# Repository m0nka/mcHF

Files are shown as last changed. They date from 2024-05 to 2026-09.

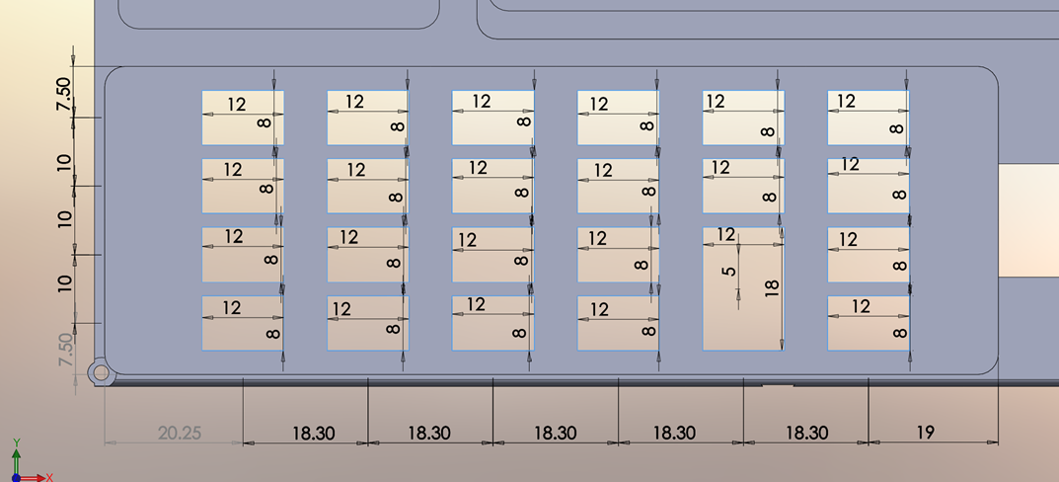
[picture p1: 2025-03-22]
mechanical/keypad/holder.png

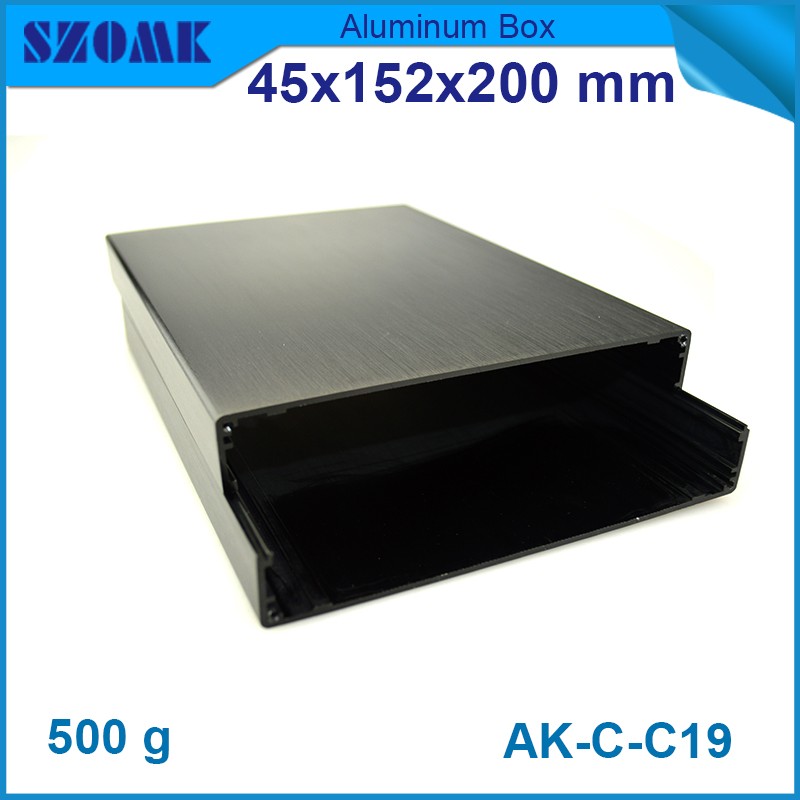
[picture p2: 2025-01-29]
mechanical/case/AK-C-C19/HTB1DIIQLXXXXXXDXXXXq6xXFXXXQ.jpg

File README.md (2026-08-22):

# mcHF — Open Source HF SDR Transceiver




The mcHF is a fully open source software defined radio transceiver for the HF amateur bands (3–30 MHz). Its goal is planet-wide, off-grid communication — ionosphere permitting — with no dependence on cellular or satellite infrastructure.

Both hardware and firmware build on the work of many radio amateurs. The design is modular, uses mostly off-the-shelf components that can be soldered by hand, and is straightforward to repair when something goes wrong. An amateur radio licence is required to transmit.

mcHF demonstration video (https://www.youtube.com/watch?v=7Q5eKNbZNY8)

## Features

- Transmit and receive on the 3–30 MHz amateur bands
- SSB, AM, FM and CW modes
- FT8 and WSPR digital mode decoding (in development)
- Real-time spectrum scope and waterfall
- Large 4.3" IPS LCD with capacitive touch
- 25 W output power
- Built-in 80 Wh lithium battery
- Dual USB-C ports for power, charging and PC connection
- Bluetooth stereo headphone support
- LoRa sub-GHz auxiliary radio

## Hardware

The radio is built around an STM32H747BIT6 dual-core MCU: the Cortex-M7 (480 MHz) runs the user interface and system control, while the Cortex-M4 handles the real-time DSP (demodulation, AGC, filtering, spectrum FFT).

### Altium PCB project files

| Status  | Version | Location |
|---|---|---|
| Latest  | 0.9 rev B  | [pcb/v9](./pcb/v9) |
| Develop | 0.8.5 | [pcb/v8/mchf](./pcb/v8/mchf) |
| Legacy  | 0.6.3 | [pcb/__legacy/v6](./pcb/__legacy/v6) |

### PCB gerbers

| Revision | Version | Location |
|---|---|---|
| rev 8 | 0.8.5 | [testing/gerbers/0_8_5](./testing/gerbers/0_8_5) |
| rev 7 | 0.7.0 | [pcb/__legacy/bin/v7](./pcb/__legacy/bin/v7) |
| rev 6 | 0.6.3 | [pcb/__legacy/bin/v6](./pcb/__legacy/bin/v6) |

## Repository layout

| Directory | Contents |
|---|---|
| [firmware](./firmware) | All firmware projects (see below) |
| [pcb](./pcb) | Altium PCB projects and gerbers |
| [mechanical](./mechanical) | Enclosure and mechanical design files |
| [testing](./testing) | Test data and manufacturing files |

## Building the firmware

The firmware is developed with [STM32CubeIDE](https://www.st.com/en/development-tools/stm32cubeide.html) (Eclipse CDT managed build — no separate Makefiles).

Clone with submodules (the ST HAL and the FT8 library are pulled in as git submodules):

```
git clone --recurse-submodules https://github.com/m0nka/mcHF.git
```

There are three independent firmware projects, each opened separately in STM32CubeIDE:

| Project | Core | Location |
|---|---|---|
| Application processor (UI, control) | CM7 | [firmware/app_proc/proj](./firmware/app_proc/proj) |
| Baseband DSP | CM4 | [firmware/baseband](./firmware/baseband) |
| Bootloader | CM7 | [firmware/bootloader](./firmware/bootloader) |

Open the project's `.project` file in STM32CubeIDE and use *Build → Build Project*. The application processor build produces `firmware/app_proc/proj/Release/mchf_app_proc.bin`, which can be flashed over SWD with `program_radio.bat` (requires STM32CubeProgrammer).

## Previous hardware generations

Older mcHF hardware versions are supported by the community-maintained UHSDR firmware:

- Firmware repository: [df8oe/UHSDR](https://github.com/df8oe/UHSDR)
- Project crash course and documentation: [UHSDR wiki](https://github.com/df8oe/UHSDR/wiki)

## Community and contributing

Questions, build reports and development discussion are welcome in the [mcHF discussion group](https://groups.io/g/mcHF/).

Feel free to build one yourself and contribute — bug reports, fixes and improvements to hardware, firmware or documentation are all appreciated.

## License

mcHF is licensed under the [GNU General Public License v3.0](LICENSE).

Copyright © 2013–2026 Krassi Atanassov, M0NKA

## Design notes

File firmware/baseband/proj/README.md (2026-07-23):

Introduction 

This directory contains the STM32CubeIDE project (mchf_baseband) for the CM4 baseband core,
based on the UHSDR firmware (sources in firmware/baseband)

Import into STM32CubeIDE

- In the File menu, select 'Open Projects from File System...'
- Select root directory: "firmware\baseband\proj", 'Detect and configure project natures' selected
- Click Finish

Note: SystemWorks no longer supported!

Troubleshooting

- Fix for functions with wrong inline definition - use optimization (O1 at least), more info:
	https://stackoverflow.com/questions/41218006/gcc-fails-to-inline-functions-without-o2

For any problems compiling under windows please open an issue report on the project GitHub page.

Thank you!

Krassi Atanassov, M0NKA

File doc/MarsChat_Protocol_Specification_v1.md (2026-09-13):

# MarsChat — On-Air Protocol Specification

**Version:** 1.0  
**Date:** 30 August 2026  
**Author:** Krassi Atanassov, M0NKA  
**Platform:** mcHF QRP Transceiver v9  
**Licence:** GPLv3  
**Repository:** https://github.com/m0nka/mcHF

---

## 1. Purpose and Regulatory Notice

MarsChat is a very-slow-baud, text-only digital communication mode for HF
amateur radio, designed for extreme weak-signal messaging over ionospheric
paths. It trades throughput for reach: a single text character takes
approximately 24 seconds of on-air time, but the link closes at signal-to-noise
ratios of **−28 dB or better** in a 2500 Hz reference bandwidth — well below
the noise floor, where voice and conventional digital modes cannot operate.

This document is published in compliance with amateur radio practice that
requires open documentation of new on-air modes, enabling any station to decode
MarsChat transmissions. **No encryption is used in amateur (ham) mode.** The
on-air modulation is standard WSPR; only the interpretation of the 50
information bits differs.

The name "MarsChat" refers to the multi-minute message turnaround inherent to
the mode, reminiscent of Earth–Mars radio dialogue latency. It is not affiliated
with any space agency or Mars mission.

---

## 2. Overview

MarsChat reuses the **WSPR (Weak Signal Propagation Reporter)** physical layer
without modification. The 4-FSK modulation, convolutional FEC, interleaving,
synchronisation vector and timing are identical to WSPR type-1. Only the meaning
of the **50 information bits** carried within the WSPR frame changes.

This design choice means:
- Any existing WSPR decoder can demodulate MarsChat signals at the RF level.
- The same convolutional code and Fano sequential decoder recovers the 50 raw
  bits from noise.
- MarsChat then applies its own frame interpretation (described in §4–§8) to
  those 50 bits.

**Throughput:** 5 characters per 120-second slot, or approximately 0.42 bits
per second. A whole canned phrase can be transmitted in a single slot via the
phrase lookup table (§7.2).

---

## 3. Physical Layer (WSPR, Unchanged)

All PHY parameters are standard WSPR type-1 as defined by Joe Taylor, K1JT.

| Parameter | Value |
|---|---|
| Modulation | 4-FSK, continuous phase |
| Number of symbols | 162 |
| Symbol rate | 12000 / 8192 ≈ 1.46484375 baud |
| Tone spacing | 375 / 256 ≈ 1.46484375 Hz |
| Occupied bandwidth | ≈ 6 Hz |
| Transmission duration | 162 × 8192 / 12000 ≈ 110.6 seconds |
| Slot period | 120 seconds, aligned to even UTC minutes |
| TX start | Slot boundary + 1.0 second |
| Audio centre frequency | Dial frequency + 1500 Hz (USB) |
| FEC | K = 32, rate = 1/2, non-recursive convolutional code |
| Sequential decoder | Fano algorithm |
| Interleaving | Bit-reversal permutation over 256 indices |
| Sync vector | Standard WSPR 162-bit pseudo-random sequence |
| Information payload | **50 bits** |

### 3.1 Encoding Chain (Transmit)

```
50 information bits
  → append 31 zero tail bits (flush the K = 32 shift register) = 81 bits
  → K = 32, r = 1/2 convolutional encode = 162 coded bits
      polynomials: G1 = 0xF2D05351, G2 = 0xE4613C47
      convention:  MSB-first feed, coded bit = even parity of (state AND poly)
  → bit-reversal interleave over 256 indices (skip indices ≥ 162)
  → channel symbol[k] = sync_vector[k] + 2 × coded_bit[k]
  → 162 four-level symbols (values 0, 1, 2, 3)
  → 4-FSK audio: tone[k] = 1500 + (symbol[k] − 1.5) × 1.46484375 Hz
```

### 3.2 Decoding Chain (Receive)

Standard WSPR decoding: FFT search → candidate detection → fine sync →
demodulation → de-interleave → Fano sequential decode → 50 raw bits + SNR,
time offset (dt), frequency, and drift metadata per decode.

### 3.3 Dial Frequencies (Ham Mode)

MarsChat transmissions in ham mode use the standard WSPR dial frequencies (USB
carrier):

| Band | Dial Frequency (Hz) |
|---|---|
| 160 m | 1,836,600 |
| 80 m | 3,568,600 |
| 60 m | 5,287,200 |
| 40 m | 7,038,600 |
| 30 m | 10,138,700 |
| 20 m | 14,095,600 |
| 17 m | 18,104,600 |
| 15 m | 21,094,600 |
| 12 m | 24,924,600 |
| 10 m | 28,124,600 |

The 4-FSK tones are centred at dial + 1500 Hz within the 200 Hz WSPR sub-band.

---

## 4. Frame Format (50 Bits)

The 50 information bits are packed MSB-first into 7 bytes (the low 6 bits of
byte 6 are unused). Bit numbering: `b0` is the MSB of byte 0.

```
 b0    b1..b2   b3..b5   b6..b8   b9..b11   b12..b41      b42..b49
┌────┬────────┬────────┬────────┬─────────┬─────────────┬──────────┐
│ MC │ FTYPE  │  SEQ   │  ACK   │  FLAGS  │  PAYLOAD    │  CRC-8   │
│ =1 │ 2 bits │ 3 bits │ 3 bits │ 3 bits  │  30 bits    │  8 bits  │
└────┴────────┴────────┴────────┴─────────┴─────────────┴──────────┘

Total: 1 + 2 + 3 + 3 + 3 + 30 + 8 = 50 bits
```

### 4.1 Field Definitions

| Field | Width | Description |
|---|---|---|
| `MC` | 1 bit | MarsChat marker. Always **1**. Used for frame discrimination (§5). |
| `FTYPE` | 2 bits | Frame type: 0 = BEACON, 1 = DATA, 2 = ACK, 3 = CTRL |
| `SEQ` | 3 bits | Frame sequence number, modulo 8 |
| `ACK` | 3 bits | Sequence number of the last correctly received peer frame. 0 if not applicable |
| `FLAGS` | 3 bits | Bit field: bit 0 = `OTP` (encrypted, non-amateur only), bit 1 = `MF` (more fragments follow), bit 2 = `CYR` (Cyrillic rendering hint) |
| `PAYLOAD` | 30 bits | 5 × 6-bit character codes (§7), or type-specific content (§6) |
| `CRC` | 8 bits | CRC-8 integrity check over b0..b41 (§4.2) |

### 4.2 Bit Packing (Byte Layout)

The bit-to-byte mapping, as implemented:

```
byte 0:  b0=MC(1)  b1-b2=FTYPE  b3-b5=SEQ  b6-b7=ACK[2:1]
byte 1:  b8=ACK[0]  b9=OTP  b10=MF  b11=CYR  b12-b15=PAYLOAD_CODE0[5:2]
byte 2:  b16-b17=PAYLOAD_CODE0[1:0]  b18-b23=PAYLOAD_CODE1[5:0]
byte 3:  b24-b29=PAYLOAD_CODE2[5:0]  b30-b31=PAYLOAD_CODE3[5:4]
byte 4:  b32-b35=PAYLOAD_CODE3[3:0]  b36-b37=PAYLOAD_CODE4[5:4]  (note: only top 2 bits)
         (correction: b32-b35=CODE3[3:0]  b36-b39=CODE4[5:2])
byte 5:  b40-b41=PAYLOAD_CODE4[1:0]  b42-b47=CRC[7:2]
byte 6:  b48-b49=CRC[1:0]  b50-b55=unused(0)
```

Precise implementation (C, canonical reference):

```c
// Pack
bits50[0] = 0x80
          | ((ftype & 0x03) << 5)
          | ((seq   & 0x07) << 2)
          | ((ack   & 0x07) >> 1);

bits50[1] = ((ack   & 0x01) << 7)
          | ((flags & 0x01) ? 0x40 : 0)   // OTP
          | ((flags & 0x02) ? 0x20 : 0)   // MF
          | ((flags & 0x04) ? 0x10 : 0)   // CYR
          | ((codes[0] & 0x3F) >> 2);

bits50[2] = ((codes[0] & 0x03) << 6) | (codes[1] & 0x3F);
bits50[3] = ((codes[2] & 0x3F) << 2) | ((codes[3] & 0x3F) >> 4);
bits50[4] = ((codes[3] & 0x0F) << 4) | ((codes[4] & 0x3F) >> 2);
bits50[5] = ((codes[4] & 0x03) << 6);

// CRC-8 over b0..b41 (bytes 0..5, with byte 5 low 6 bits masked to 0)
crc = crc8_autosar(bits50[0..4], bits50[5] & 0xC0);

bits50[5] |= (crc >> 2);
bits50[6]  = (crc & 0x03) << 6;
```

---

## 5. Frame Discrimination (MarsChat vs WSPR)

A receiver that supports both WSPR and MarsChat classifies each raw 50-bit
decode as follows:

1. If bit `b0` (MSB of byte 0) is **1** AND the MarsChat CRC-8 (§4.3)
   verifies → interpret as a **MarsChat** frame.
2. Otherwise → attempt standard WSPR type-1 unpack (callsign + grid + power).

**False classification probability** of a genuine WSPR spot as MarsChat: the
WSPR type-1 callsign encoding uses the MSB for the first character of the
padded callsign. Approximately half of valid WSPR messages will have `b0 = 1`,
but the CRC-8 must also pass (probability ≈ 1/256), giving an overall false
positive rate of approximately **2⁻⁹ ≈ 0.2%**. This is acceptable at typical
WSPR decode rates.

A MarsChat frame is never a valid WSPR type-1 message by construction
(probabilistically — the callsign decode would be nonsensical).

---

## 6. CRC-8

**Algorithm:** CRC-8/AUTOSAR

| Parameter | Value |
|---|---|
| Polynomial | 0x2F (x⁸ + x⁵ + x³ + x² + x + 1) |
| Initial value | 0xFF |
| Final XOR | 0xFF |
| Input reflection | No |
| Output reflection | No |

**Scope:** The CRC is computed over bits `b0` through `b41` of the frame
(the MC marker, FTYPE, SEQ, ACK, FLAGS and PAYLOAD fields). The input is
packed MSB-first into 6 bytes; the last byte contains `b40` and `b41` in
its two MSBs with the low 6 bits forced to zero.

**Verification:** A receiver computes the CRC over the same 6-byte span and
compares it against the received CRC in bits `b42..b49`. Mismatch means the
frame is not a valid MarsChat frame and should be tested as WSPR type-1.

**Reference implementation** (C):

```c
uint8_t mc_crc8(const uint8_t *data, int len)
{
    uint8_t crc = 0xFF;
    int     i, b;

    for (i = 0; i < len; i++)
    {
        crc ^= data[i];

        for (b = 0; b < 8; b++)
        {
            if (crc & 0x80)
                crc = (uint8_t)((crc << 1) ^ 0x2F);
            else
                crc = (uint8_t)(crc << 1);
        }
    }

    return crc ^ 0xFF;
}
```

**Test vectors:**

| Input (hex) | CRC-8 |
|---|---|
| `00` | 0x12 |
| `FF` | 0xC2 |
| `00 00 00 00 00 00` (6 bytes) | (implementation-defined, verify against reference) |

---

## 7. Character Set and Phrase Lookup Table

### 7.1 Six-Bit Character Set (Latin Page)

All text is case-insensitive (uppercase only), consistent with CW and digital
mode convention. Each character is encoded as a 6-bit value (0–63). Five
characters fit in the 30-bit payload field.

| Code | Character | Code | Character | Code | Character | Code | Character |
|---|---|---|---|---|---|---|---|
| 0 | END (pad) | 16 | P | 32 | 5 | 48 | ' (apostrophe) |
| 1 | A | 17 | Q | 33 | 6 | 49 | ( |
| 2 | B | 18 | R | 34 | 7 | 50 | ) |
| 3 | C | 19 | S | 35 | 8 | 51 | " (double quote) |
| 4 | D | 20 | T | 36 | 9 | 52 | # |
| 5 | E | 21 | U | 37 | SPACE | 53 | $ |
| 6 | F | 22 | V | 38 | . (period) | 54 | % |
| 7 | G | 23 | W | 39 | , (comma) | 55 | & |
| 8 | H | 24 | X | 40 | ? | 56 | * |
| 9 | I | 25 | Y | 41 | ! | 57 | ; |
| 10 | J | 26 | Z | 42 | / | 58 | < |
| 11 | K | 27 | 0 | 43 | - (hyphen) | 59 | > |
| 12 | L | 28 | 1 | 44 | + | 60 | (reserved) |
| 13 | M | 29 | 2 | 45 | = | 61 | SHIFT (reserved) |
| 14 | N | 30 | 3 | 46 | @ | 62 | ESC |
| 15 | O | 31 | 4 | 47 | : (colon) | 63 | (reserved) |

**Special codes:**

- **Code 0 (END):** Terminates text early within a fragment. Remaining
  positions are padding (filled with 0) and are excluded from display.
- **Code 62 (ESC):** The next 6-bit code is a phrase lookup table index (§7.2).
- **Code 63:** Reserved for future protocol version escape. If code 63 appears
  as the **first** payload code in a cleartext frame, v1 receivers must discard
  the frame.
- **Code 61 (SHIFT):** Reserved for future mixed-script support.

### 7.2 Phrase Lookup Table (ESC Expansion)

Code 62 (`ESC`) followed by a phrase index (0–15) expands to a complete phrase,
allowing an entire sentence to be sent in a single 120-second slot. This table
is versioned with this protocol specification — both stations must run the same
version (no on-air LUT negotiation in v1).

| Index | Expansion | Index | Expansion |
|---|---|---|---|
| 0 | HEY | 8 | YES |
| 1 | HOW COPY? | 9 | NO |
| 2 | GOING OFF AIR | 10 | STANDBY |
| 3 | SIGNAL WEAK | 11 | MOVING FREQ |
| 4 | SIGNAL STRONG | 12 | SEND AGAIN |
| 5 | ALL OK | 13 | INTERFERENCE HERE |
| 6 | NEED HELP | 14 | BACK IN 1 HOUR |
| 7 | LOCATION UNCHANGED | 15 | BACK TOMORROW SAME TIME |

Indices 16–63 are reserved; receivers must ignore unknown indices.

**Example:** The payload codes `[62, 2, 0, 0, 0]` decode as "GOING OFF AIR"
(ESC + index 2, followed by END padding).

**Effective throughput:** Plain text delivers 5 characters per 2-minute slot.
With phrase LUT, a whole sentence fits in one slot.

### 7.3 Cyrillic Rendering Page (FLAGS.CYR)

When `FLAGS` bit 2 (`CYR`) is set to 1, the **same on-air codes** are displayed
using Cyrillic glyphs instead of Latin. This is a pure rendering hint — the
encoding, CRC, LUT mechanics and everything else are identical. The mapping
follows the traditional **Bulgarian Phonetic keyboard layout:**

| Code | Latin | Cyrillic | Code | Latin | Cyrillic | Code | Latin | Cyrillic |
|---|---|---|---|---|---|---|---|---|
| 1 | A | А | 10 | J | Й | 19 | S | С |
| 2 | B | Б | 11 | K | К | 20 | T | Т |
| 3 | C | Ц | 12 | L | Л | 21 | U | У |
| 4 | D | Д | 13 | M | М | 22 | V | Ж |
| 5 | E | Е | 14 | N | Н | 23 | W | В |
| 6 | F | Ф | 15 | O | О | 24 | X | Ь |
| 7 | G | Г | 16 | P | П | 25 | Y | Ъ |
| 8 | H | Х | 17 | Q | Я | 26 | Z | З |
| 9 | I | И | 18 | R | Р | | | |

Four additional Bulgarian letters overlay punctuation codes when `CYR = 1`:

| Code | Latin Page | Cyrillic Page |
|---|---|---|
| 52 | # | Ч |
| 53 | $ | Ш |
| 54 | % | Щ |
| 55 | & | Ю |

This covers the full 30-letter Bulgarian alphabet. Digits, space and all other
punctuation codes are unchanged on both pages.

`CYR` is per-frame: every fragment of a multi-frame message carries its own
rendering hint, so a lost fragment cannot flip the rendering of later ones.

---

## 8. Frame Types and Payload Semantics

### 8.1 BEACON (FTYPE = 0)

One-way text transmission, no session or ARQ. Used for beacons and initial
testing.

- `SEQ` increments per transmitted frame (modulo 8).
- `ACK` = 0 (not applicable).
- `PAYLOAD` = 5 six-bit character codes (§7.1).
- Multi-frame text uses `FLAGS.MF = 1` and `SEQ` ordering. The receiver
  concatenates fragments until a frame with `MF = 0` arrives.
- Lost fragments are rendered as placeholder gaps (no retry mechanism).

### 8.2 DATA (FTYPE = 1)

Text with ARQ (Automatic Repeat reQuest) semantics (§9).

- Same text payload as BEACON.
- `ACK` carries the `SEQ` of the last correctly received peer frame,
  acknowledging it.
- Un-acknowledged frames are retried in the sender's next slot (§9).

### 8.3 ACK (FTYPE = 2)

Keep-alive frame when no text is pending. Maintains the link and reports
receive-side signal quality:

```
PAYLOAD (30 bits):
  [ snr + 32  : 6 bits ]   SNR in dB, clamped to −32..+31
  [ |dt| × 4  : 6 bits ]   time offset magnitude in seconds × 4, clamped 0..15.75
  [ drift + 32 : 6 bits ]  frequency drift in Hz × 10, clamped
  [ reserved   : 12 bits ]  set to 0
```

This gives each station propagation feedback for manual (or future scripted)
band and power decisions.

### 8.4 CTRL (FTYPE = 3)

Control frames for protocol signalling:

```
PAYLOAD (30 bits):
  [ opcode : 6 bits ]
  [ arg    : 24 bits ]
```

| Opcode | Name | Argument |
|---|---|---|
| 0 | PING | Echo token (24 bits) |
| 1 | TIME_SYNC | Sender's slot index, low 24 bits |
| 2 | OTP_SYNC | OTP counter, low 24 bits (non-amateur mode only) |
| 3 | SCRIPT_NEXT | Reserved for frequency hopping scripts |
| 4–63 | (reserved) | Receivers must ignore unknown opcodes |

---

## 9. ARQ Protocol (Stop-and-Wait)

The ARQ protocol applies to DATA, ACK and CTRL frame types. BEACON frames are
fire-and-forget.

### 9.1 Slot Ownership

Stations alternate 120-second slots. The **slot index** is defined as:

```
slot_index = floor(UTC_minutes / 2)
```

The station initiating the chat ("caller") owns **even** slot indices; the peer
owns **odd** slot indices. A station transmits only in its own slots and listens
only in the peer's slots. An hour contains 30 slots (even count), so the
alternation runs unbroken across hour boundaries.

### 9.2 Stop-and-Wait Operation

- Each side has **at most one un-acknowledged frame** in flight at a time.
- A frame is retried in the sender's next own slot (same SEQ, identical
  on-air bits) until an `ACK` field acknowledging that SEQ is received.
- **Retry limit:** 5 transmissions. After 5 unacknowledged attempts, the frame
  is dropped and the application is notified.
- **Sequence space:** Modulo 8 with a window of 1. SEQ also orders fragments
  for multi-frame message reassembly.

### 9.3 Idle Behaviour

When a station in an active session has nothing to send, it transmits ACK
frames (FTYPE = 2) in its own slots as keep-alives with link quality reports.

### 9.4 Session Loss

The session is considered lost after **5 consecutive empty peer slots** (no
decoded frame from the peer in 5 listening opportunities ≈ 20 minutes of
silence).

### 9.5 Timing

| Event | Timing |
|---|---|
| Best case, single 5-char message | 4 minutes (TX slot + peer ACK slot) |
| Multi-fragment sentence with a retry | 10–20 minutes |
| Maximum silence before session loss | ≈ 20 minutes (5 × 4-minute cycles) |

---

## 10. Time Synchronisation

Frames must start at even-minute boundaries + 1.0 second, within approximately
±2 seconds (the decoder's time-offset search window).

### 10.1 Preferred Synchronisation Methods (in order)

1. **GPS time fix:** Power the GPS receiver at session start, take an NMEA time
   fix, set the slot epoch, and power the GPS down to save battery. Cold-fix
   time is acceptable given the 2-minute slot cadence.

2. **TCXO free-run:** Between GPS fixes, slot phase is maintained by a timer
   derived from the 25 MHz TCXO domain. At ±2.5 ppm the ±2 s window holds
   for approximately 9 days; at ±25 ppm, for approximately 22 hours.

3. **On-air lock (no GPS):** The un-synced station receives continuously. Each
   decoded frame yields a time offset `dt`. The station steps its slot clock by
   `−dt` and confirms slot-index parity with a `CTRL TIME_SYNC` exchange.
   Subsequent decodes continuously re-trim the phase — at 2-minute intervals,
   even 25 ppm mutual drift moves `dt` by only ≈ 6 ms per slot.

### 10.2 Frequency Accuracy

The TCXO also determines dial frequency accuracy. At 14 MHz, ±25 ppm is
±350 Hz — outside the decoder's ±110 Hz search window. Mitigations:

1. One-time calibration against a known WSPR station (free frequency reference
   on air) or a GPS-disciplined counter.
2. For first contact between uncalibrated radios, widen the RX search window
   and apply the measured offset as a correction factor.

---

## 11. Station Identification (Ham Mode)

Because the MarsChat payload is not standard WSPR, transmissions must carry
station identification to remain identifiable and legal on amateur bands.

**CW ID:** After the 162-symbol 4-FSK transmission ends at approximately
111.6 seconds into the 120-second slot, the station's callsign is keyed in
Morse code (CW) at ≥ 20 WPM in the remaining ≈ 8-second gap. The CW is sent
at the same dial frequency and at no higher power than the data transmission.

- A 6-character callsign at 25 WPM takes approximately 5 seconds.
- **If no callsign is configured, ham-mode TX is refused** — the radio will not
  key without a valid callsign.

### 11.1 CW Timing

Standard International Morse timing:

| Element | Duration |
|---|---|
| Dot | 1 unit |
| Dash | 3 units |
| Inter-element gap | 1 unit |
| Inter-character gap | 3 units |
| 1 unit at 25 WPM | 1.2 / 25 = 48 ms |

The CW tone is keyed at the same audio frequency as the data tones (≈ 1500 Hz)
with 5 ms raised-cosine envelope edges to minimise key clicks.

---

## 12. Protocol Versioning

Protocol version 1 is defined by the `MC` marker bit being 1. Future versions
use an in-band escape: if character code 63 appears as the **first** payload
code in a cleartext frame, the frame uses a future extended format. Version 1
receivers **must discard** such frames.

---

## 13. Decoding a MarsChat Frame — Step by Step

This section provides a complete procedure for decoding a MarsChat transmission,
suitable for independent implementation.

### Step 1: Receive and Demodulate

Tune to a WSPR dial frequency (§3.3), mode USB. Run a standard WSPR decoder on
the audio to recover the 50 raw information bits (packed as 7 bytes, MSB-first).
Any WSPR decoder that exposes the raw 50-bit payload before type-1 callsign
interpretation is suitable.

### Step 2: Frame Discrimination

1. Check bit `b0` (MSB of byte 0). If `b0 = 0`, this is not a MarsChat frame —
   pass it to the WSPR type-1 unpacker.
2. Compute CRC-8/AUTOSAR (§6) over bits `b0..b41` (bytes 0–5, with byte 5 low
   6 bits masked to 0).
3. Extract the received CRC from bits `b42..b49`:
   `crc_rx = ((byte5 & 0x3F) << 2) | ((byte6 >> 6) & 0x03)`
4. If `crc_rx ≠ crc_computed`, this is not a valid MarsChat frame — try WSPR.

### Step 3: Unpack Fields

Extract the frame fields from the 7-byte array using the bit layout in §4.2.

### Step 4: Decode Text

For BEACON and DATA frames (FTYPE 0 or 1):
1. Interpret the 5 six-bit codes from the PAYLOAD field using the character
   table in §7.1.
2. If `FLAGS.CYR = 1`, use the Cyrillic rendering table in §7.3 instead.
3. If a code is 62 (ESC), the next code is a phrase LUT index — expand it using
   the table in §7.2.
4. If a code is 0 (END), stop — remaining codes are padding.
5. If `FLAGS.MF = 1`, this is one fragment of a longer message — concatenate
   with subsequent frames (ordered by SEQ) until a frame with `MF = 0` arrives.

For ACK frames (FTYPE 2), decode the signal report from the PAYLOAD (§8.3).
For CTRL frames (FTYPE 3), decode the opcode and argument (§8.4).

---

## 14. Encoding a MarsChat Frame — Step by Step

### Step 1: Prepare the Frame

1. Set `MC = 1`.
2. Set `FTYPE` (0–3) for the intended frame type.
3. Set `SEQ` to the current frame sequence number (mod 8).
4. Set `ACK` to the last received peer sequence number (0 if none).
5. Set `FLAGS` as appropriate (`MF` for multi-fragment, `CYR` for Cyrillic).
6. Encode up to 5 text characters into 6-bit codes using §7.1.

### Step 2: Pack and CRC

Pack the fields into 7 bytes per the layout in §4.2. Compute CRC-8 over
bytes 0–5 (with byte 5 low 6 bits masked), and write the CRC into bits
`b42..b49`.

### Step 3: Channel Encode and Transmit

Pass the 7-byte packed frame to the WSPR encoding chain (§3.1) to produce 162
four-level symbols. Transmit as 4-FSK starting at even-minute + 1.0 second.

### Step 4: CW ID (Ham Mode)

After the 162-symbol stream ends (≈ 111.6 s), key the station callsign in CW
at ≥ 20 WPM (§11).

---

## 15. Reference Test Vector

**Input:** The text "HELLO" as a BEACON frame (FTYPE = 0, SEQ = 0, ACK = 0,
FLAGS = 0).

Character encoding:
```
H = 8, E = 5, L = 12, L = 12, O = 15
```

Packed 50-bit frame (7 bytes, hex):
```
MC=1, FTYPE=00, SEQ=000, ACK=000, FLAGS=000
PAYLOAD codes: [8, 5, 12, 12, 15]
CRC-8 computed over b0..b41

Byte-by-byte construction:
  byte 0: 1_00_000_00 = 0x80
  byte 1: 0_0_0_0_0010 = 0x02  (ack[0]=0, OTP=0, MF=0, CYR=0, code0[5:2]=0010)
  byte 2: 00_000101 = 0x05     (code0[1:0]=00, code1=000101)
  byte 3: 001100_00 = 0x30     (code2=001100, code3[5:4]=00)
  byte 4: 1100_0011 = 0xC3     (code3[3:0]=1100, code4[5:2]=0011)
  byte 5: 11_xxxxxx = 0xC0 | crc_high  (code4[1:0]=11, then CRC bits)
  byte 6: xx_000000 = crc_low << 6

Pre-CRC bytes: 80 02 05 30 C3 C0
CRC-8/AUTOSAR of [80 02 05 30 C3 C0] = (compute to verify)
```

Implementers should compute the CRC-8 of the byte sequence `[0x80, 0x02, 0x05,
0x30, 0xC3, 0xC0]` using the algorithm in §6 and verify it matches the bits
placed in `b42..b49` of the complete frame. This serves as the primary
interoperability test: if your encoder produces the same 7 bytes for "HELLO"
as the reference, and your decoder recovers "HELLO" from them, the
implementation is correct.

---

## 16. Glossary

| Term | Definition |
|---|---|
| ARQ | Automatic Repeat reQuest — error correction by retransmission |
| CW | Continuous Wave — Morse code |
| dt | Time offset of a decoded frame relative to the expected slot start |
| Fano | Sequential decoding algorithm used by WSPR |
| FEC | Forward Error Correction |
| FSK | Frequency Shift Keying |
| LUT | Lookup Table |
| MF | More Fragments (flag indicating a multi-frame message continues) |
| OTP | One-Time Pad (non-amateur mode only) |
| PHY | Physical layer |
| SEQ | Sequence number |
| Slot | One 120-second transmission/reception period |
| SNR | Signal-to-Noise Ratio |
| TCXO | Temperature-Compensated Crystal Oscillator |
| USB | Upper Side Band |
| WSPR | Weak Signal Propagation Reporter |

---

## 17. References

1. K1JT, J. Taylor, "The WSPR Protocol," 2008.
   https://www.physics.princeton.edu/pulsar/k1jt/wspr.html
2. K9AN, S. Franke, "wsprd — WSPR decoder," part of WSJT-X.
   https://sourceforge.net/projects/wsjt/
3. mcHF SDR Transceiver project.
   https://github.com/m0nka/mcHF
4. CRC-8/AUTOSAR specification.
   Polynomial 0x2F, per AUTOSAR E2E Profile 2.

---

*This document is published under the GNU General Public License v3.0 to
satisfy the amateur radio community requirement that new digital modes be
openly documented. Anyone may implement a MarsChat encoder or decoder using this
specification.*

*Document revision history:*

| Version | Date | Changes |
|---|---|---|
| 1.0 | 2026-08-30 | Initial public release |

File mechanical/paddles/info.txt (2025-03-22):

Notes: As we don't have solidworks files for both files from the original author, we kinda
reuse them as it is, and made the right panel enclosure accomodate the existing design.

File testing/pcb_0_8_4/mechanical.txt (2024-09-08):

- fan cap to have redirect holes to cool batteries during charge( < 10% of flow)

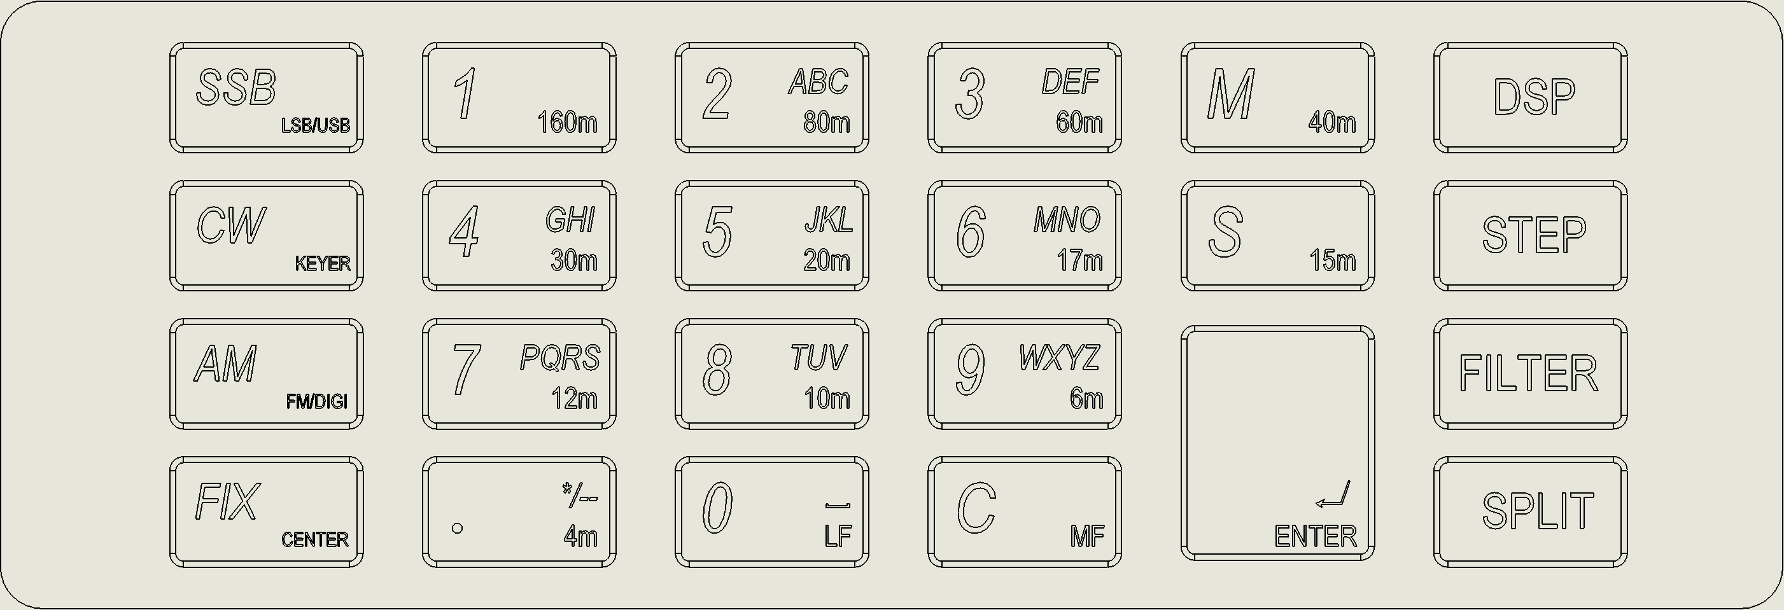
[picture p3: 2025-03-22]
mechanical/keypad/img/keypad.png

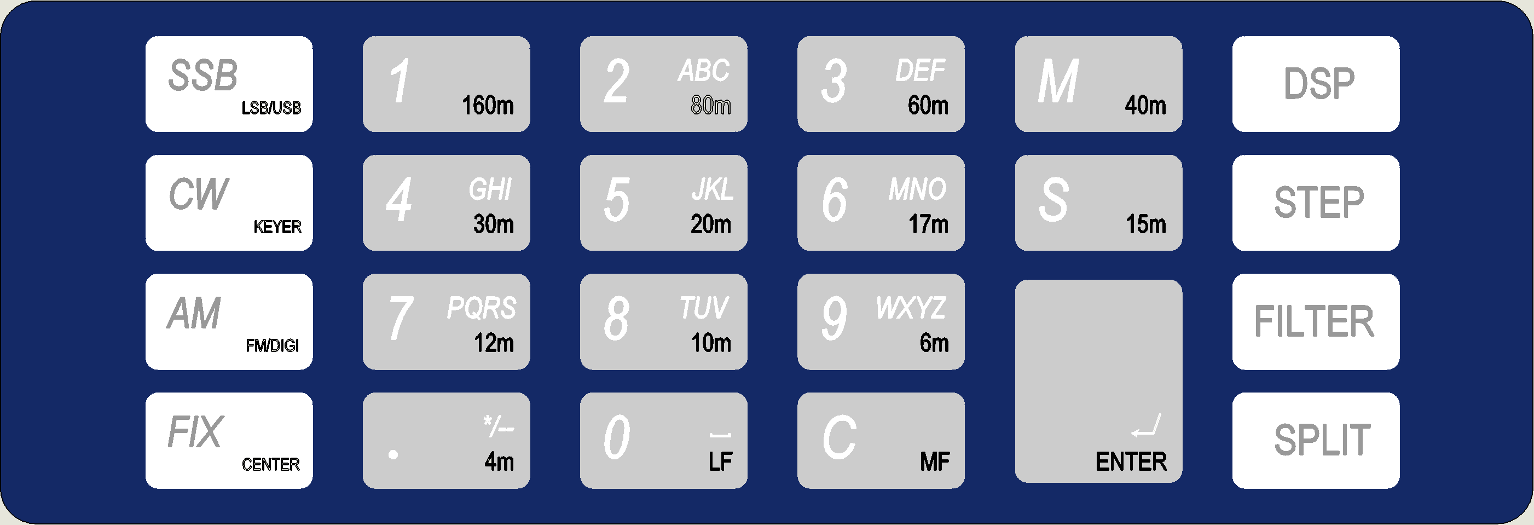
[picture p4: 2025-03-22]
mechanical/keypad/img/keypad_coloured.png

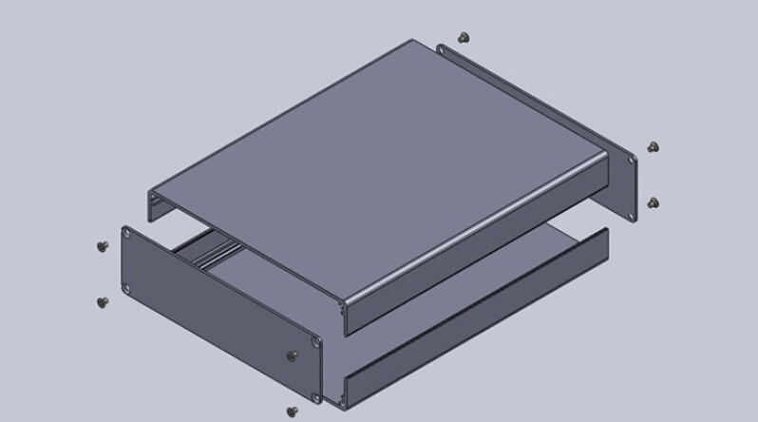
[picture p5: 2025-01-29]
mechanical/case/AK-C-C19/HTB1XbpVLFXXXXXKXVXXq6xXFXXXg.jpg

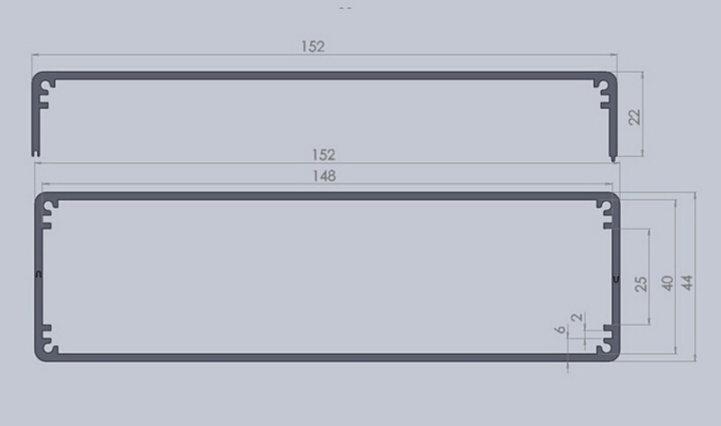
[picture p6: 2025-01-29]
mechanical/case/AK-C-C19/HTB1jtJVLFXXXXXpXVXXq6xXFXXXK.jpg

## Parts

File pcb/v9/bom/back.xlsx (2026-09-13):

Comment | Quantity | Designator | Footprint | Notes | Voltage | Order | Description
LiOn 5S 21700 | 1 | BH1 | BATT_HOLDER_5S |  |  |  | LiOn 21700 5S Holder
100nF | 46 | C1, C2, C3, C4, C5, C6, C9, C10, C11, C12, C13, C42, C54, C55, C56, C61, C64, C66, C70, C71, C72, C76, C77, C81, C82, C86, C87, C88, C89, C92, C93, C94, C95, C96, C97, C98, C99, C101, C102, C104, C105, C106, C108, C109, C110, C111 | 0805 |  | 100V, [NoParam] | [NoValue], FN 185-6408, FN 252-2090 | Capacitor
100pF | 2 | C7, C8 | 0805 |  | 100V |  | Capacitor
22uF | 10 | C19, C73, C75, C78, C80, C83, C85, C100, C103, C107 | 1206_Elec_Cap |  | 25V, 16V |  | Electrolitic capacitor
10uF | 4 | C20, C21, C40, C112 | 0805 |  | 100V, [NoParam] |  | Capacitor
T521D336M035ATE065 | 3 | C22, C23, C36 | 0805 |  |  |  | CAP, CERM, 0.01 uF, 25 V, +/- 10%, X7R, 0603
Capacitor | 13 | C24, C26, C30, C31, C34, C35, C37, C38, C43, C44, C45, C46, C47 | 0805 |  |  |  | CAP, CERM, 1000 pF, 25 V, +/- 5%, X7R, 0402, CAP, CERM, 0.047 uF, 25 V, +/- 10%, X7R, 0603, CAP, CERM, 100 pF, 50 V, +/- 5%, C0G/NP0, 0603, CAP, CERM, 1 uF, 25 V, +/- 10%, X7R, 0603, CAP, CERM, 150 pF, 50 V, +/- 5%, C0G/NP0, 0603, CAP, CERM, 10 uF, 25 V, +/- 20%, X5R, 0603, CAP, CERM, 2.2 uF, 35 V, +/- 10%, X5R, 0603, CAP, CERM, 680 pF, 50 V, +/- 5%, C0G/NP0, 0402, CAP, CERM, 15 pF, 50 V, +/- 5%, C0G/NP0, 0402
885012005062 | 1 | C25 | 0805 |  |  |  | CAP, CERM, 150 pF, 50 V,+/- 5%, C0G/NP0, 0402
33nF | 2 | C27, C28 | 0805 |  | 100V |  | Capacitor
C1608X5R1H474K080AB | 1 | C29 | 0805 |  |  |  | CAP, CERM, 0.47 uF, 50 V, +/- 10%, X5R, 0603
33pF | 1 | C32 | 0805 |  | 100V |  | Capacitor
885012205029 | 1 | C33 | 0805 |  |  |  | CAP, CERM, 4700 pF, 16 V,+/- 10%, X7R, 0402
Capacitor | 2 | C39, C41 | 1206_Elec_Cap |  |  |  | CAP, TA, 33 uF, 35 V, +/- 20%, 0.065 ohm, SMD
1nF | 6 | C50, C51, C57, C58, C62, C63 | 0805 |  |  | FN 185-6408, [NoValue] | Capacitor
220uF | 2 | C52, C53 | CAP_ALUM_Pro | [NoParam], Aluminium capacitor |  | FN 225-4321, [NoValue] | Electrolitic capacitor
100nF | 1 | C59 | 0805-Pro |  |  | FN 174-0673 | Capacitor
2.2uF | 4 | C60, C65, C90, C91 | 0805 |  |  |  | 0603 X5R 1礔, Capacitor
SS24 | 1 | D1 | DO214 |  |  |  | DIODE, SCHOTTKY, 1A, 60V, SOD-123F
PMEG6010CEH | 5 | D2, D3, D4, D7, D8 | SOD87 |  |  | DK 1N5711W-FDITR-ND, [NoValue] | RF DIODE SCHOTTKY 70V, SOD-123F, DIODE, SCHOTTKY, 1A, 60V, SOD-123F
1N5711W-7-F | 2 | D5, D6 | SOD87 |  |  | DK 1N5711W-FDITR-ND | RF DIODE SCHOTTKY 70V, SOD-123F
16/30HB | 2 | DS1, DS2 | SIP2 |  |  | FN 113-9250 | NEON LAMP, WIRE ENDED, T2
Frequency | 1 | E1 | Encoder |  |  |  | ALPS Rotary Encoder, ALPS-EC12E2420404
Multi/Vol | 1 | E2 | Encoder |  |  |  | ALPS Rotary Encoder, ALPS-EC12E2420404
MC12CT | 2 | F1, F2 | 1206 |  |  |  | Fuse
RD16HHF1x2 | 1 | HS1 | TO-220_5_DUAL_HS |  |  | EB 121171160336 | RF MOSFET x2 heatsink
1337140 | 2 | J1, J3 | 1373866 |  |  |  | SMD male connector, nominal current: 2.2 A, Test voltage: 840 VAC, number of positions: 20, pitch: 1.27 mm, color: black, contact surface: Gold, type of contact: Male connector, mounting: SMD soldering
ACC | 1 | J2 | MX-387GL_new1 | post assembly |  |  | Jack Socket,Thru-Hole
ANT2 | 1 | J4 | CON-SMA-RA |  |  | FN 171-2350 | RF COAXIAL, BNC, JACK
1373826 | 2 | J5, J6 | 1373826 |  |  |  | SMD male connector, nominal current: 2.2 A, Test voltage: 840 VAC, number of positions: 6, pitch: 1.27 mm, color: black, contact surface: Gold, type of contact: Male connector, mounting: SMD soldering
ANT1 | 1 | J7 | CON-SMA-RA |  |  | FN 171-2350 | RF COAXIAL, BNC, JACK
TX | 1 | J8 | ufl
219320-0001 | 1 | J9 | MOLX_USB |  |  |  | Universal Serial Bus (USB) Shielded I/O Receptacle, Type C, Vertical, Surface Mount, Height 8.8mm, 16 Circuits, Gold (Au) Flash Plating
BMQADY1010404R7MA1 | 1 | L1 | CD75 |  |  |  | 4700nH Shielded Molded Inductor Nonstandard
4.7uH | 6 | L2, L3, L4, RFC2, RFC3, RFC4 | CD75 | Power inductor |  |  | POWER INDUCTOR, 47UH, 1210
0 | 10 | M25, M26, M27, M28, M29, M30, M31, M32, R37, R64 | 0805 |  |  |  | Resistor
10K | 6 | NTC1, R43, R53, R57, R61, R87 | 0805 |  |  | [NoValue], FN 146-9929 | Resistor
Fan | 1 | P1 | MHDR1X2_m |  |  |  | Header, 2-Pin
GPS | 1 | P2 | HDR1X6 |  |  |  | Header, 6-Pin
Header 8H | 1 | P3 | HDR1X8H |  |  |  | Header, 8-Pin, Right Angle
CSD17577Q3A | 6 | Q1, Q2, Q3, Q4, Q5, Q6 | DNH0008A |  |  |  | MOSFET, N-CH, 30 V, 19 A, DNH0008A (VSONP-8)
Transistors P-Mosfet BSC084P03NS3 | 1 | Q7 | PowerFlat 5x6mm |  |  |  | Mosfet P-Channel 30 V 78.6A (Tc) 2.5W (Ta), 69W (Tc) Surface Mount PG-TDSON-8-5
IRLML6244TRPBF | 3 | Q8, Q9, Q10 | SOT-23-Pro |  |  |  | N-Channel MOSFET
100 | 23 | R1, R2, R3, R4, R5, R6, R8, R9, R11, R14, R15, R16, R28, R29, R44, R45, R46, R77, R78, R88, R89, R92, R93 | 0805 | [NoParam], Tolerance better than 1% |  |  | Resistor
0.001 | 1 | R7 | 2512 | Tolerance better than 1% |  | 652-CR2512AF/1R00ELF | Resistor
4.7k | 6 | R10, R12, R42, R48, R63, R65 | 0805 |  |  | [NoValue], FN 146-9929 | Resistor
1k | 9 | R13, R38, R74, R75, R76, R79, R83, R85, R91 | 0805 | [NoParam], Tolerance better than 1% |  |  | Resistor
0.005 | 2 | R20, R30 | 2512 | Tolerance better than 1% |  | 652-CR2512AF/1R00ELF | Resistor
4.7 | 5 | R21, R22, R23, R80, R81 | 0805 |  |  |  | Resistor
10 | 3 | R24, R31, R32 | 0805 |  |  |  | Resistor
383k | 1 | R25 | 0805 |  |  |  | Resistor
220k | 1 | R26 | 0805 |  |  |  | Resistor
40.2k | 1 | R27 | 0805 |  |  |  | Resistor
15k | 2 | R33, R86 | 0805 |  |  |  | Resistor
30.1k | 1 | R34 | 0805 |  |  |  | Resistor
191k | 1 | R35 | 0805 |  |  |  | Resistor
100k | 2 | R36, R50 | 0805 | [NoParam], Tolerance better than 1% |  |  | Resistor
2.2/1206 | 2 | R40, R41 | 1206 |  |  | FN 207-8984 | Resistor
1.5k | 1 | R47 | 0805 |  |  |  | Resistor
560k | 1 | R49 | 0805 | Tolerance better than 1% |  |  | Resistor
30 | 3 | R51, R55, R59 | 0805 |  |  |  | Resistor
56k | 1 | R52 | 0805 |  |  | 71-CRCW08053K30FKEAC | Resistor
2.2k | 6 | R54, R62, R72, R73, R82, R84 | 0805 |  |  |  | Resistor
91k | 1 | R56 | 0805 |  |  | 71-CRCW08053K30FKEAC | Resistor
5.1k | 1 | R58 | 0805 |  |  |  | Resistor
33k | 1 | R60 | 0805 |  |  | 71-CRCW08053K30FKEAC | Resistor
47 | 2 | R70, R71 | 0805 |  |  |  | Resistor
120k | 1 | R90 | 0805 | Tolerance better than 1% |  |  | Resistor
47uH | 1 | RFC1 | BIG_IND | Power inductor |  |  | POWER INDUCTOR, 47UH, 1210
47uH | 4 | RFC5, RFC6, RFC8, RFC9 | 0805 |  |  |  | INDUCTOR, SIGNAL LINE, 47UH, 1005, INDUCTOR, SIGNAL LINE, 4.7UH, 1005
BN43-2402 2T choke | 1 | RFC7 | F_Bead | post assembly |  |  | BN43-2402 1t choke
FAN(manual/auto) | 1 | SW1 | SW3 |  |  | FN 118-1070 | Three pole switch
FT50-43 10:1 ratio | 2 | T1, T2 | SWR_TR _new | post assembly |  |  | SWR Bridge transformer
CX2074NL | 2 | T3, T4 | SOP5_NEW1 |  |  |  | Transformer 4:1
BQ40Z80RSMR | 1 | U1 | QFN40P400X400X100-33N-D |  |  |  | Hardware
BQ25731RSN | 1 | U2 | RSN0032B-MFG |  |  |  | No Description
74HCT02 | 1 | U3 | SO-14 |  |  |  | Quad 2-input NOR gate
24LC1025 | 1 | U4 | SO-8-Pro |  |  | FN 133-1323 | 1K I2C Eeprom
AP22811A | 2 | U5, U7 | SOT25-5 |  |  | FN 274-8550 | High-side switch
LTV-816S | 1 | U6 | SMDIP-4_new1 | v 0.6 RF board opto can do, but more expensive |  | FN 168-3292 | OPTOCOUPLER, SMDIP-4, TR O/P
PE22(900M22S) | 1 | U8 | PE22(900M22S) |  |  |  | Lora Module
TPS56339DDCR | 3 | U9, U10, U11 | SOT25-6 | Originally from Thomas, if not Ali |  | Hotmcu.com | dc/dc
OPA2674 | 1 | U12 | SO-14-PRO |  |  |  | Dual Wideband, High Output Current Operational Amplifier with Current Limit
LM2931CDG | 2 | U13, U14 | SO-8-PRO |  |  |  | 100 mA, Adjustable Output, LDO Voltage Regulator with 60 V Load Dump Protection
CH224A | 1 | U15 | ch224k |  |  | DK 336-2518-ND | USB-PD trigger chip

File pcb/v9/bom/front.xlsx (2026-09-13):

Comment | Quantity | Designator | Footprint | Notes | Voltage | Order | Description
10uF | 7 | C1, C42, C47, C55, CC14E, CC17E, CC18E | 1206_Elec_Cap | [NoParam], Tantalum capacitor |  | FN 233-3009, FN 145-7414, [NoParam] | Electrolitic capacitor, [NoValue]
1uF | 12 | C2, C3, C4, C5, C6, C7, C8, C9, C10, C11, C44, CP44E | 1206_Elec_Cap | Tantalum capacitor, [NoParam] | [NoParam], 50V | FN 145-7406 | Electrolitic capacitor
2.2uF | 15 | C12, C13, C18, C18a, C21y, C27, C27a, C43, CC15, CC16, CP89, CP119E, CP140, CP152, CP199 | 0805 | [NoParam], Ceramic Capacitor, low ESR |  | [NoParam], FN 252-2090, FN 175-9477 | Capacitor, 0603 X5R 1礔, Ceramic Capacitor
100nF | 58 | C14, C15, C15a, C21, C22, C23, C24, C25, C26, C26a, C28, C41, C45, C46, C51, C54, C56, C61, CC5, CC14, CC17, CC18, CC19, CC20, CC30, CC36, CC46, CP7, CP17, CP29, CP44, CP49, CP56, CP74, CP80, CP100, CP108, CP114, CP117, CP119, CP133, CP155, CP161, CP179, CP187, CP208, CR1, CR3, CR9, CR15, CR29, CR35, CR41, CR43, CR49, CR55, CR75, CR81 | 0805 |  |  | FN 252-2090, FN 174-0673, FN 282-1264, [NoParam] | Capacitor
1nF | 28 | C14a, C14b, C14c, C14d, C14g, C14h, C14j, C14k, C14l, C14m, CC7, CC8, CC9, CC10, CC11, CC12, CC21, CC22, CC23, CC24, CC26, CC26a, CC27, CC27a, CC28, CC29, CC33, CC34 | 0805 |  |  | FN 185-6408, [NoValue], [NoParam] | Capacitor
220uF | 4 | C16, C17, C21a, C21b | CAP_ALUM_Pro | Aluminium capacitor, [NoParam] |  | [NoValue], FN 225-4321 | Electrolitic capacitor
100uF | 2 | C19, C20 | CAP_ALUM_Pro | Aluminium capacitor, [NoParam] |  | FN 225-4321 | Electrolitic capacitor
1.5pF | 2 | C32, C33 | 0805 |  |  | FN 756-8401 | Capacitor
18pF | 3 | C48, C49, C50 | 0805 | COG/NPO | 100V |  | Capacitor
47uF | 3 | CC19E, CC20E, CC25 | 1206_Elec_Cap | Tantalum Capacitor, [NoParam] |  |  | Electrolitic capacitor
4.7V | 3 | D1, D2, D3 | 0805P |  |  |  | Zener Diode
BAV99 | 2 | D4, D5 | SOT-23 |  |  | FN 162-1837 | Small Signal Diode, Dual Series
PMEG6010CEH | 3 | D9, D10, D11 | SOD87 |  |  | [NoValue], FN 151-0694 | DIODE, SCHOTTKY, 1A, 60V, SOD-123F
1374029 | 2 | J1UI, J3UI | 1373866 |  |  |  | SMD male connector, nominal current: 2.2 A, Test voltage: 840 VAC, number of positions: 20, pitch: 1.27 mm, color: black, contact surface: Gold, type of contact: Male connector, mounting: SMD soldering
1373866 | 1 | J2UI | YuanQi4mm |  |  |  | SMD male connector, nominal current: 2.2 A, Test voltage: 840 VAC, number of positions: 20, pitch: 1.27 mm, color: black, contact surface: Gold, type of contact: Male connector, mounting: SMD soldering
219320-0001 | 1 | J4 | usbc_24p |  |  |  | Universal Serial Bus (USB) Shielded I/O Receptacle, Type C, Vertical, Surface Mount, Height 8.8mm, 16 Circuits, Gold (Au) Flash Plating
USB_OUT | 1 | J5 | USB_OUT_A |  |  |  | USB Host Connector
PJS008-2003 | 1 | J6 | PJS008-2003-1 |  |  | PJS008-2003-1 | Memory Card Connectors MicroSD Card Conn Revrs Mnt Push-Push
LCD-20pin FPC | 1 | J7 | MOLX-52746-2071 | FPC Board Connector, 0.5 mm, 20 Contacts, Receptacle, Top contacts position! |  | FN 3215802 | LCD-20pin FPC, Top contacts position
FH19C-6S-05SH | 1 | J8 | MOLX-501461-0891 | FPC Board Connector, 0.5 mm, 8 Contacts, Receptacle,Top contact position |  | FN 2614916 | 8 pin FPC, Top contacts position
Mic | 1 | J10 | MX-387GL_new1 |  |  | FN 126-7376 | Jack Socket,Thru-Hole
Phones | 1 | J11 | KLBR4 |  |  | FN 121-7016 | Jack Socket 4 pin
Line Out | 1 | J13 | MX-387GL_new1 |  |  | FN 126-7376 | Jack Socket,Thru-Hole
Line In | 1 | J14 | MX-387GL_new1 |  |  | FN 126-7376 | Jack Socket,Thru-Hole
Paddles | 1 | J15 | MX-387GL_new1 | post assembly |  |  | Jack Socket,Thru-Hole
0 | 9 | M0, M1, M53, M55, M56, M57, M58, R3, R4 | 0805 |  |  | FN 933-3681, [NoValue] | Resistor
Speaker | 1 | P0 | MHDR1X2_m |  |  |  | Header, 2-Pin
IRLML6244TRPBF | 2 | Q1, Q1a | SOT-23 |  |  | FN 186-4517 | N-Channel MOSFET
1k | 9 | R1, R2, R7, R17, R18, R20, R21, R30, R30a | 0805 |  |  | FN 933-2421, FN 146-9899 | Resistor
4.7K | 11 | R1a, R1b, R21a, R21b, R43, R44, R47, R48, R49, R53, R54 | 0805 |  |  | FN 200-8383 | Resistor
47K | 6 | R7a, R24, R25, R26, R28, R29 | 0805 |  |  | FN 146-9929, FN 146-9857 | Resistor
100 | 9 | R7b, R7f, R7g, R31, R42, R50, R51, R52, R59 | 0805 |  |  | FN 933-2375, [NoValue], FN 157-6459 | Resistor
22K | 6 | R8, R8a, R11, R12, R13, R14 | 0805 |  |  | FN 188-7289 | Resistor
100k | 2 | R9, R10 | 0805 |  |  | FN 157-6459 | Resistor
2.2/1206 | 4 | R15, R16, R19a, R19b | 1206 |  |  | FN 207-8984 | Resistor
330 | 1 | R19 | 0805 |  |  | FN 146-9899 | Resistor
5.1k | 2 | R22, R23 | 0805 |  |  | FN 146-9857 | Resistor
2.2k | 2 | R23a, R45 | 0805 |  |  | FN 146-9857, FN 188-7289 | Resistor
10k | 4 | R27, R32, R33, R34 | 0805 |  |  | FN 146-9857 | Resistor
10 | 1 | R46 | 1206 | What is the biggest power rating to fit into 1206 ? |  | FN 207-3875 | Resistor
47uH | 4 | RFC1, RFC2, RFC3, RFC7 | 0805 |  |  | FN 166-9895, [NoParam] | Inductor
22uH | 2 | RFC5, RFC6 | 0805 | Don't we already have selection for 0.8.0(bigger than 0805) ?, [NoParam] |  |  | Power Inductor
Power | 1 | S1 | BUTTON_SMD2 |  |  |  | Push Button
DSP | 1 | S2 | BUTTON_SMD2 |  |  |  | Push Button
Mode | 1 | S3 | BUTTON_SMD2 |  |  |  | Push Button
Band- | 1 | S4 | BUTTON_SMD2 |  |  |  | Push Button
Band+ | 1 | S5 | BUTTON_SMD2 |  |  |  | Push Button
F1 | 1 | S6 | BUTTON_SMD2 |  |  |  | Push Button
F2 | 1 | S7 | BUTTON_SMD2 |  |  |  | Push Button
F3 | 1 | S8 | BUTTON_SMD2 |  |  |  | Push Button
F4 | 1 | S9 | BUTTON_SMD2 |  |  |  | Push Button
F5 | 1 | S10 | BUTTON_SMD2 |  |  |  | Push Button
CS4245 | 1 | U1 | QUAD48 |  |  |  | Audio CODEC
LM4853MM | 1 | U2 | SLAB-MSOP-10_N | 300mW 1ch Mono, 2ch Stereo Audio Amp |  |  | Mono 1.5 W / Stereo 300mW Power Amplifier
KCX_BT | 1 | U3 | KCX_BT |  |  |  | KCX_BT_EMITTER V 1.7
AP22811A | 2 | U3a, U4 | SOT25-5 |  |  | FN 274-8550 | High-side switch
STM32H747BIT6 | 1 | U5 | LQFP208-28x28x1.4 |  |  | FN 248-4976 | STM32H747BIT6 LQFP208
RT9293B | 1 | U7 | SOT25-6 | Originally from Thomas, if not Ali |  | Hotmcu.com | Charge Pump
IS42S32160F-6TL | 1 | U8 | MICT-TG-86_N |  |  |  | 128Mb PC133 SDR SDRAM, 4Mb x 32, 6ns, 3.3V, 0 to 70 degC, 86-Pin TSOP
Si5351A-A-GT | 1 | U11 | SLAB-MSOP-10_N | Farnell had it cheap (like 80 pence) |  |  | I2C-Programmable Any-Frequency CMOS Clock Generator + VCXO, 2.5 / 3.3 V, 0.008 to 160 MHz Output, -40 to 85 degC, 10-pin SOP
74AC74DR | 1 | U12 | SO-14 | Can use PO74G74A, but remove M52, install M53 |  | FN 985-3502 | Low Voltage Dual D-Type Positive Edge-Triggered Flip-Flop with 5V Tolerant Inputs
FOX924B-25.000 | 1 | U13 | 2SMX-3SMXB |  |  | FN 206-3959 | TCXO
ABS25-32.768KHZ-6-1-T | 1 | Y1 | DSO-N4 |  |  | FN 283-2029 | 32kHz Crystal

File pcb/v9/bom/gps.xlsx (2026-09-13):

Comment | Quantity | Designator | Footprint | Notes | Voltage | Order | Description
100nF | 1 | C34 | 0805 |  |  | FN 252-2090 | Capacitor
10uF | 1 | C35 | 1206_Elec_Cap |  | 25V |  | Electrolitic capacitor
GPS | 1 | P1 | HDR1X6 |  |  |  | Header, 6-Pin
100 | 3 | R34, R35, R36 | 0805 |  |  |  | Resistor
0 | 1 | R37 | 0805 |  |  |  | Resistor
TU10-F | 1 | U1 | TU10-F |  |  |  | GNSS Module

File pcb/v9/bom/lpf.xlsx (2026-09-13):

Comment | Quantity | Designator | Footprint | Notes | Voltage | Order | Description
100nF | 8 | C43, C44, C45, C46, C47, C132, C133, C136 | 0805 |  | [NoParam], 100V |  | Capacitor
47pF | 1 | C48 | 0805 | COG/NPO | 100V |  | Capacitor
18pF | 1 | C49 | 0805 | COG/NPO | 100V |  | Capacitor
100pF | 5 | C50, C52, C53, C54, C59 | 0805 | COG/NPO | 100V |  | Capacitor
10pF | 1 | C51 | 0805 | COG/NPO | 100V |  | Capacitor
2pF | 1 | C55 | 0805 | COG/NPO | 100V |  | Capacitor
180pF | 3 | C56, C60, C64 | 0805 | COG/NPO | 100V |  | Capacitor
390pF | 3 | C57, C58, C74 | 0805 | COG/NPO | 100V |  | Capacitor
270pF | 2 | C61, C65 | 0805 | COG/NPO | 100V |  | Capacitor
680pF | 2 | C62, C63 | 0805 | COG/NPO | 100V |  | Capacitor
470pF | 2 | C66, C70 | 0805 | COG/NPO | 100V |  | Capacitor
1.2nF | 2 | C67, C68 | 0805 | COG/NPO | 100V |  | Capacitor
220pF | 1 | C69 | 0805 | COG/NPO | 100V |  | Capacitor
820pF | 2 | C71, C75 | 0805 | COG/NPO | 100V |  | Capacitor
2.2nF | 2 | C72, C73 | 0805 | COG/NPO | 100V |  | Capacitor
PMEG6010CEH | 1 | D9 | SOD87 |  |  |  | DIODE, SCHOTTKY, 1A, 60V, SOD-123F
TX | 1 | J1 | ufl
1373826 | 2 | J9, J10 | 1373826 |  |  |  | SMD male connector, nominal current: 2.2 A, Test voltage: 840 VAC, number of positions: 6, pitch: 1.27 mm, color: black, contact surface: Gold, type of contact: Male connector, mounting: SMD soldering
G6KU-2FY 3DC | 4 | K1, K2, K3, K4 | Omron_2FY-Pro |  |  | FN 118-1070 | Single-winding Latching Relay
G6K-2FY 3DC | 1 | K5 | Omron_2FY | cheaper version from Ali |  |  | Single-winding Latching Relay
T37-2 | 15 | L13, L14, L15, L16, L17, L18, L19, L20, L21, L22, L23, L24, L25, L26, L27 | LPF_IND_V | post assembly |  |  | T37-2 handwound inductor
0 | 8 | M10, M11, M12, M13, M14, M15, M16, M17 | 0805 |  |  |  | Resistor
Header 2 | 1 | P5 | HDR1X2 |  |  |  | Header, 2-Pin
IRLML6244TRPBF | 1 | Q8 | SOT-23-Pro |  |  |  | N-Channel MOSFET
27 | 8 | R21, R22, R23, R24, R25, R26, R27, R28 | 1206 |  |  |  | Resistor
4.7k | 1 | R85 | 0805 |  |  |  | Resistor
SN74LS145D | 1 | U5 | SO-16 |  |  |  | BCD DECODER/DRIVER

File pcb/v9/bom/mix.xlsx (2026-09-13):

Description | Designator | Footprint | LibRef | Quantity
Capacitor | C0, C0a, C1, C2, C3, C4, C5, C6, C19, C20, C21, C22, C23, C24, C25, C26, C27, C28, C30a, C31, C32, C33, C34, C35, C40, C41, C43, C62, C63, C65, C66, C68, C69, C70, C71, C73, C80, C82, C84, C85 | 0805 | CAP | 40
Capacitor | C7, C15 | 0805 | CAP | 2
Capacitor | C8, C16 | 0805 | CAP | 2
Capacitor | C9, C12, C17 | 0805 | CAP | 3
Capacitor | C10, C13, C18 | 0805 | CAP | 3
Capacitor | C11 | 0805 | CAP | 1
Capacitor | C14 | 0805 | CAP | 1
Electrolitic capacitor | C30, C42, C54, C55, C56, C57, C67, C72 | 1206_Elec_Cap | CAP-POL | 8
Capacitor | C36, C37, C58, C59, C60, C61 | CAP_B | CAP | 6
Capacitor | C38, C39 | 0805 | CAP | 2
Capacitor | C50, C51, C52, C53, C81, C83 | 0805 | CAP | 6
0603 X5R 1礔 | C64 | 0805 | CAP SMD 0603 X5R 1礔 25V 10% | 1
 | J1 | ufl | UFL | 1
 | J2 | ufl | UFL | 1
SMD male connector, nominal current: 2.2 A, Test voltage: 840 VAC, number of positions: 20, pitch: 1.27 mm, color: black, contact surface: Gold, type of contact: Male connector, mounting: SMD soldering | J2MIX | YuanQi4mm | YQ_20p | 1
INDUCTOR SMD | L1, L6, L9 | 0805 | BPF_IND | 3
INDUCTOR SMD | L2, L7, L10 | 0805 | BPF_IND | 3
INDUCTOR SMD | L3, L11 | 0805 | BPF_IND | 2
INDUCTOR SMD | L4, L12 | 0805 | BPF_IND | 2
INDUCTOR SMD | L5 | 0805 | BPF_IND | 1
INDUCTOR SMD | L8 | 0805 | BPF_IND | 1
Resistor | M1, M2, M3, M4, M5, M6, M7, M8, M10, M11, M20, M21 | 0805 | RES | 12
TRANSISTOR, RF, NPN, 12V, 0.035MA,SOT-23 | Q1 | SOT-23 | BFR93A | 1
Resistor | R1, R2, R11, R12 | 0805 | RES | 4
Resistor | R3, R4, R5, R6, R7, R8, R9, R10, R21 | 0805 | RES | 9
Resistor | R20, R25, R26, R27, R28, R30, R31, R33, R34, R60, R61, R62 | 0805 | RES | 12
Resistor | R22 | 0805 | RES | 1
Resistor | R23, R24 | 0805 | RES | 2
Resistor | R29, R32, R56, R57 | 0805 | RES | 4
Resistor | R35, R36 | 0805 | RES | 2
Resistor | R40, R41, R42, R43, R44, R45, R46, R47, R63, R64, R65, R66, R67, R68, R69 | 0805 | RES | 15
Resistor | R48, R49, R50, R51, R52, R53 | 0805 | RES | 6
Resistor | R58 | 1206 | RES | 1
INDUCTOR, SIGNAL LINE, 4.7UH, 1005 | RFC1, RFC2, RFC3, RFC4 | 0805 | TDK-NLV25T | 4
Wideband RF Transformer 1:4 | T1, T2 | SOP5_NEW1 | CX2074NL | 2
Quad 2-input NOR gate | U0 | SO-14 | 74HCT02 | 1
Dual 4:1 Demux/Analog Switch | U1, U2 | SO-16 | SN74CBT3253C | 2
Dual 4:1 Demux/Analog Switch | U3, U6 | SO-16-Pro | SN74CBT3253C | 2
High Speed, Single Supply OpAmp | U4 | SO-8 | OPA2350UA | 1
Low Power, Rail-To-Rail OpAmp | U5 | SO-14-Pro | TLV2464CD | 1
High-side switch | U7 | SOT25-5 | AP22811 | 1
MMIC AMPLIFIER | U8 | SOT89L_new | HMS482ST89E | 1
4Ghz Attenuator | U9 | QFN20_4X4 | PE4312 | 1

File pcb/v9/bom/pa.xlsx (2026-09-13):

Comment | Quantity | Designator | Footprint | Notes | Voltage | Order | Description
100nF | 4 | C97, C98, C105, C106 | 0805 |  | 100V |  | Capacitor
10nF | 2 | C99, C100 | 0805 |  | 100V |  | Capacitor
560pF | 2 | C101, C103 | 0805 |  | 100V |  | Capacitor
330pF | 1 | C102 | 0805 |  | 100V |  | Capacitor
10uF | 1 | C104 | 1206_Elec_Cap |  | 25V |  | Electrolitic capacitor
22uF | 1 | C107 | 1206_Elec_Cap |  | 25V |  | Electrolitic capacitor
Header 8H | 1 | P99 | HDR1X8Hpa |  |  |  | Header, 8-Pin, Right Angle
Header 2 | 1 | P100 | HDR1X2 |  |  |  | Header, 2-Pin
RD16HHF1 | 2 | Q4, Q5 | TO-220RF_v9 |  |  | EB 121171160336 | Silicon RF Power MOS FET
220 | 2 | R50, R51 | 0805 |  |  |  | Resistor
750 | 2 | R52, R53 | 0805 |  |  |  | Resistor
10 | 1 | R54 | 0805 |  |  |  | Resistor
BN43-2402 2T choke | 1 | RFC5 | F_Bead | post assembly |  |  | BN43-2402 1t choke
1:3 BN-43-3312 | 1 | T3 | PA_OUT_TRM | post assembly |  |  | 1:3 BN-43-3312 transformer

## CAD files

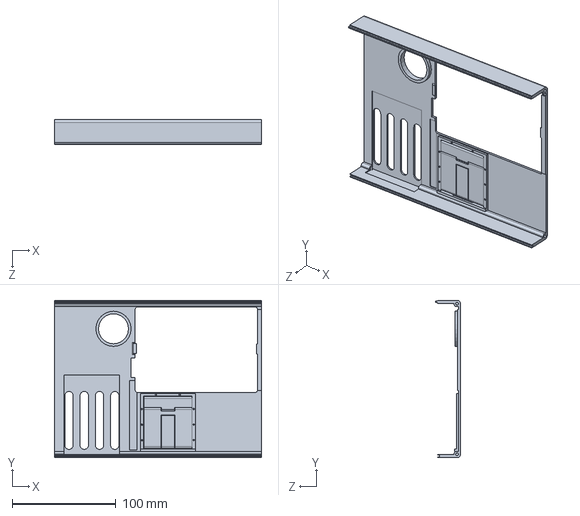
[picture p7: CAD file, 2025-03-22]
mechanical/back/back.SLDPRT
200.0 x 152.0 x 24.0 mm

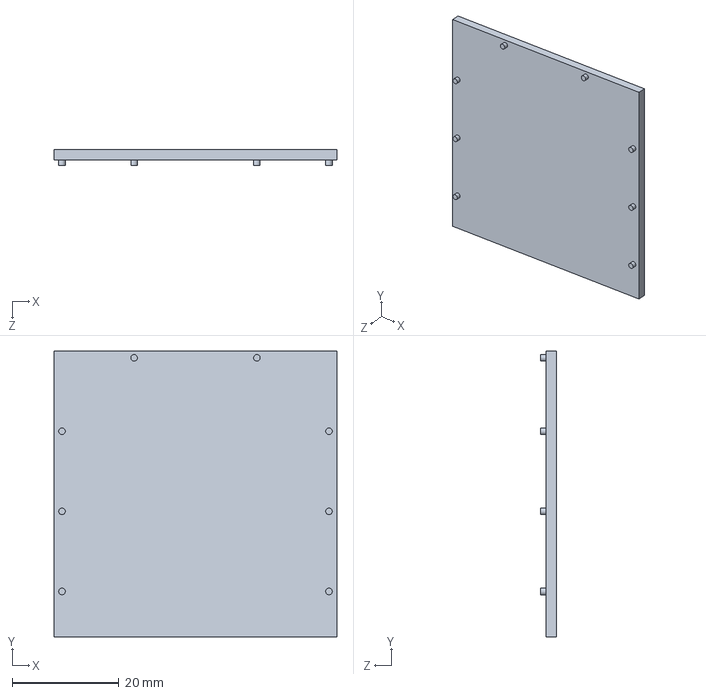
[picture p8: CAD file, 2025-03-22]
mechanical/back/closer/closer.SLDPRT
53.0 x 53.5 x 3.00 mm

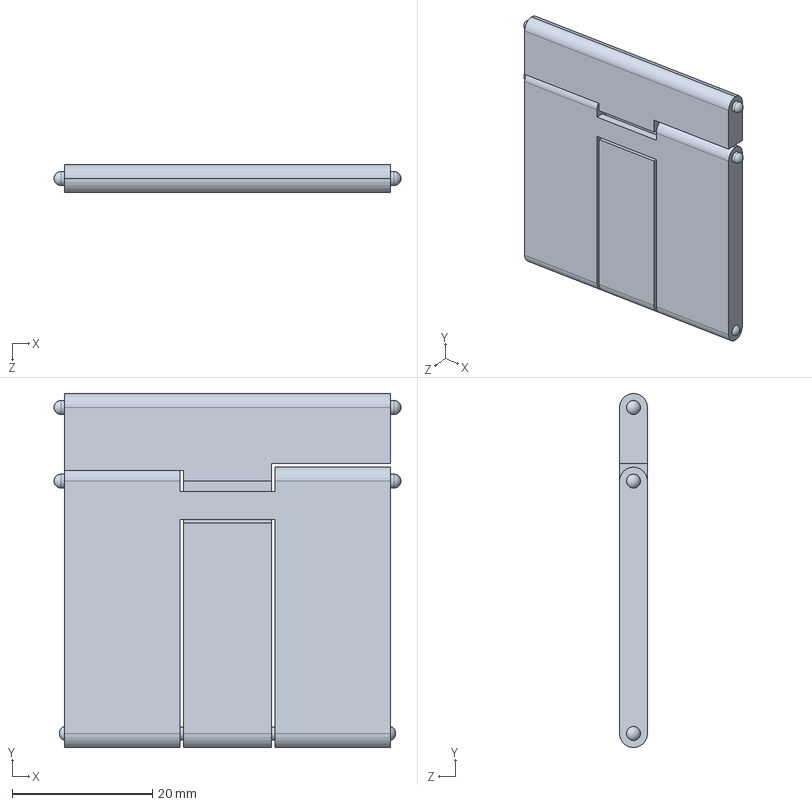
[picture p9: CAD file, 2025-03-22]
mechanical/back/stand/stand.SLDPRT
49.5 x 50.5 x 4.00 mm

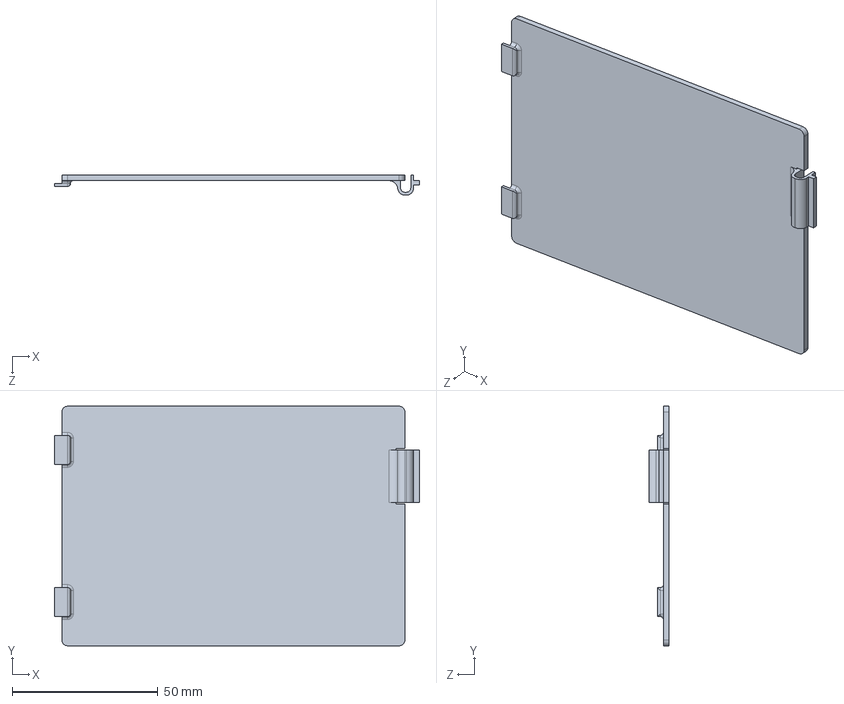
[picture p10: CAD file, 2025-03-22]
mechanical/batt_lid/lid.SLDPRT
125.2 x 82.2 x 7.00 mm

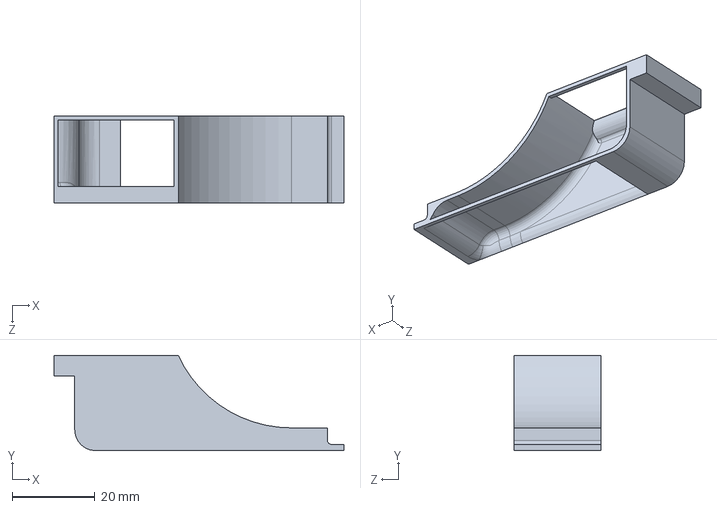
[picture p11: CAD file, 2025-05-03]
mechanical/fan_duct/duct.SLDPRT
70.0 x 23.0 x 21.0 mm

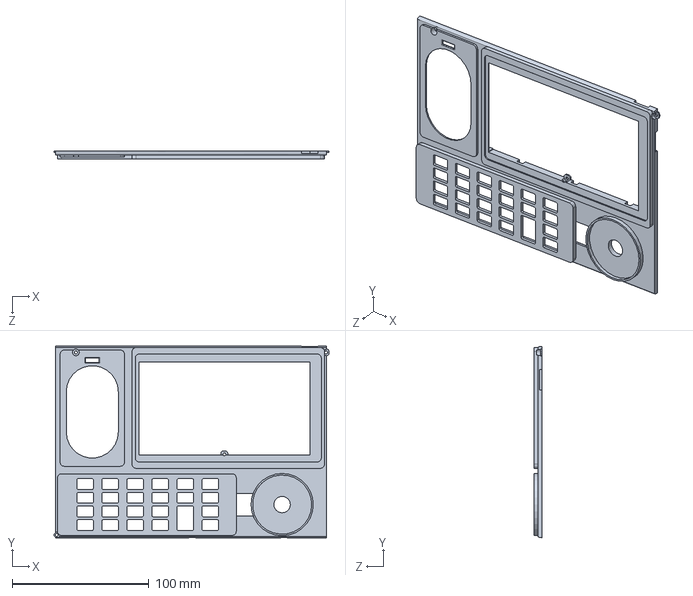
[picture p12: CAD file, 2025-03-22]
mechanical/front/front_panel_0.8.SLDPRT
201.0 x 140.0 x 6.00 mm

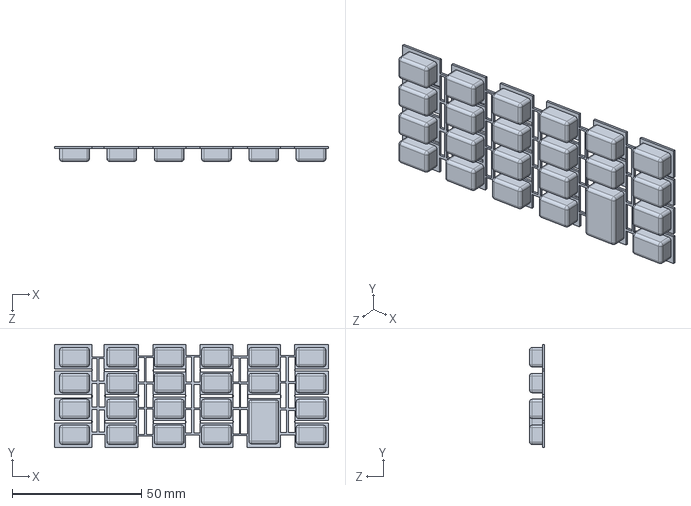
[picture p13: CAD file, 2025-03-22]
mechanical/keypad/keypad_label.SLDPRT
106.0 x 40.0 x 5.75 mm

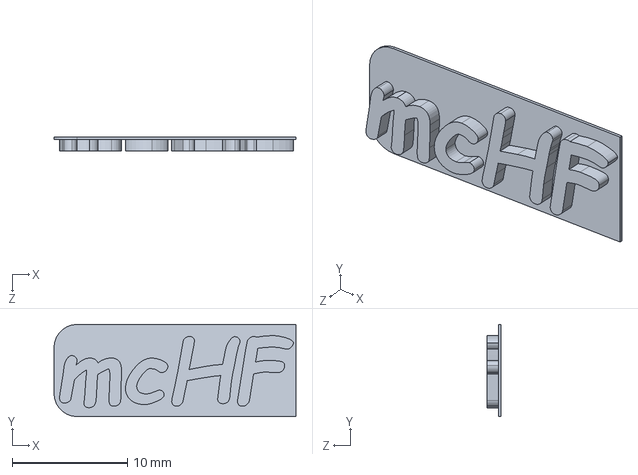
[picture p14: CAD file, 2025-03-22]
mechanical/logo/logo.SLDPRT
21.0 x 8.00 x 1.20 mm

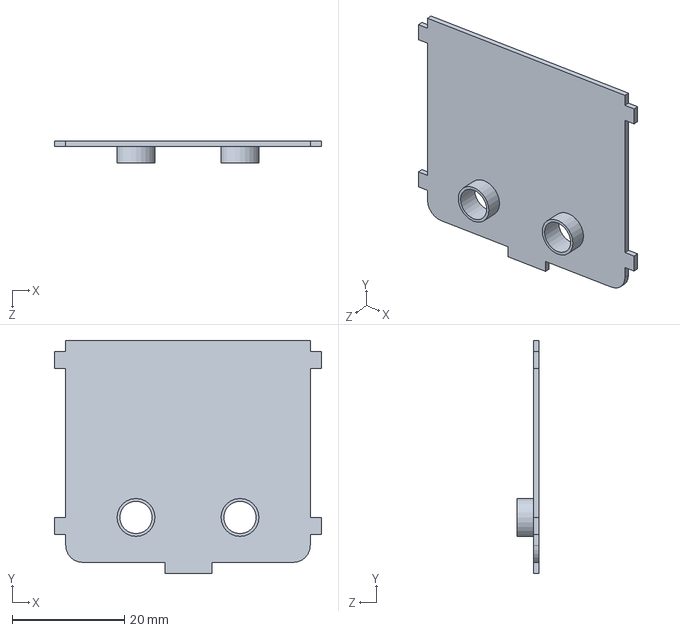
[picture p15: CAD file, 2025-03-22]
mechanical/paddles/cap/cap.SLDPRT
47.5 x 41.5 x 4.00 mm

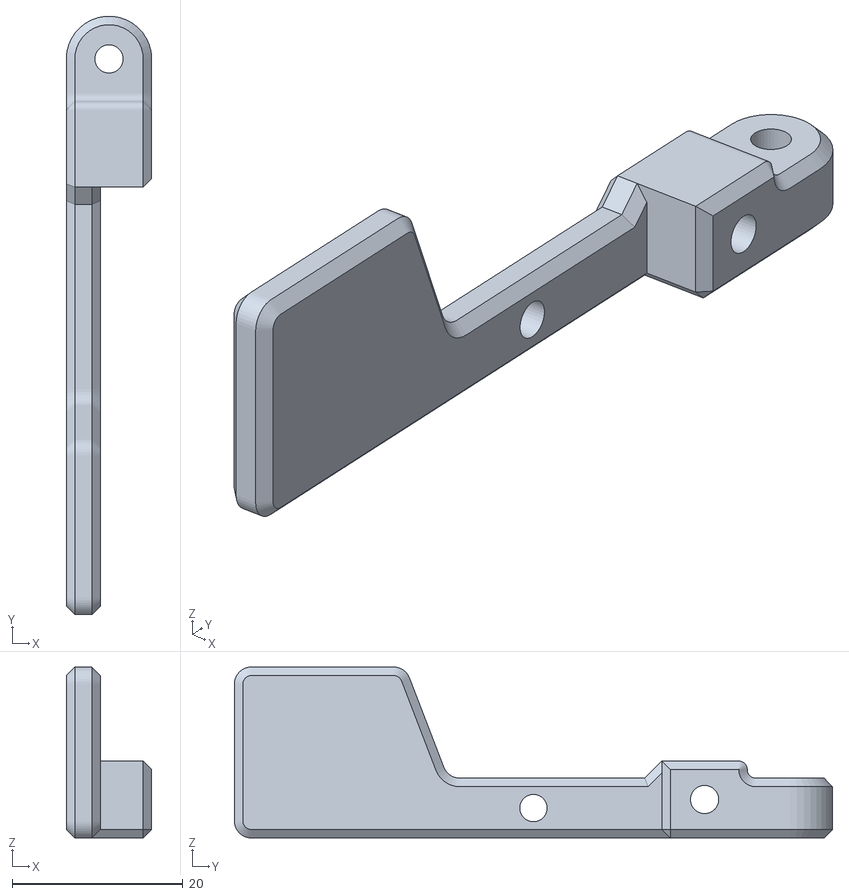
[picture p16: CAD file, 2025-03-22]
mechanical/paddles/right-lever_nospacer.stl
10.0 x 70.0 x 20.0

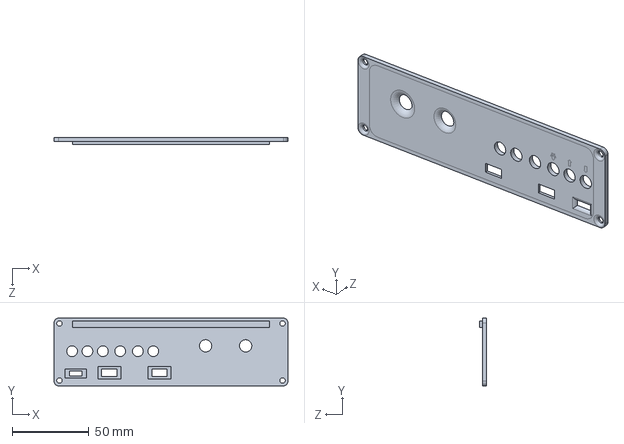
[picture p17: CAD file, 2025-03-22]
mechanical/panels/side_left.SLDPRT
152.0 x 44.0 x 4.50 mm

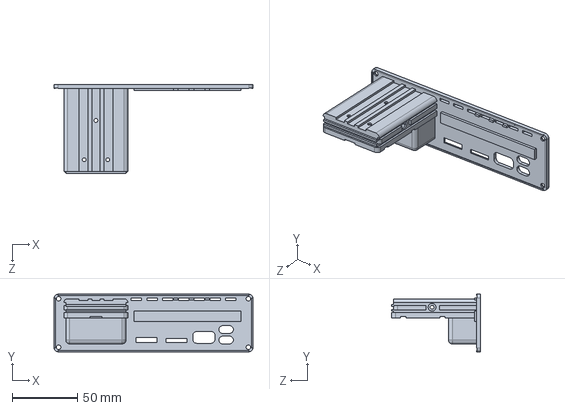
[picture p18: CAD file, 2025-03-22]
mechanical/panels/side_right.SLDPRT
152.0 x 44.0 x 68.0 mm

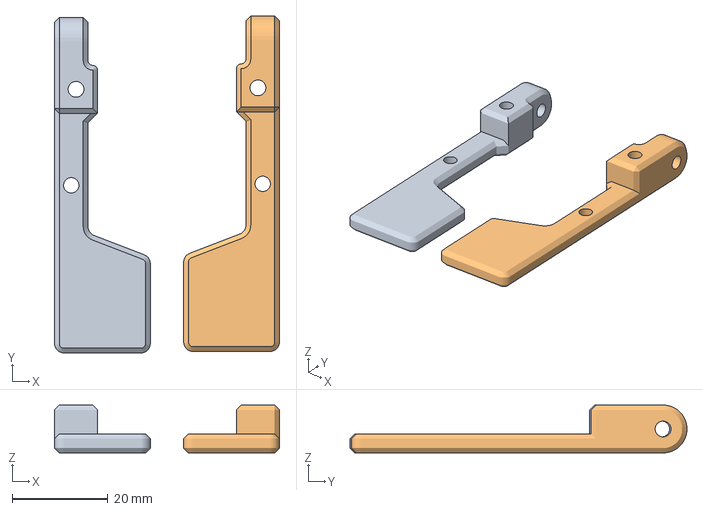
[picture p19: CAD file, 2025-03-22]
mechanical/paddles/both_paddles.3mf
46.9 x 70.3 x 10.0 mm
left-lever_nospacer.stl
right-lever_nospacer.stl

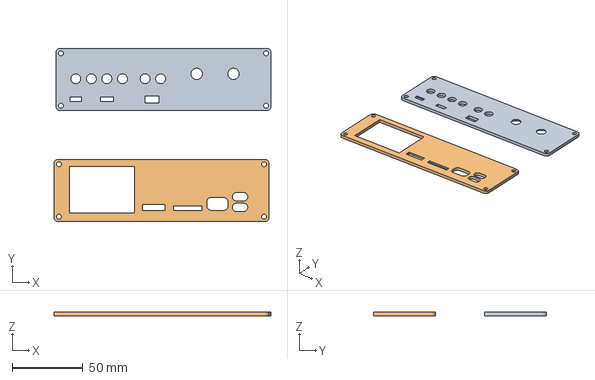
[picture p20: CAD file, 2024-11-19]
mechanical/panels/both.3mf
153.4 x 122.4 x 2.50 mm
side_left.STL
side_right.STL

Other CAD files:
mechanical/paddles/left-lever_nospacer.stl
mechanical/back/back.3mf
mechanical/back/back.STL
mechanical/back/closer/closer.3mf
mechanical/back/closer/closer.STL
mechanical/back/stand/stand.3mf
mechanical/back/stand/stand.STL
mechanical/batt_lid/lid.3mf
mechanical/batt_lid/lid.STL
mechanical/fan_duct/duct.3mf
mechanical/fan_duct/duct.STL
mechanical/front/front_panel_0.8.3mf
mechanical/front/front_panel_0.8.STL
mechanical/keypad/keypad_label.3mf
mechanical/keypad/keypad_label.STL
mechanical/paddles/cap/cap.3mf
mechanical/paddles/cap/cap.STL
mechanical/panels/side_left.3mf
mechanical/panels/side_left.STL
mechanical/panels/side_right.3mf
mechanical/panels/side_right.STL

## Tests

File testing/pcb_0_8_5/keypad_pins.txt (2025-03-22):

X1 - pd3
X2 - pd7
X3 - pg12, M28
X4 - pg13, M29
X5 - pb5
X6 - pi8

Y1 - pd6, M12
Y2 - pg9, M33
Y3 - pg14
Y4 - pi11
-------------------------
swap M12/M29 (Y1 and X4)
swap M33/M28 (Y2 and X3)
so can dedicate EXTI15_10_IRQHandler for
the keyboard driver

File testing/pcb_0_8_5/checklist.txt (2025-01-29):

Electrical and firmware:

 - RF 5V, ok
 - RF 8V, ok
 - RF 21V, ok
 - RF all 21, 8 and 5V rails ok
 - RF USB PD, ok
 
 - UI 3V, ok
 - UI power on from dial, ok
 - UI power hold via programmer, ok
 - UI programming interface, ok
 - UI bootloader GPIO changes, ok
 - UI radio firmware GPIO changes, ok
 - UI dsp firmware GPIO changes, ok
 - UI SD Card interface, ok
 - UI TCXO, not tested
 - UI 5V, not tested
 - UI VREF chip, not tested
 - UI touch interface, FAILED

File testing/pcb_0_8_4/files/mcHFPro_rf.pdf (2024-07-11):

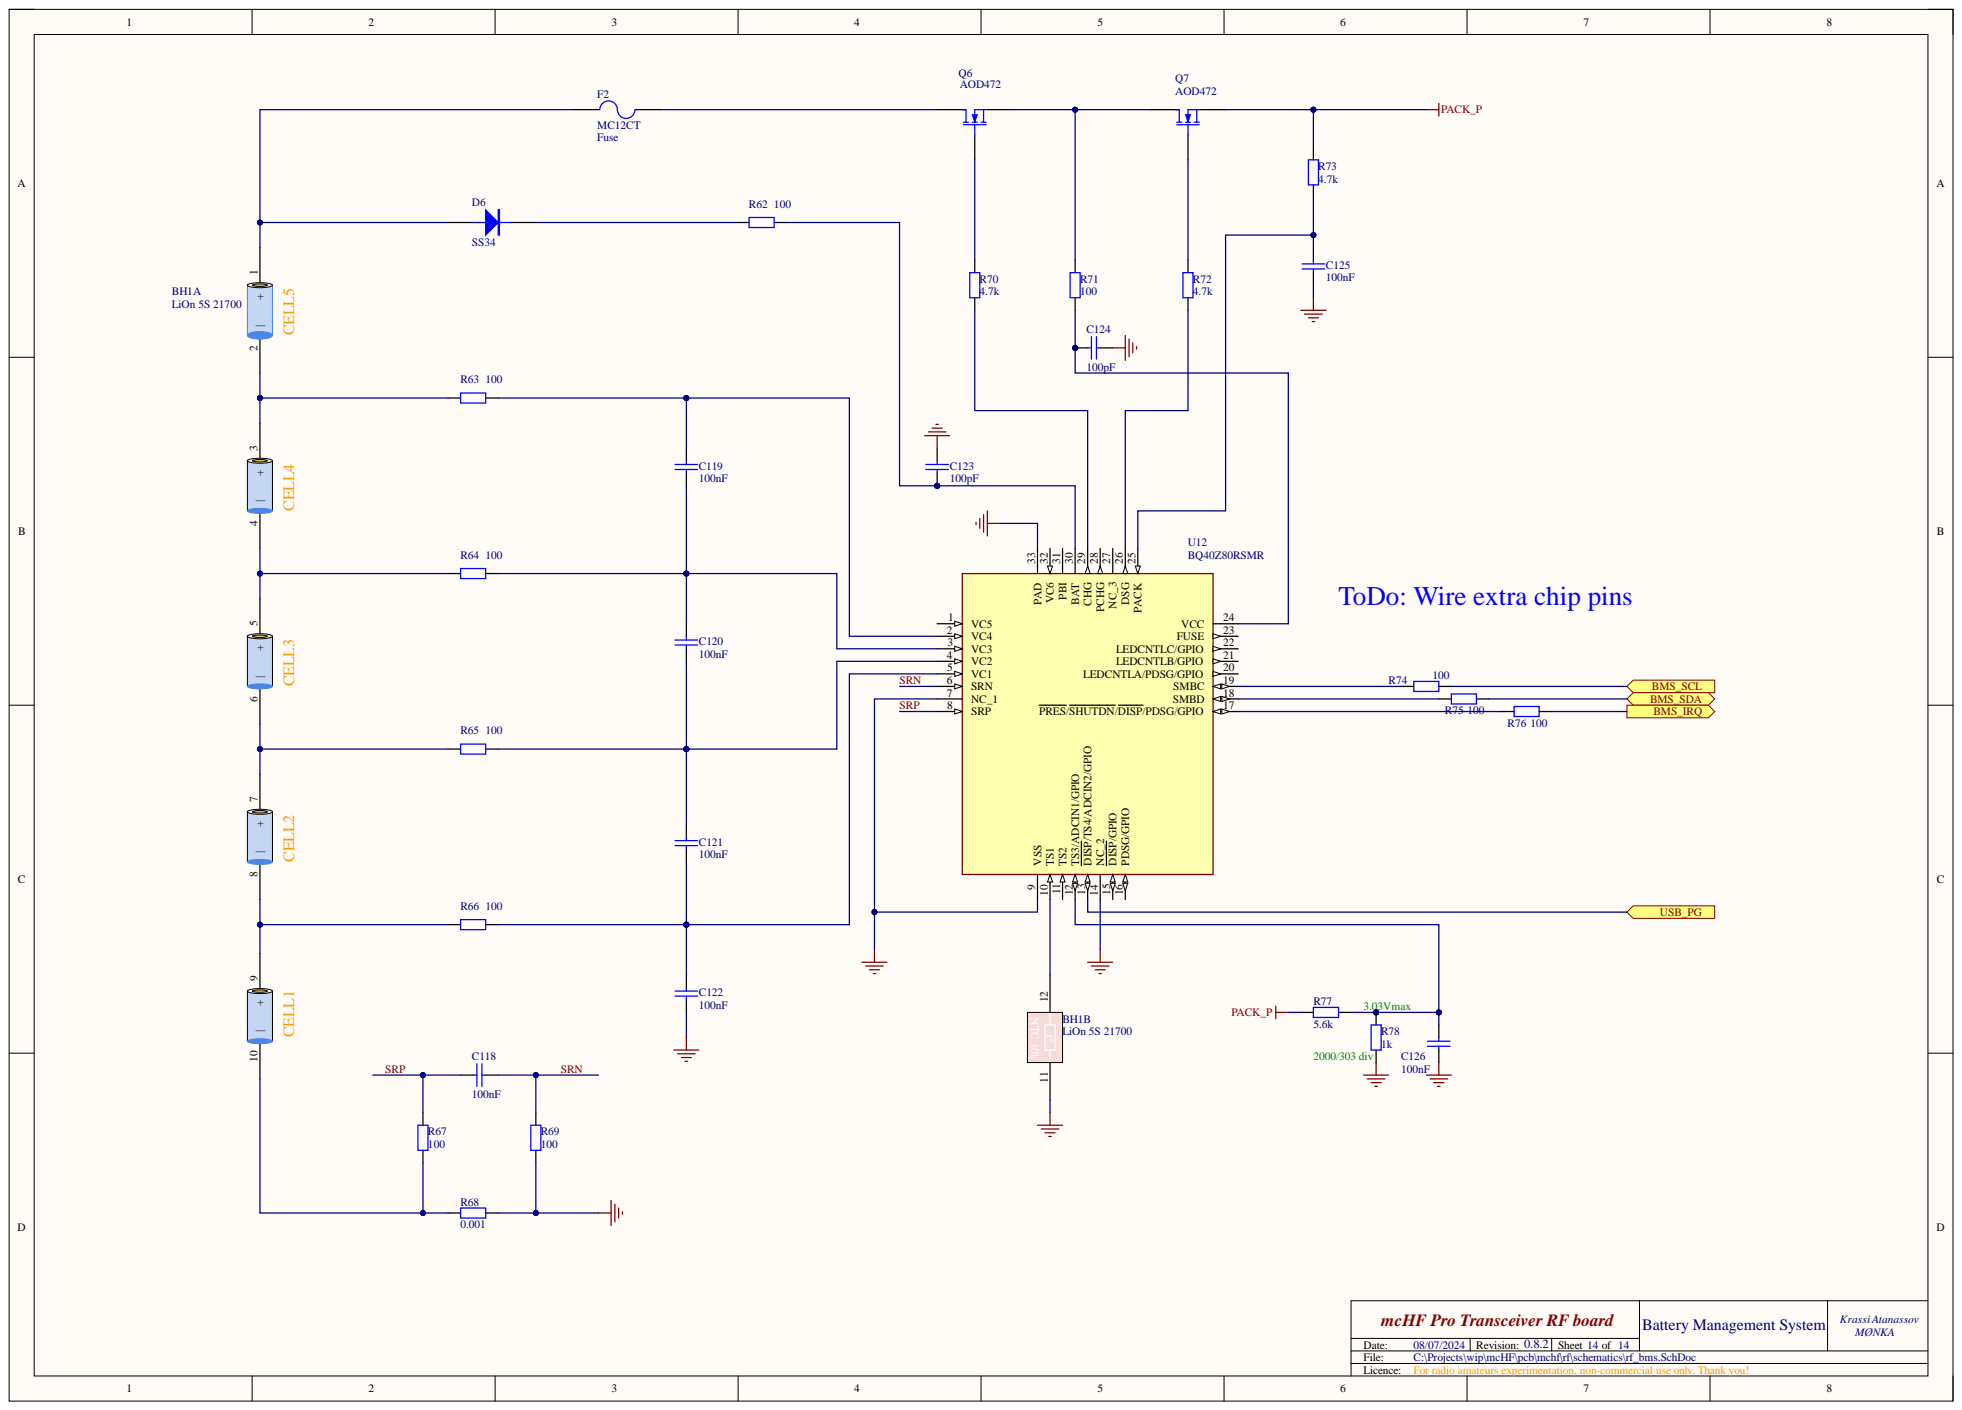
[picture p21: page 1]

Wire extra chip pins

HF\pcb\mchf\rf\s
xperimentation, non-c

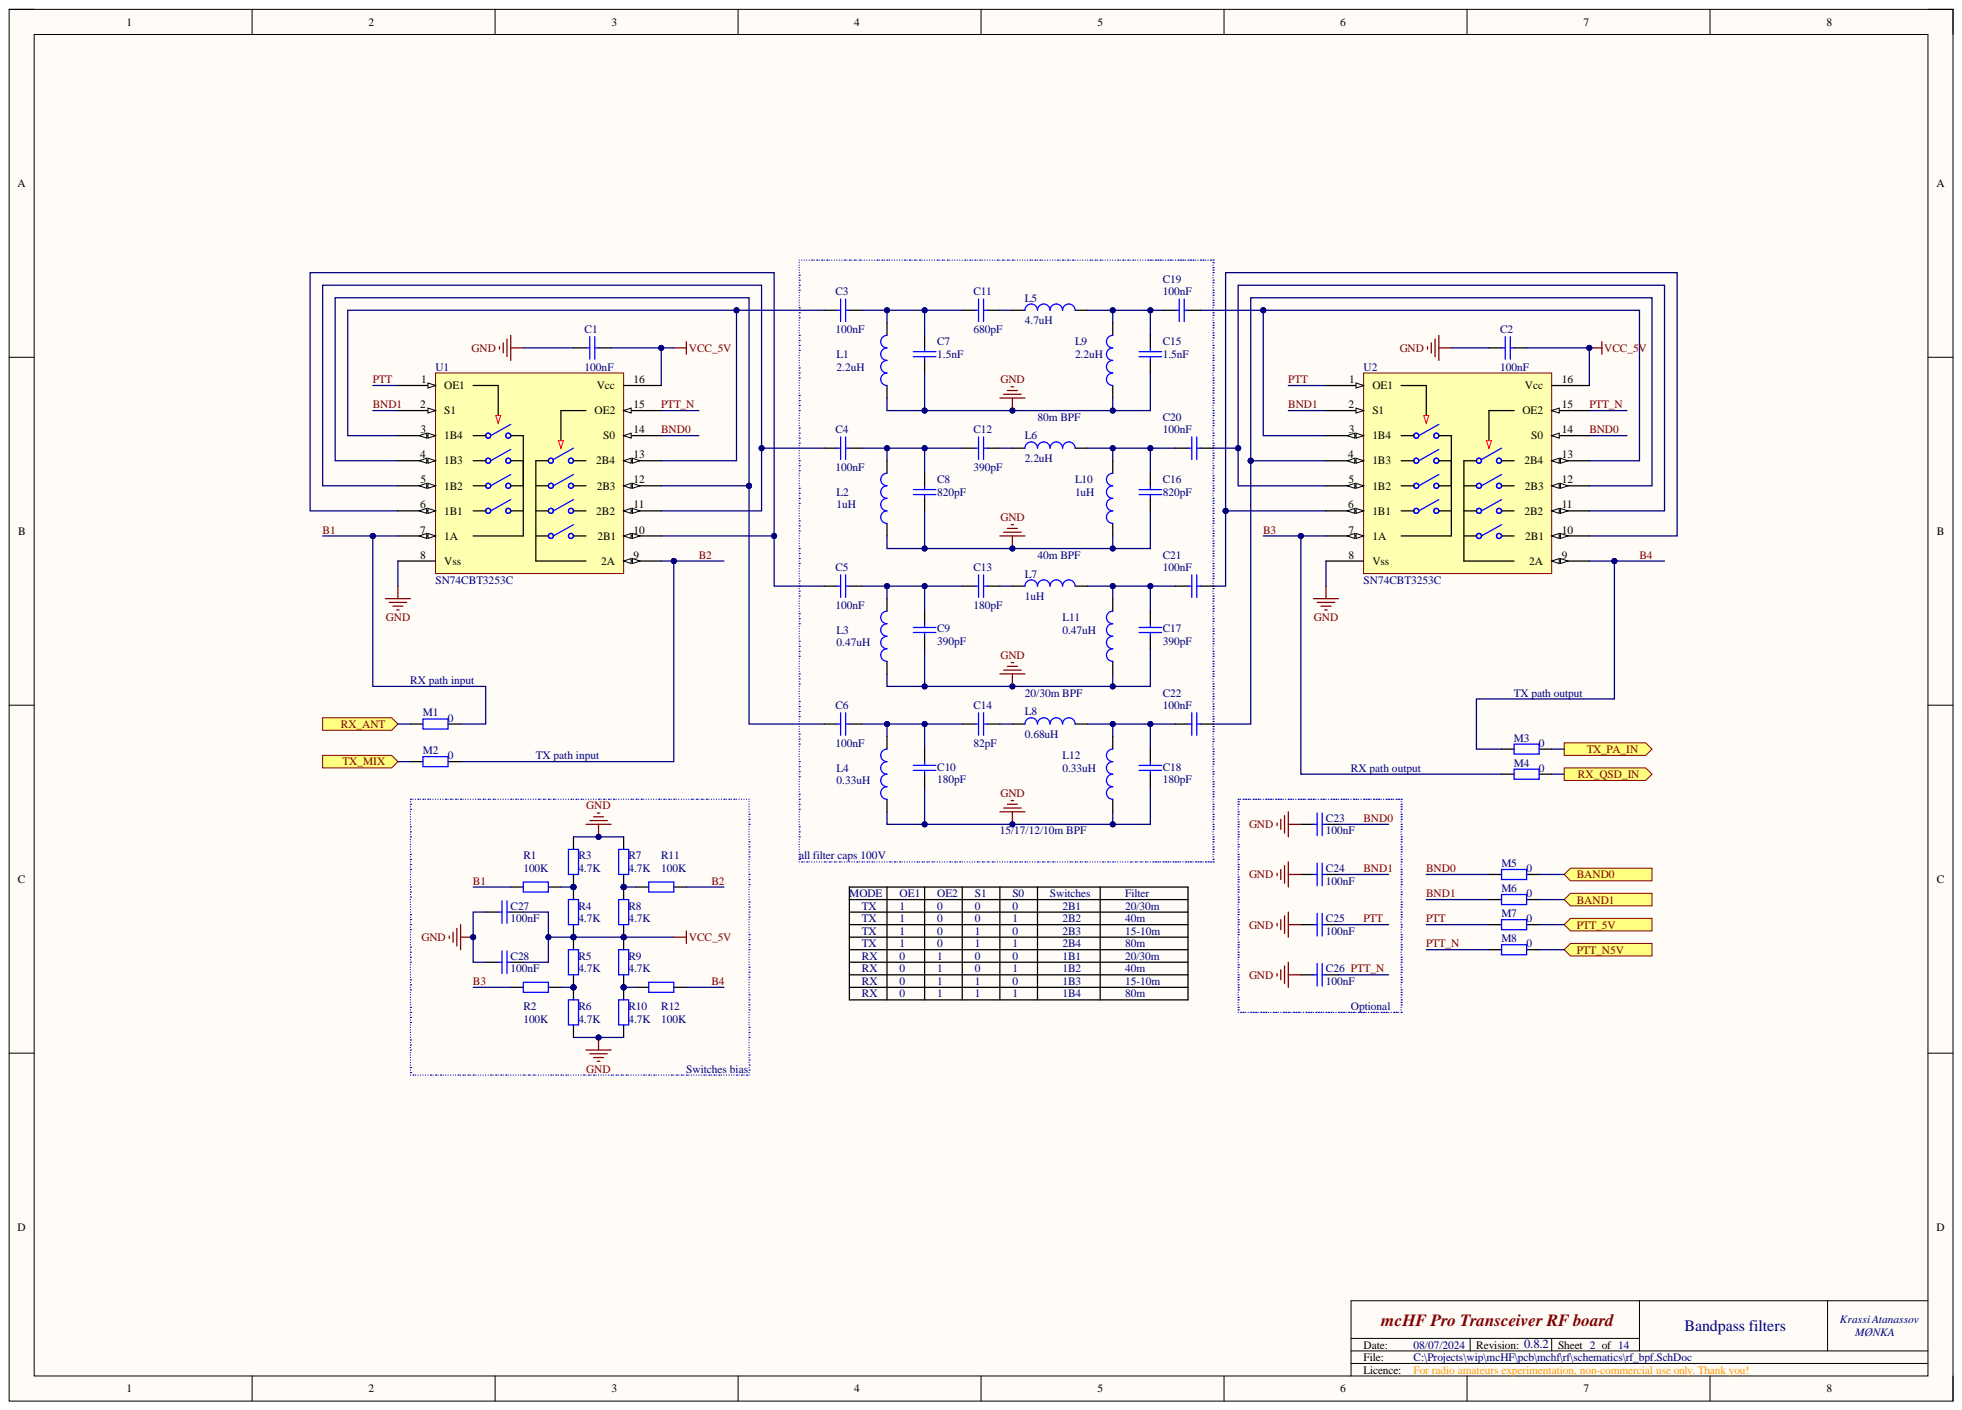
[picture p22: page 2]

MOD E | OE 1 | OE 2 | | | Switche s | Filte r

0 | 1 | 1 | 2B 4 | 80m
1 | | | 1B 1 | 20/30 m

R X | | | 0011 | 0101 | 1B 2 | 40m
R X | | 111 | | | 1B 3 | 15-10m

HF\pcb\mchf\rf\s
xperimentation, non-c

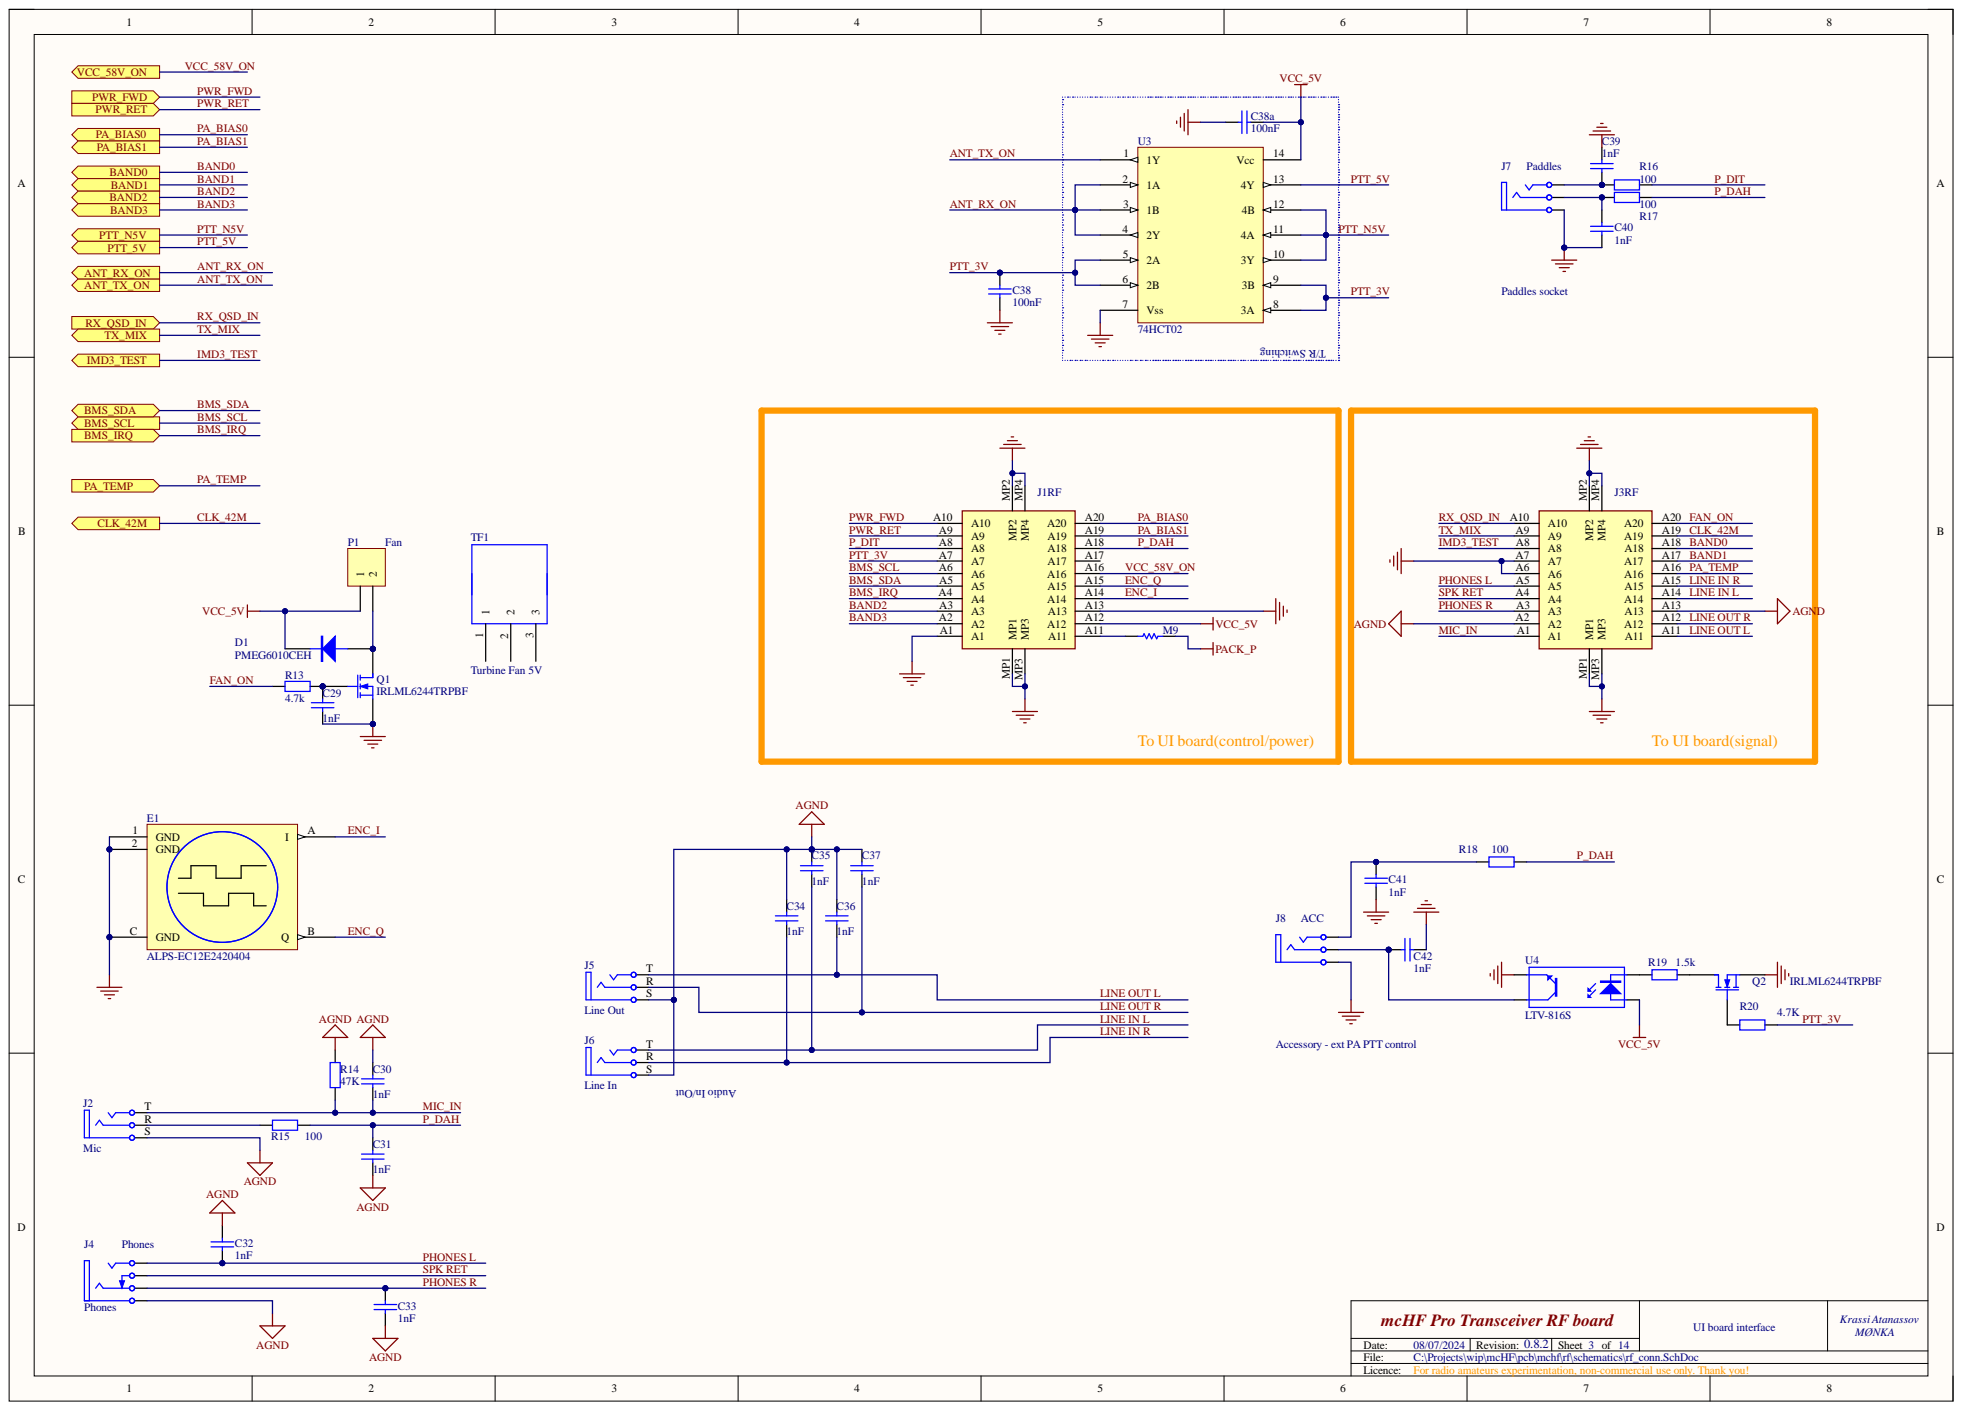
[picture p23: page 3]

LINE OUT L LINE OUT R

To UI board(control/power)

To UI board(si

LINE IN L
LINE IN R

HF\pcb\mchf\rf\s
xperimentation, non-c

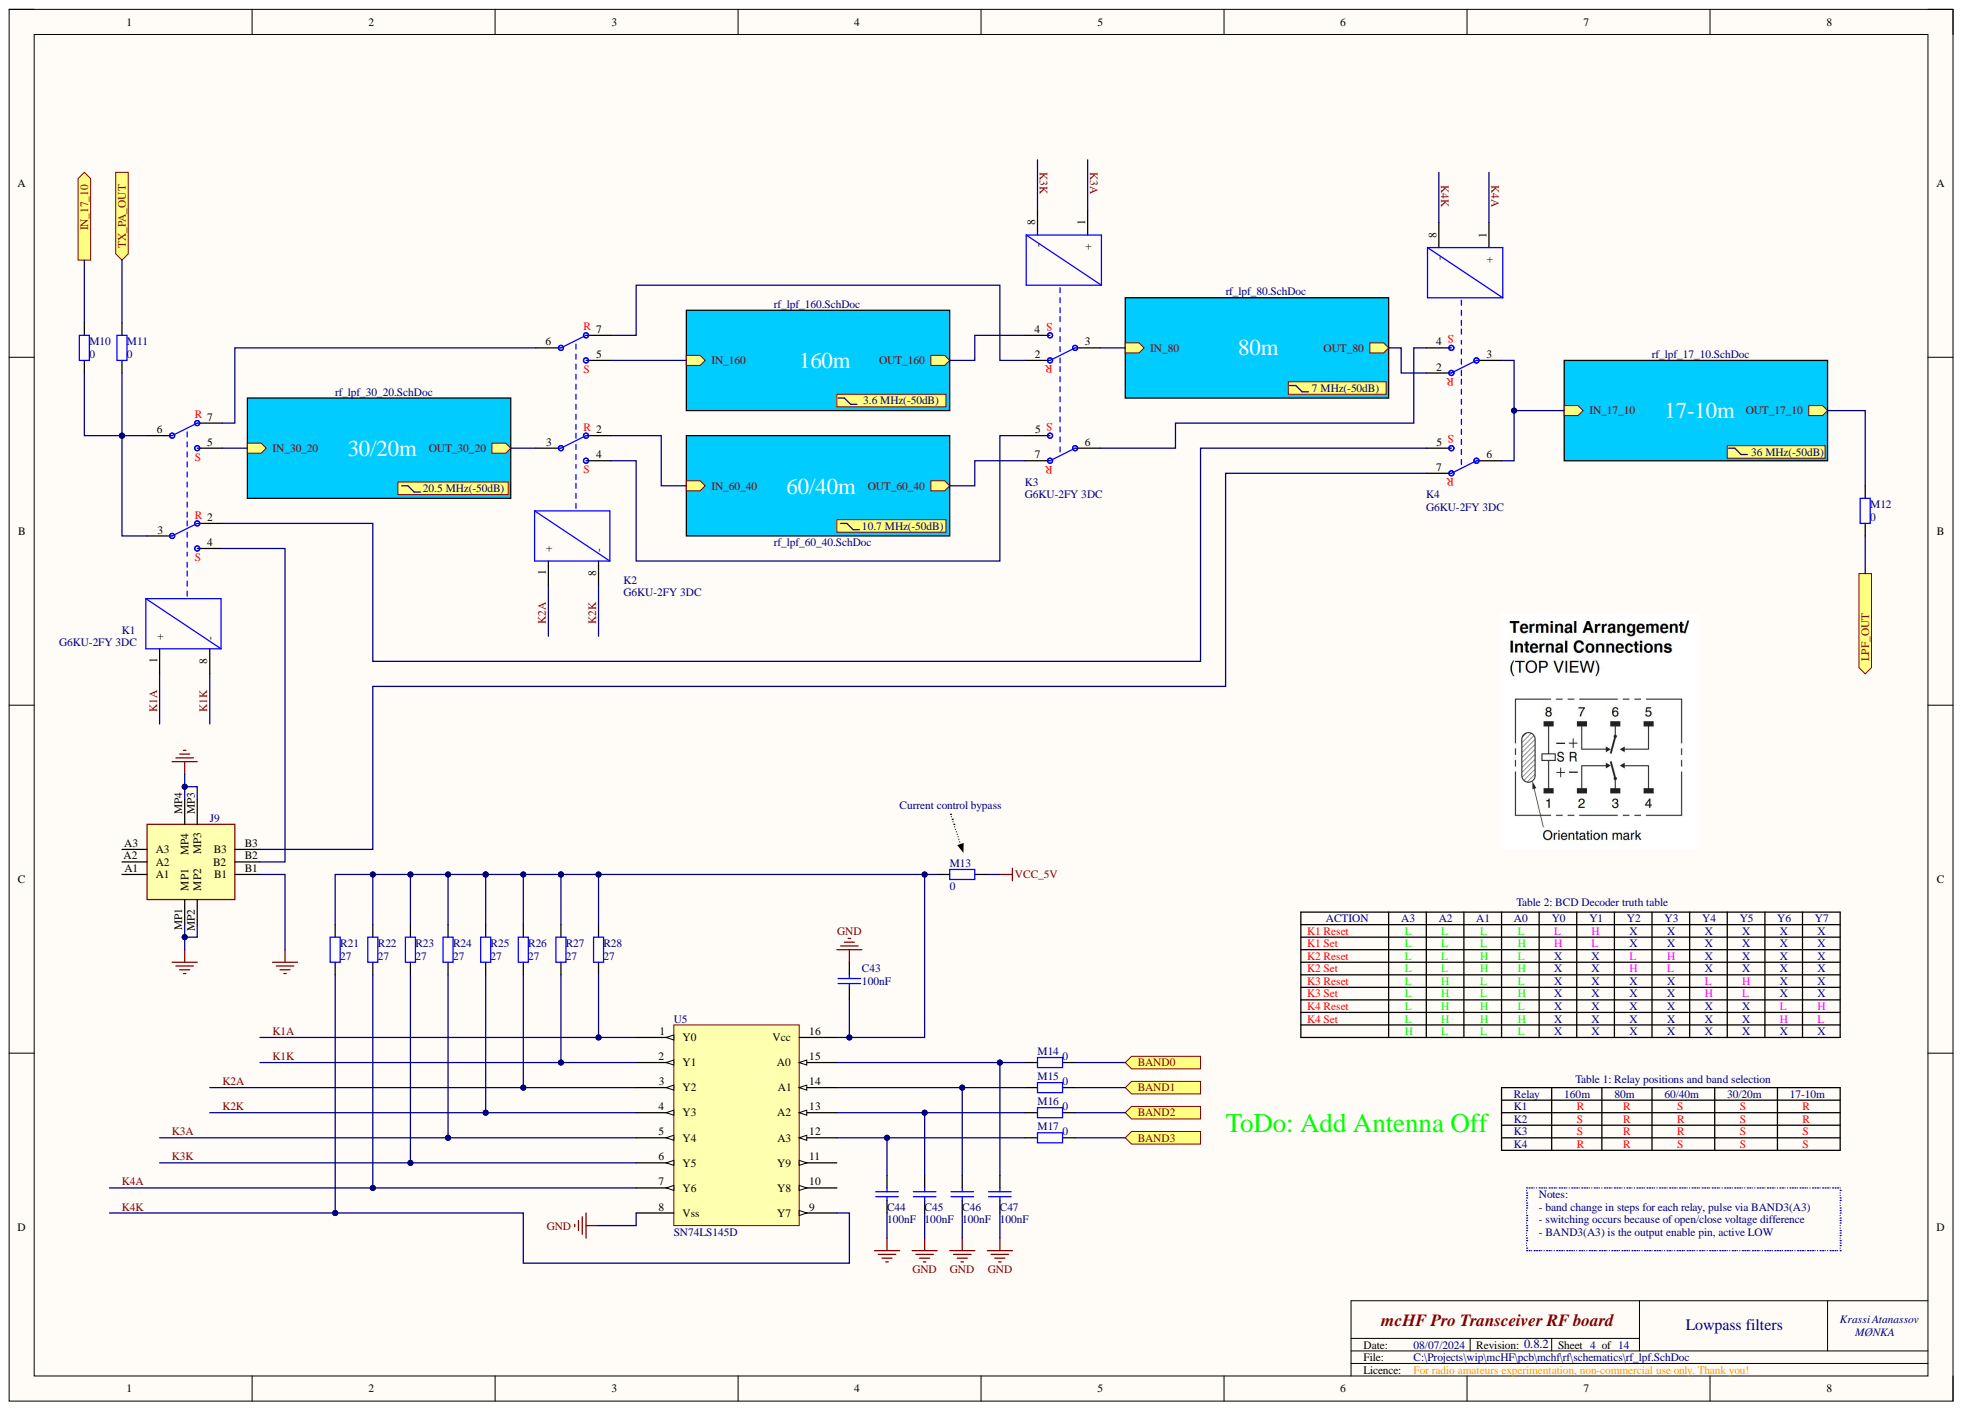
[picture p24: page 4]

Table 2: BCD Decoder truth table

ACTION | A3 | A2 | A1 | A0 | Y0 | Y1 | Y2 | Y3 | Y4 | Y5 | Y6 | Y7
K1 Reset | L | L | L | L | L | H | X | X | X | X | X | X
K1 Set | L | L | L | H | H | L | X | X | X | X | X | X
K2 Reset | L | L | H | L | X | X | L | H | X | X | X | X
K2 Set | L | L | H | H | X | X | H | L | X | X | X | X
K3 Reset | L | H | L | L | X | X | X | X | L | H | X | X
K3 Set | L | H | L | H | X | X | X | X | H | L | X | X
K4 Reset | L | H | H | L | X | X | X | X | X | X | L | H
K4 Set | L | H | H | H | X | X | X | X | X | X | H | L

GND

Table 1: Relay positions and band selection

ToDo: Add Antenna Off

Notes:
- band change in steps for each relay, pulse via BAND3(A3)
- switching occurs because of open/close voltage difference
- BAND3(A3) is the output enable pin, active LOW

mcHF Pro Transceiver RF board

Date:
File:
Licence: For radio amateurs experimentation, non-commercial use only. Thank you!

C:\Projects\wip\mcHF\pcb\mchf\rf\schematics\rf_lpf.SchDoc

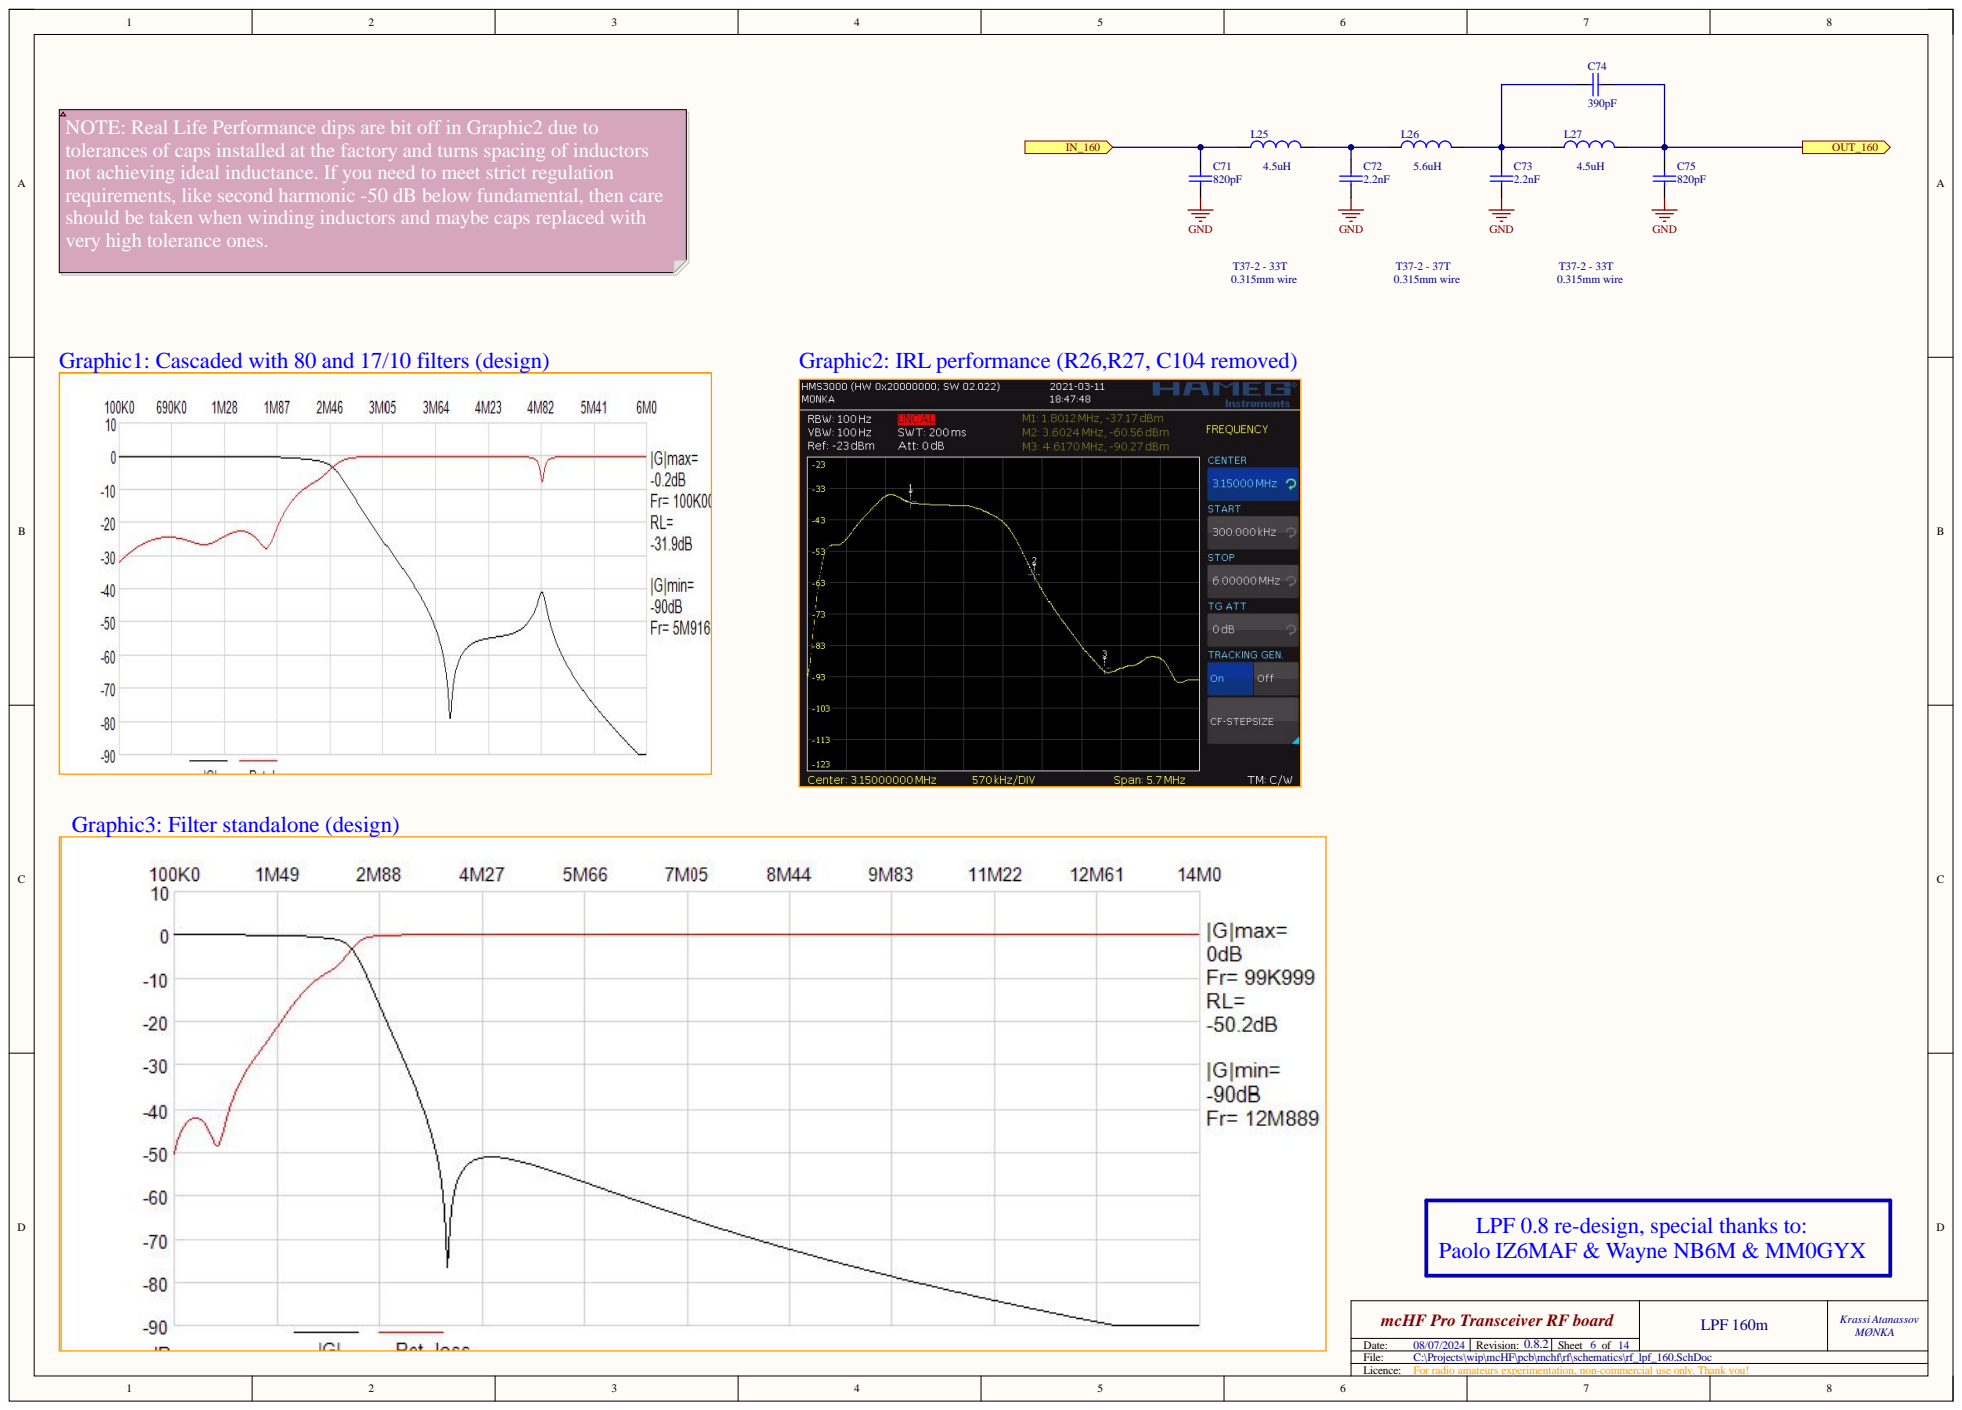
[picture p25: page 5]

NOTE: Real Life Performance dips are bit off in Graphic2 due to
tolerances of caps installed at the factory and turns spacing of inductors
not achieving ideal inductance. If you need to meet strict regulation
requirements, like second harmonic -50 dB below fundamental, then care
should be taken when winding inductors and maybe caps replaced with
very high tolerance ones.

Graphic1: Cascaded with 80 and 17/10 filters (design)

LPF 0.8 re-design, special thanks to:
Paolo IZ6MAF & Wayne NB6M & MM0GYX

C:\Projects\wip\mcHF\pcb\mchf\rf\schematics\rf_lpf_160.SchDoc

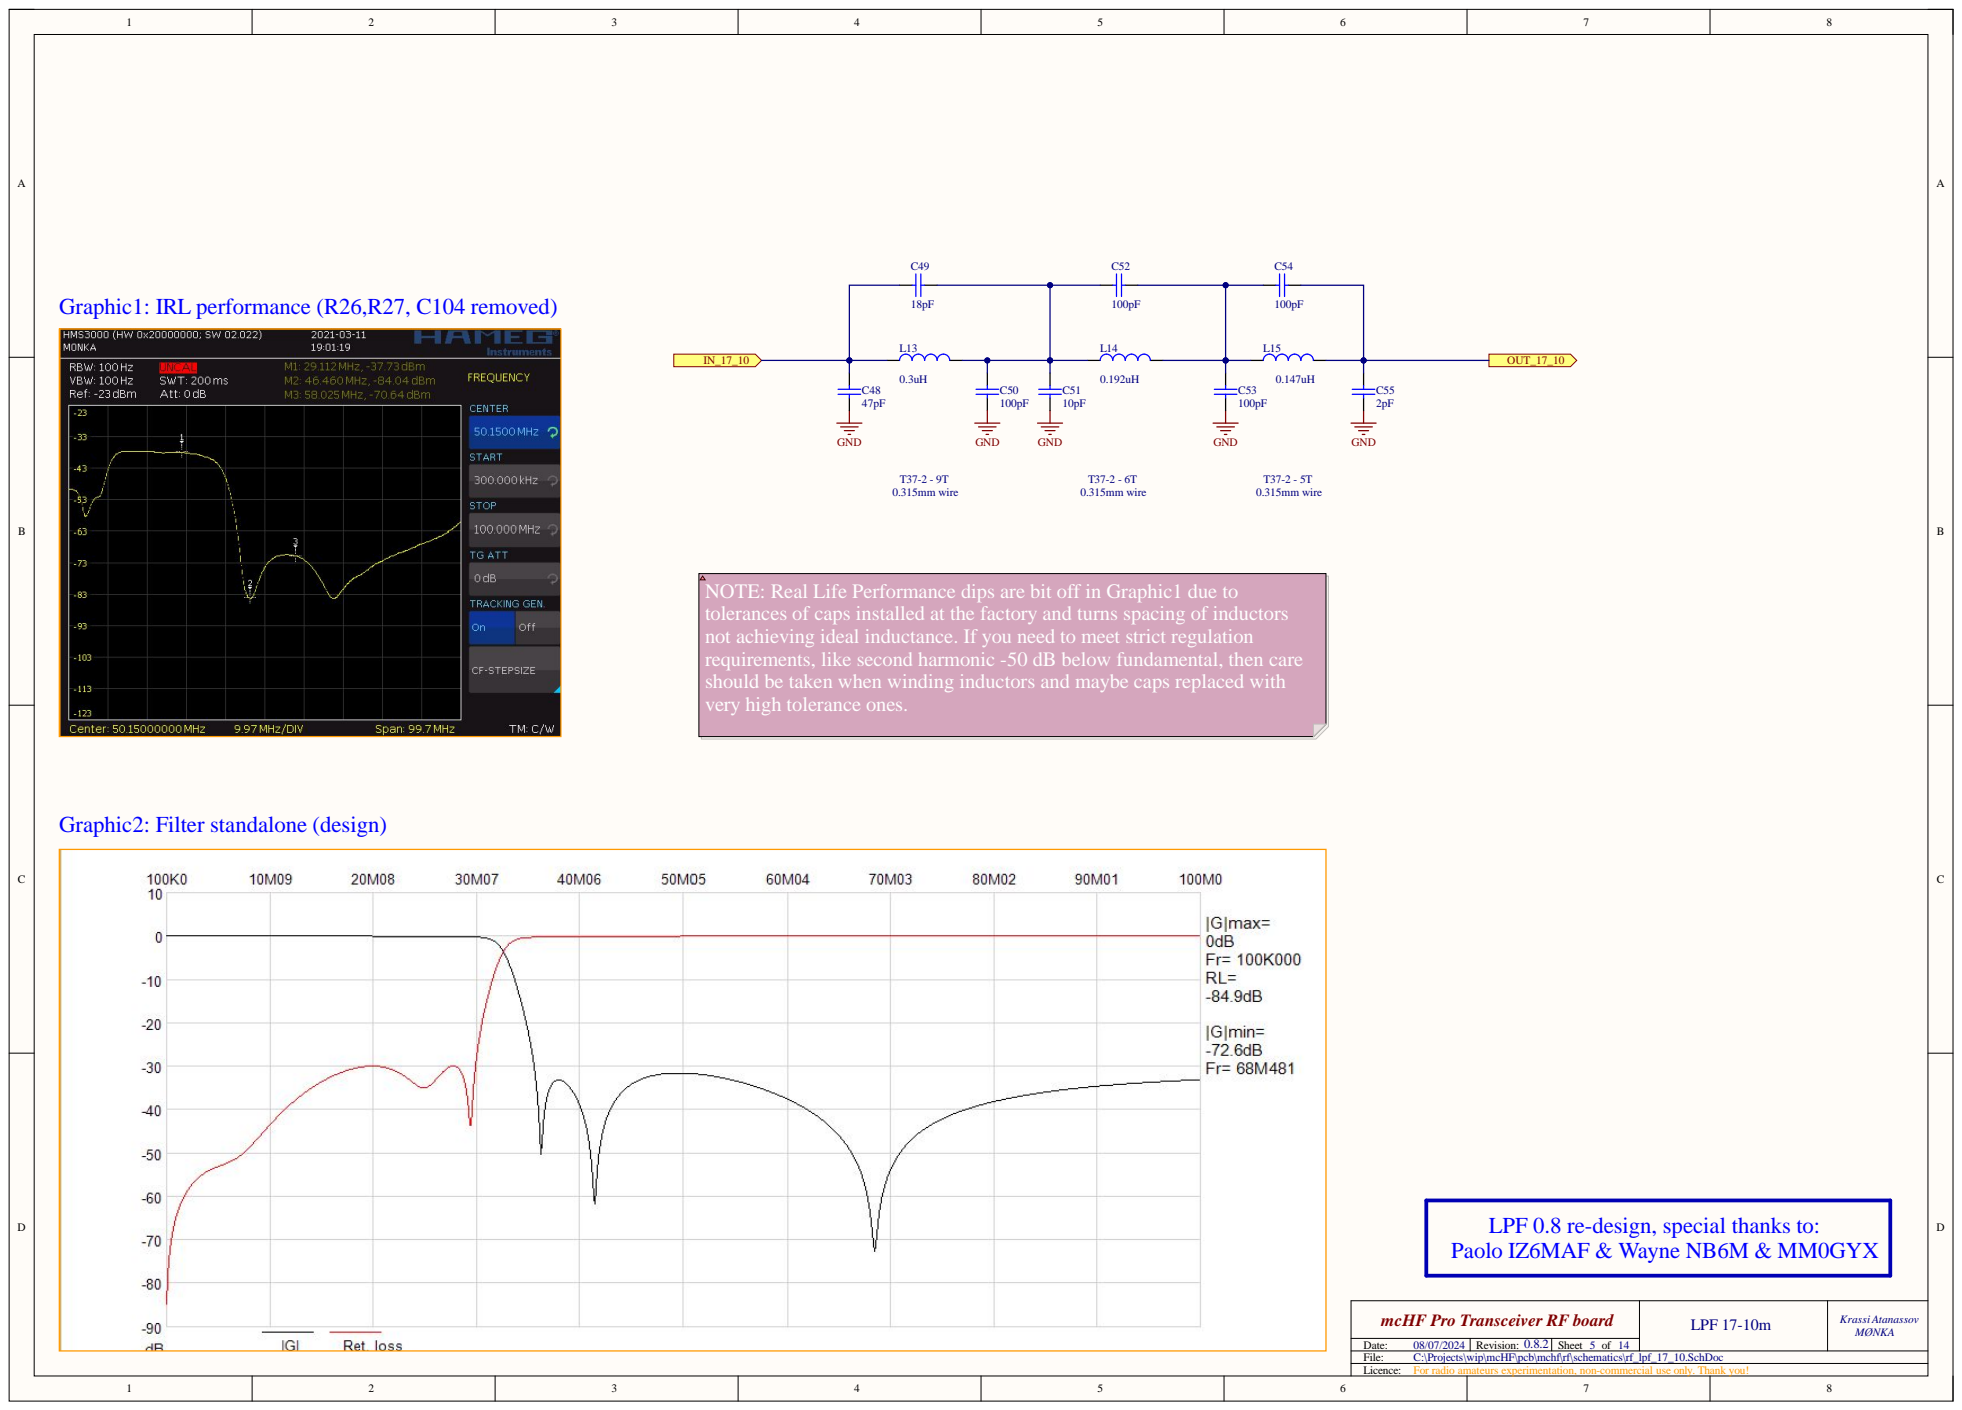
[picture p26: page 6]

NOTE: Real Life Performance dips are bit off in Graphic1 due to
tolerances of caps installed at the factory and turns spacing of inductors
not achieving ideal inductance. If you need to meet strict regulation
requirements, like second harmonic -50 dB below fundamental, then care
should be taken when winding inductors and maybe caps replaced with
very high tolerance ones.

LPF 0.8 re-design, special thanks to:
Paolo IZ6MAF & Wayne NB6M & MM0GYX

C:\Projects\wip\mcHF\pcb\mchf\rf\schematics\rf_lpf_17_10.SchDoc

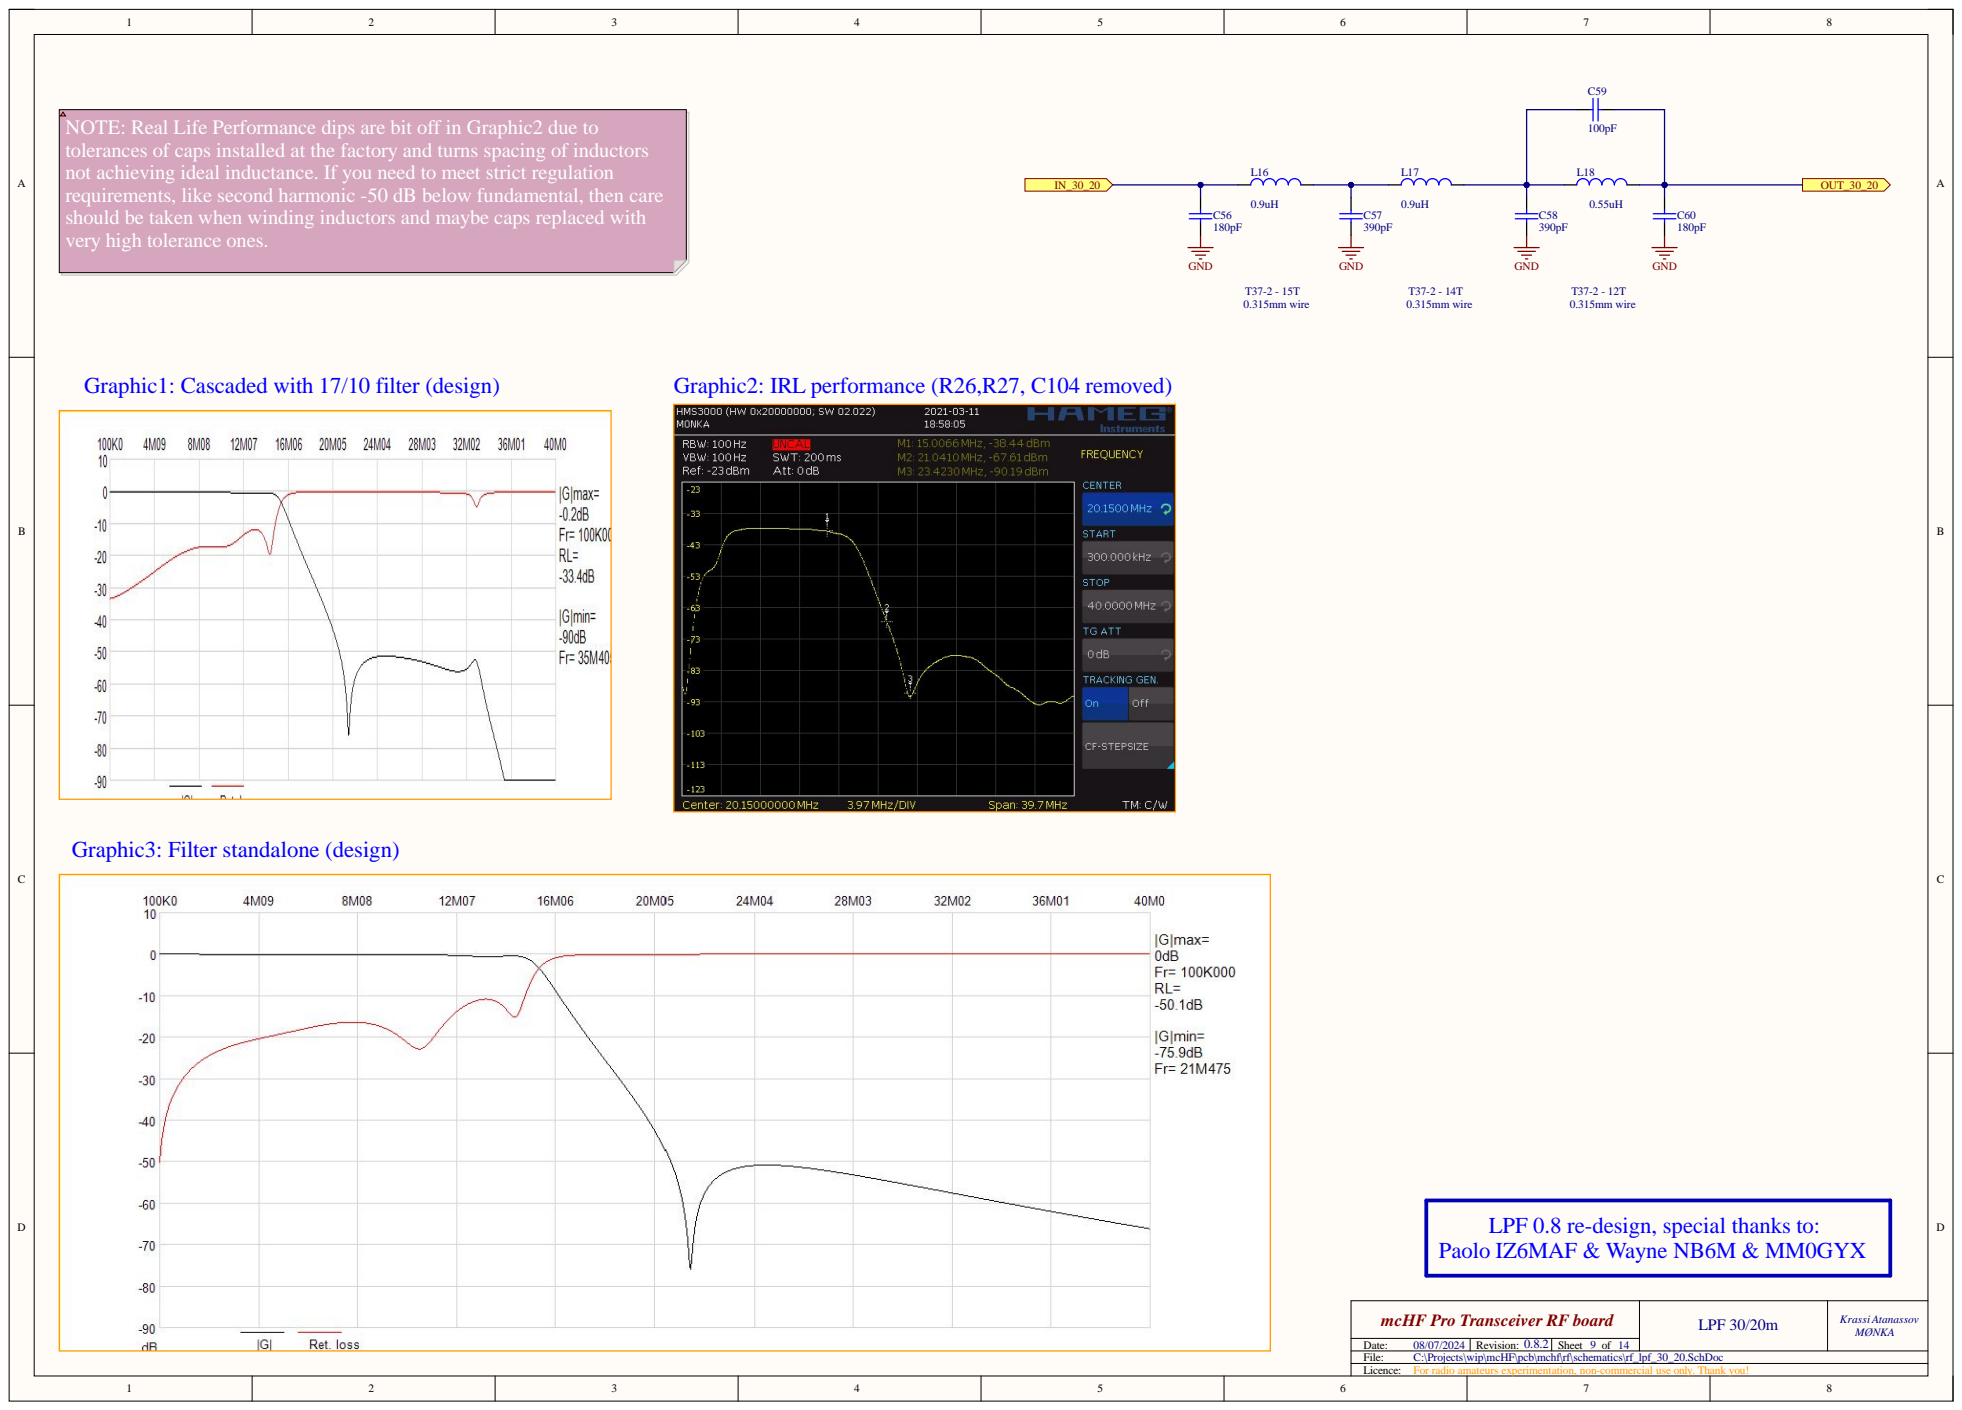
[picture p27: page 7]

NOTE: Real Life Performance dips are bit off in Graphic2 due to
tolerances of caps installed at the factory and turns spacing of inductors
not achieving ideal inductance. If you need to meet strict regulation
requirements, like second harmonic -50 dB below fundamental, then care
should be taken when winding inductors and maybe caps replaced with
very high tolerance ones.

Graphic1: Cascaded with 17/10 filter (design)

LPF 0.8 re-design, special thanks to:
Paolo IZ6MAF & Wayne NB6M & MM0GYX

C:\Projects\wip\mcHF\pcb\mchf\rf\schematics\rf_lpf_30_20.SchDoc

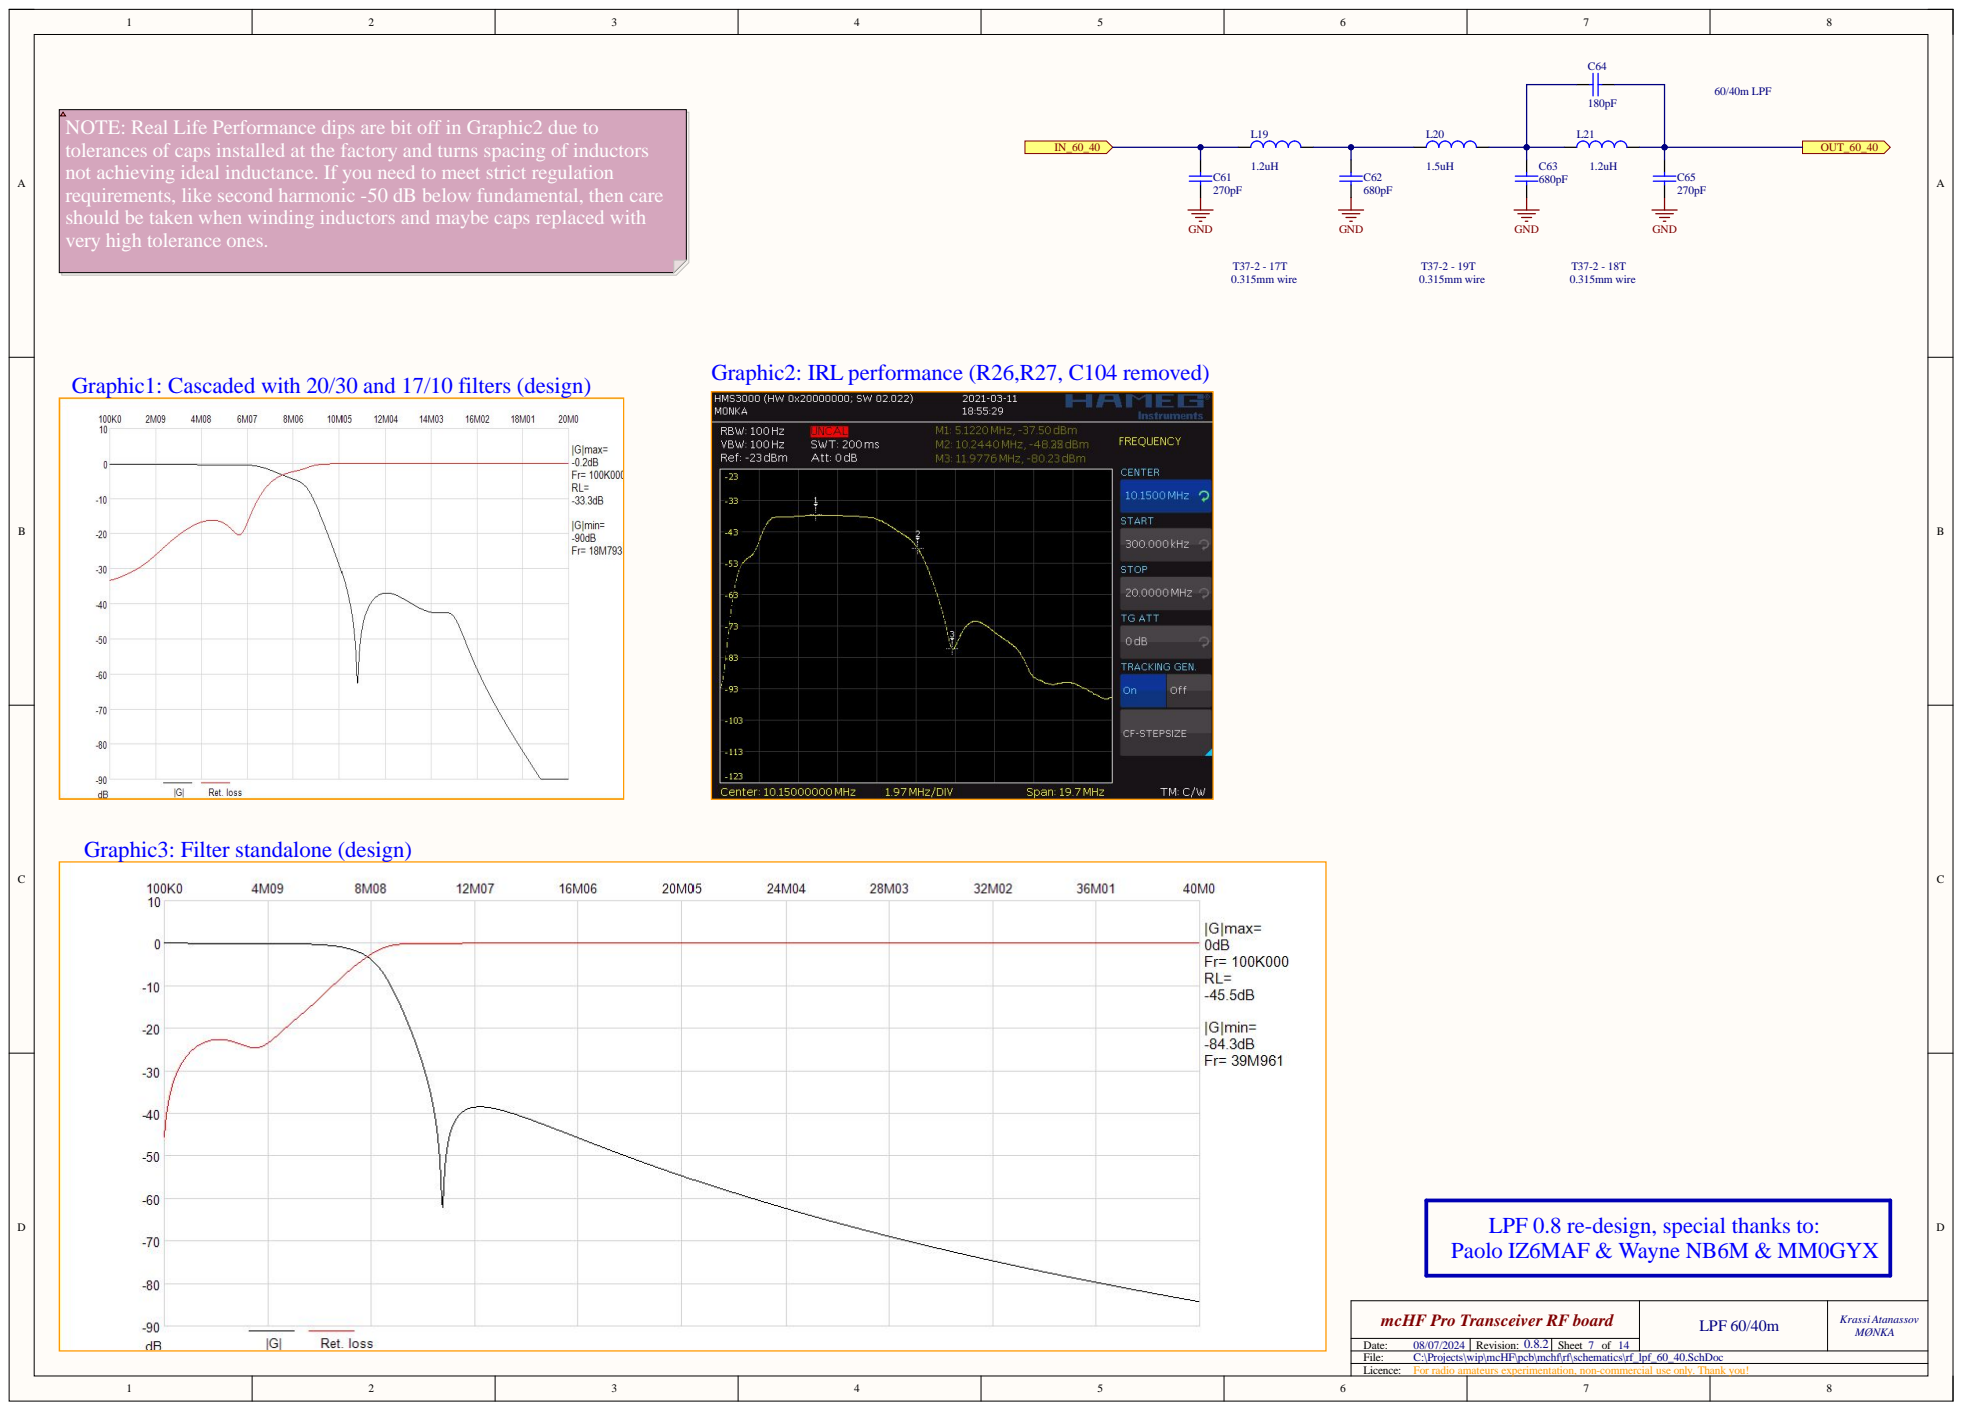
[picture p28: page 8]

NOTE: Real Life Performance dips are bit off in Graphic2 due to
tolerances of caps installed at the factory and turns spacing of inductors
not achieving ideal inductance. If you need to meet strict regulation
requirements, like second harmonic -50 dB below fundamental, then care
should be taken when winding inductors and maybe caps replaced with
very high tolerance ones.

Graphic1: Cascaded with 20/30 and 17/10 filters (design)

LPF 0.8 re-design, special thanks to:
Paolo IZ6MAF & Wayne NB6M & MM0GYX

C:\Projects\wip\mcHF\pcb\mchf\rf\schematics\rf_lpf_60_40.SchDoc

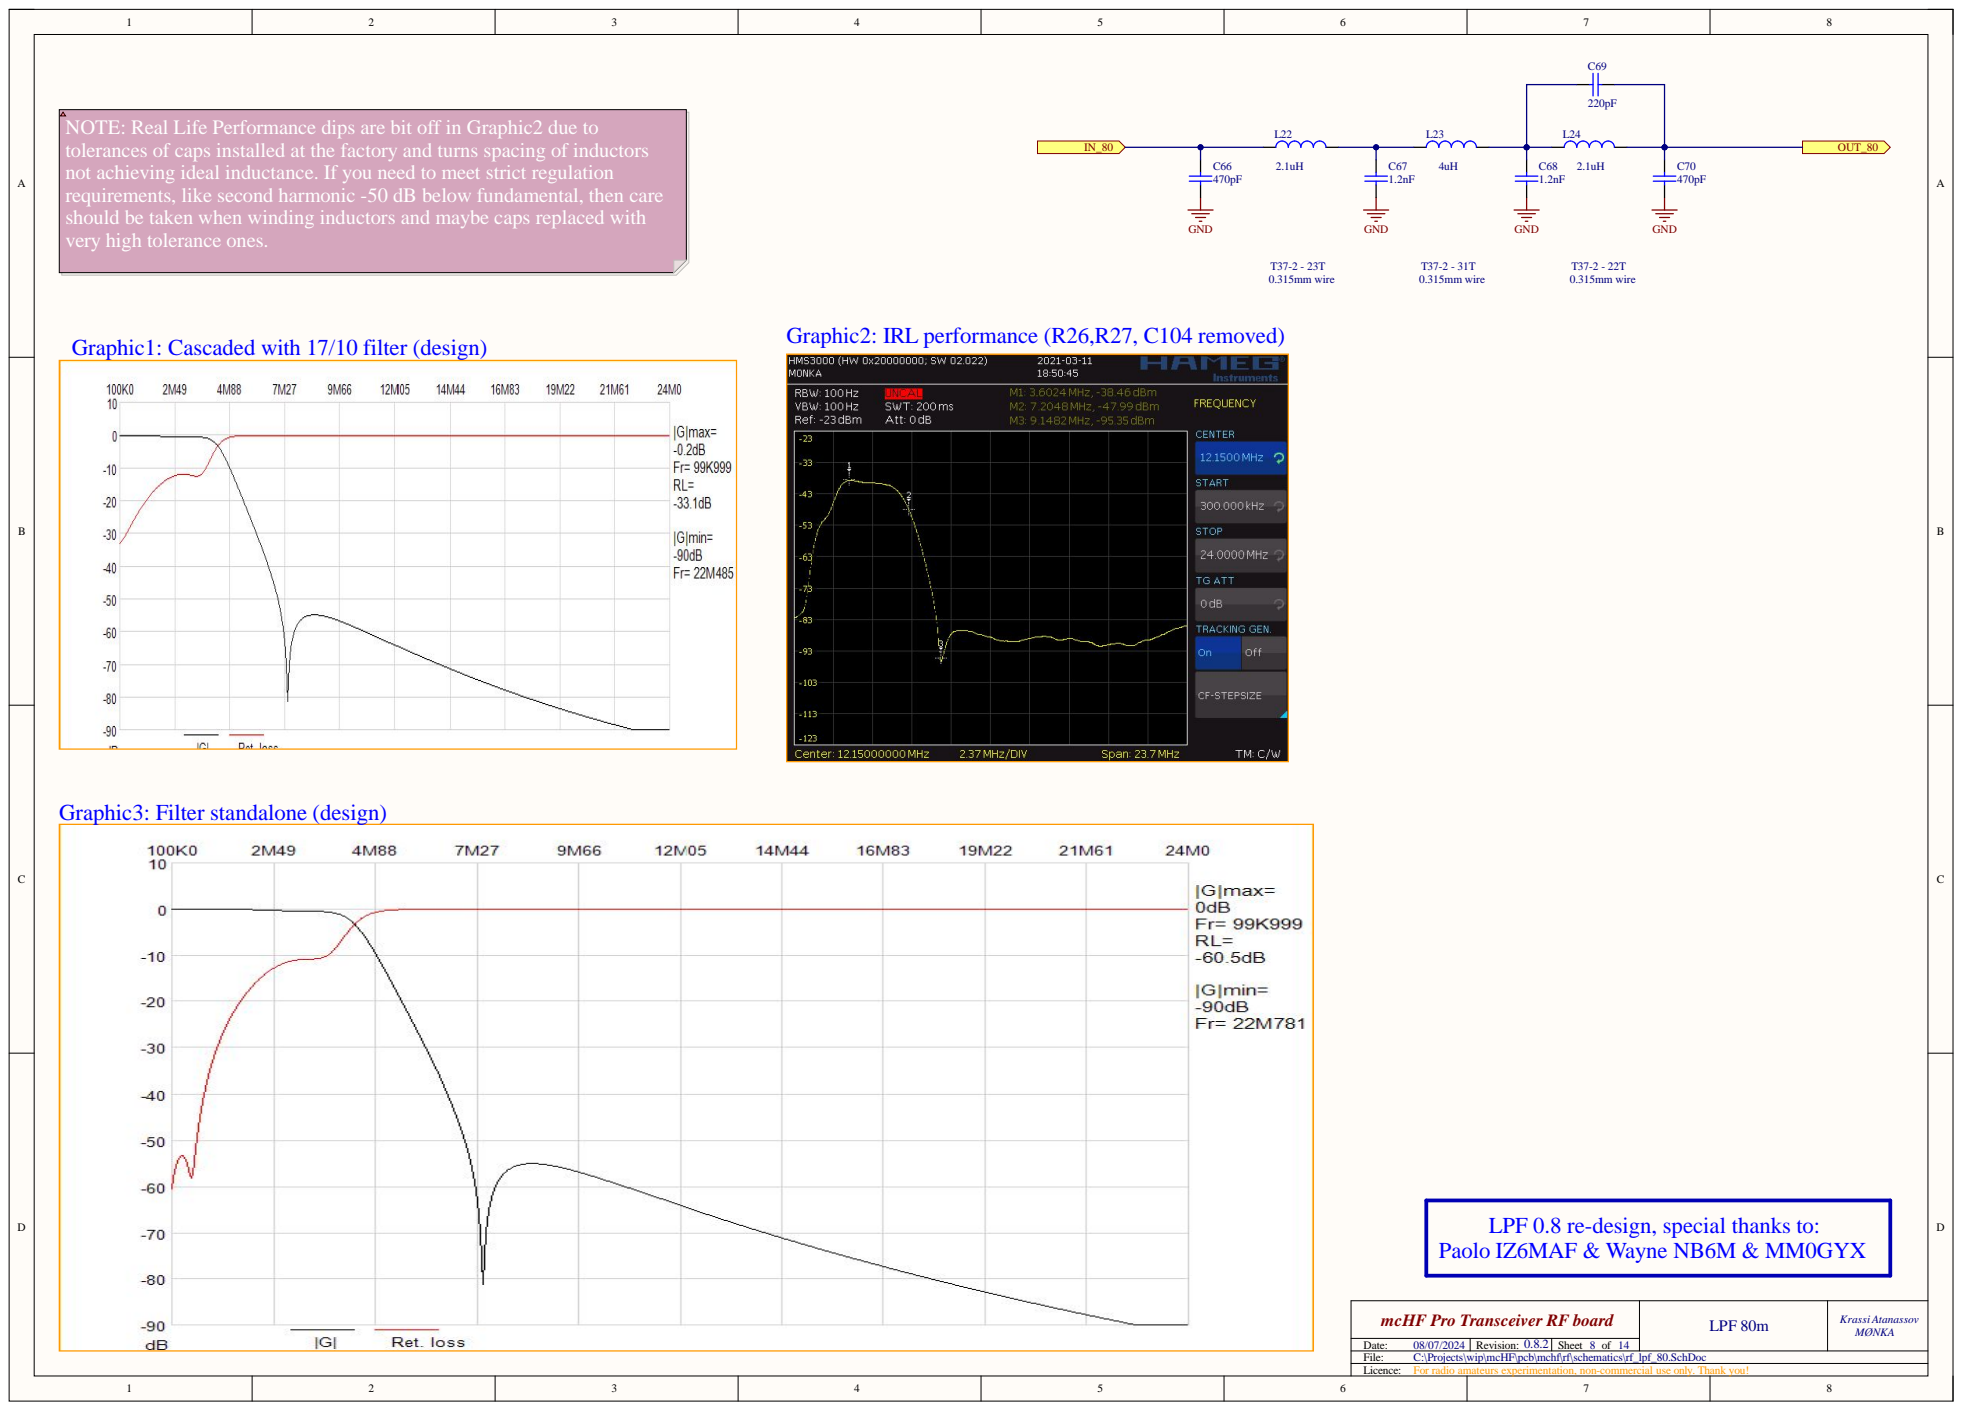
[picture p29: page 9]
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

Graphic1: Cascaded with 17/10 filter (design)

LPF 0.8 re-design, special thanks to:
Paolo IZ6MAF & Wayne NB6M & MM0GYX

C:\Projects\wip\mcHF\pcb\mchf\rf\schematics\rf_lpf_80.SchDoc

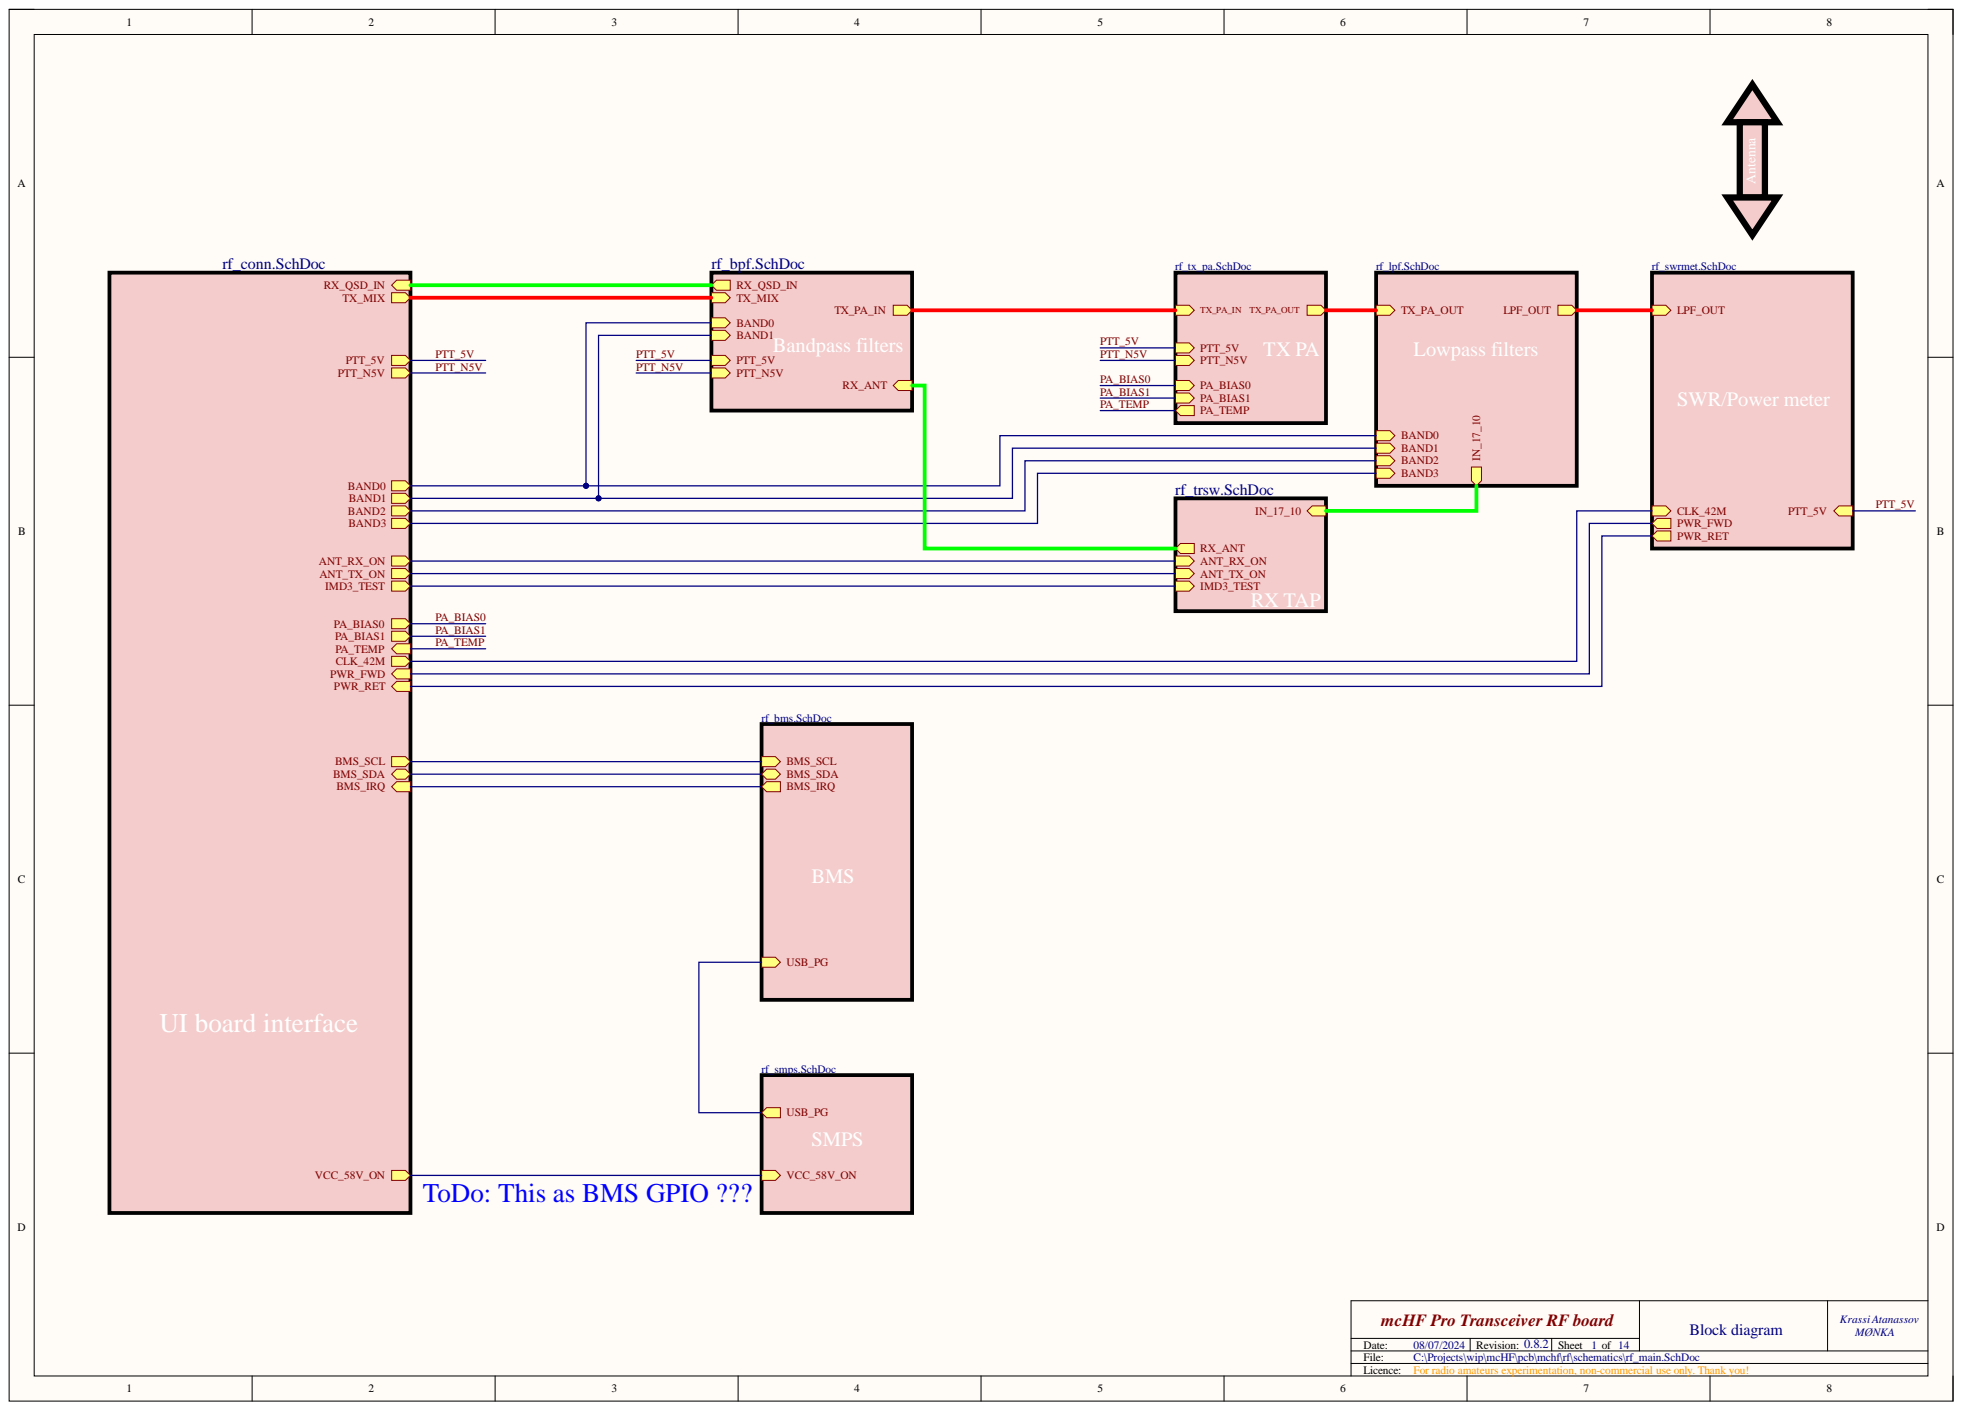
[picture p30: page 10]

ToDo: This as BMS GPIO ???

C:\Projects\wip\mcHF\pcb\mchf\rf\schematics\rf_main.SchDoc


VBUS_1 A4 | B 6 | DP | DP

VBUS_2 A9 GND_2 A12 GND_3 B1 | M H

HF\pcb\mchf\rf\s
xperimentation, non-c


FT50-43 10:1 ratio
0.45mm wire
1T with coax, check mod docs

C:\Projects\wip\mcHF\pcb\mchf\rf\schematics\rf_swrmet.SchDoc


in the ori
is to remove the DC connection between D3 cathode and D4 anode and

very clean results for both transm

instal the 100 nf cap(C79a).

ifies biasing each dev

Now we can set forward bias of D3 to 2 m
recei

ith a value of 2200 ohms .This puts D3 at less than 3 ohms resistance to our

At the same ti

me,now D4, the recei

ver shunt protection diode is total

D4 is now forward biased at over 3 m
ground,protecting the bandpass fi
being in its low state.

iamps and is shorting out any leaked transm
ver

its anode at dc

But at the cathode of D3,we now have 12 -14 volts of reverse bias from the 2n3904 DC sw
here

leakage current of the

in the order of

y conducting and noising up the rf si

Tests showed that anything over 7 volts was enough to keep D3 from occasional
power of 7

l into its RF OPEN condition in transm
loss of the recei

it,we were able to increase the value of C78 to 100nf ,which greatl

gnal at 7mhz and below

If continued operation at over 10

is being done...replacing D3 and D4

HF\pcb\mchf\rf\s
xperimentation, non-c


Approx amplification of this stage is 40 dB
(at 15V on LOAD_16V rail)

available only when powered on

C:\Projects\wip\mcHF\pcb\mchf\rf\schematics\rf_tx_pa.SchDoc

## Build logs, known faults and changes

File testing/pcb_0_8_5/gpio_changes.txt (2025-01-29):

NET					0.8.4		0.8.5
--------------------------------------
LCD_BL_CTRL			PB1			PA9
BST_EN				---			PB1
BMS_IRQ				PA9			---

CLK_42M				PA8			---
BMS_PWM				---			PA8

FREE3				PD12		---
FREE5				PD13		---
BMS_SCL				PB8			PD12
BMS_SDA				PB9			PD13

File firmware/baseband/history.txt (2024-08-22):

#########################################################################
#########################################################################
##                                                                     ##
##  This file contains very short release information, newest up!      ##
##                                                                     ##
##  KA7OEI, Clint                                                      ##
##  DF8OE, Andreas                                                     ##
##  DB4PLE, Danilo                                                     ##
##  DD4WH, Frank                                                       ##
##  and all other contributors                                         ##
##                                                                     ##
#########################################################################
#########################################################################

20170318 [DF8OE]
- switched bootloader and firmware to new STM libs based on HAL
- switched frequency calibration from Hz to ppm (which is frequency-independent)
- introduced RX IQ autocorrection (must be enabled in config menue)
- introduced twin-peaks autocorrection
- I2C-speed now is user-selectable to get max. speed out of your mcHF

20161231 [DF8OE]
- frequency translation +/- 12KHz uses now more efficient algorithm
- plopping / klicking sound at PTT is removed
- I2C Bus speed improved (storing time to serial EEPROM significantly
  shorter now)
- many minor bugfixes
- reduced time for RX <--> TX switching
- implementing a "menu manual" which is automatically created with every
  new build - can be found in support/ui/menu and is published in
  GitHub WIKI

20161115 [DF8OE]
- minor bugfixes
- implementation of touchscreen for 3.2" LCDs
- implementation of freeDV

20160912 [DF8OE]
- implemented keyer mode "ULTIMATIC"

20160820 [DF8OE]
- started working on FREEDV (feature is not enabled in daily snapshots yet)
- implemented using of big USB plug for USB-stick bootloader instead of small plug
- many minor bugfixes

20160819 [DF8OE]
- reworked DDS code for better quality
- reworked TX IIR filter for better uppression of spurious signals
- added new TX filters 'WIDE BASS' and 'WIDE TREBLE'
- added possibility of adjusting BASS and TREBLE in TX mode
- bugfix EEPROM detection 24LC1025
- added EEPROM 24LC256 to usable EEPROMs
- added 'DEBUG/EXPER. SETTINGS' to menu structure. For now only item is enabling
  audio out via USB during TX
- bugfix spectrum and spectrum light
- bugfix CW frequency offsets
- many code simplifications and minor bugfixes
- added MAC support for Makefile
- reworked TX audio filters for improving spurious suppression
- reworked TX software chain for better signal quality
- added "Zoom FFT / magnify" x2 x4 x8 x16 x32
- added touchscreen support for Zoom FFT / magnify"
- many minor bugfixes

20160713 [DF8OE]
- minor changes in LCD init for parallel use
- new ui for encoder boxes
- CW sidetone now available when TX is disabled
- smoother magnified spectrum display
- added dBm/Hz display for RX signals
- improved  Responsiveness  of the buttons and knobs under heavy load:
  For a long time the UI responsivness was harmed if certain CPU intensive
  filters were enabled. This is now gone.
- several issues with the spectrum display have been sorted out: It is now
  smoother and  also has the center line properly working
- the display code incorporates changes to support all known display and
  controller types: No "white screen" issues have been reported for quite a while.
- the CW sidetone is now audible even if TX is disabled: practice your CW skills
  with the mcHF without actually transmitting
- added some hardware detection code: The Hardware Info Menu now tells you how much Flash,
  RAM and which CPU type signature (413h -> STM32F405/07/15/17, or 419h ->STM32F42x/3x)
  your mcHF has.
- the TUNE mode is now able to generate a two tone signal to better calibrate your mcHF
  (PA Adjustment Menu).
- added support to fix the TwinPeaks without rebooting: If you get occasionally a mirrored
  signal in the mcHF which goes away after rebooting, you now can try to restart the I2S
  stream by tapping on the DSP box (if you have touch enabled) or by going into the Standard
  Menu and selecting "Restart I2S". No need to reboot.
- quite a number of bug fixes to improve stability and fix some more or less annoying issues.
- bugfix translation +6khz/+12khz not working

20160515 [DF8OE]
-released first stable following new versioning scheme

20160511 [DF8OE]
- bugfix: temperature C/F not stored
- bugfix: encoder2 state corrected when leaving menu
- disabled blue digits when tuning is faster than SI570 can follow

20160510 [DF8OE]
- bugfix: when in syncAM-mode now AM is reported instead of SSB
- minor and major bugfixes regarding CW TX
- swapped to actual CMSIS-Libs: improvements in many places to more acurate DSP functions
- improved accuracy of SNAP function
- added touchfunction: "reset of 100/10/1 Hz to ZERO": touching on "TUNE" box
- added new graphic "Spectrum light"
- improved accuracy of touchfunctions
- bugfix continuos temperature compensation of LO
- changed some colors for better readability
- added touchfunction for METER change: touching on meters
- added manual notch filter
- added peak filter
- added bass/treble adjustment
- again improvement of LCD SPI speed
- started LCD layout simplifications

20160413 [DF8OE]
- again bugfix "white screen issue" on some left LCDs
- bugfix loading defaults
- signal line in spectrum now always is in front of spectrum
- added poweroff and reboot to "defaults loading screens"
- expanding "button test function" to encoders
- DSP NR has joined stable usage again!
- added config "Cat In Sandbox" where CAT 'set'- commands do not affect actual band settings

20160405 [DF8OE]
- new FilterPath-structure replaces old filter selection method
- added SAM demodulation for weak AM signals
- bugfix TX path while in translated mode
- changed filter character at low frequencies in TX for male voices with high lower frequencies
- improved TX IQ balance and phase adjustment SSB/CW
- bugfix "white screen issue" on some LCDs
- bugfix TX filter ON/OFF was swapped
- started snap function for SAM (experimantal)

20160317 [DF8OE]
- added dynamically tuning, activated/deactivated by tapping on step size 
- hopefully improved USB audio recongnition of all Windows versions and Linux
- removed scope/waterfall blocking in SPI mode
- added LCD mode difference to dynamic tuning
- more speed for LCD parallel/SPI
- added possibility of swapping SPI to 50MHz instead of 25MHz (ununsed at the moment)
- added more filters: 4.2k, 4.4k, 4.6k, 4.8k, 5k, 5.5k,6k,7k,8k,8,5k,9k and 9.5k
- completely new functions for menu with submenus
- slightly improvements in display colors and font usage
- bugfix SI570 crashes when tuning is very fast and in very large steps
- bugfix spectrum/waterfall stopped during tuning
- grouped buttons EXIT-PREV-NEXT for better usability
- state of dynamic tuning is stored ow
- started new filter selection method (FilterPath - experimantal!)

20160228 [DF8OE]
- corrected TX/RX switching of AFG/STG and RIT/WPM in CW
- added USB audio functions
- added #335 Tune Power Level for antenna tuning with specific power
- added USB I/Q-Audio
- reworked much code for better serviceability
- activatiing ALC for USB-I/Q-input signals
- added filters 2.7KHz and 2.9KHz as LPF and BPF

20160213 [DF8OE]
- adding new translate modes +/- 12KHz
- added 5KHz tuning steps
- added possibility to use filters as LPF (not with center frequency)
- rework of display code for speed up
- further code reworking
- FM only allowed on 10m when #029-LSB/USB Auto Select is ON
- touchscreen tuning disabled when frequency lock set
- touchscreen steps 5KHz in AM mode
- bugfix in EEPROM routines

20160203 [DF8OE]
- CAT implementation finished using small USB plug (FT817 protocol)
  Linux recognizes serial device out of the box, Windows needs drivers from STM:
  http://www.st.com/web/en/catalog/tools/PF257938
- minor bugfixes in reworks
- started displaying GitHub-versioning in splashscreen for better firmware identifying

20160201 [DF8OE]
- beginning CAT implementation
- beginning DIGI-modes implementation

20160130 [DF8OE]
- huge reworking in menue / text formatting
- reworking in configuration save and read functions
- reworking for improving speed, saving code space and better readability
- reworking of SPI LCD code for improving speed
- FM now enabled by default (it is stable)

20160125 [DF8OE]
- many bugfixes in audio functions (out of boundary errors)
- removing all code errors which causes compiler warnings
- now it is possible to build with compiler optimization
- rework of Makefile

20160122 [DF8OE]
- fixed bug "60m 5W power adjust"
- fixed bug "long press TUNE in TX disables tune toggle"
- fixed many compiler warnings (cleanup - thanks to hogthrob!
- removed tuning borders, now colour of digits indicate:
  white == within official tuning range and tuned
  yellow == outside specs, but often works
  red == completely outside specs or no I2C communication to SI570 possible

20160103 [DF8OE]
- first release which supports future expansion pcbs for adding
1) RX 12KHz...80MHz, TX 160m, 6m and 4m
2) RX 80MHz...2000MHz, TX 2m, 70cm and 23cm
160m TX and RX is rudimentary supported without expansion board.
Filters for 80m are used. It works (not perfect at all) and you have
some small gaps at 160m where LO does not work. But a nice preview at all...
Of course will work much better with fitted expansion pcb ( I hope it will
be finished in the first 6 months of 2016)!!!
You can ge a preview how it looks if mcHF selects new bands if you touch
":" on touchscreen in menu #199 at recent lines (touching toggles pcb present
or not "hard-coded"). Of course frequency display is RED on any band < 160m or
> 10m because LO does not work out-of-the-box without needed expansion board(s)...

################## IMPORTANT INFORMATION ##################
Because of EEPROM addressing for band specific storage *must* be continuously
EEPROM structure (regardless virtual/serial) is broken with the adding of new
bands!!! If you take this version YOUR CONFIGURATON SETTINGS WILL BE LOST!!!
Please write down your actual configuration settings.

If this is the first firmware you install you have to do nothing special - only
upgrading from older versions are affected.

At first start after upgrading from older firmware version than
0.219.26.15 you must first reset all settings to default by press & hold
MENU-SPLIT-TUNE simultaneously while powering up and release after warning
screen appears. Then power down via power button  After startup enter all
configuration data you wrote down.

Good news at all:
If you take this new version and somedays pcbs are available there is no more
changing in EEPROM structure. Storage is organized for all possible new
bands regardless if they are active or not. This only consumpts ~40 Bytes of
virtual/serial EEPROM space and does not affect anything else.
############################################################

20160102 [DF8OE]
- added autodetection of 7ppm SI570 devices using regs 13+

20151217 [DF8OE]
- added "working" state display for #341

20151215 [DF8OE]
- improved data accquisition of touchscreen, now hopefully more accurate
- solved "2.3khz filter issue"

20151214 [DF8OE]
- added "power off without saving settings" by pushing BAND+ and POWER simultanusly
- added possibility of power-off and reboot in button test mode

20151214 [DF8OE]
- added touchscreen support. You have to do the following modifications:

if LCD is in parallel mode:
remove R30, R31, R32
put connections between:
R30/R33 (PC2) to TP_SDO of LCD
R31/R34 (PC3) to TP_SDI of LCD
R32/R35 (PB13) to TP_SCK of LCD
Header Pin7 (PA4) to TP_IRQ of LCD
P8 Pin1 (PA9) to TP_CS of LCD

if LCD is in SPI mode:
same as above, but do not remove R30, R31, R32 (or wires if you use HY28B in SPI mode)

You can see signal names on back side of LCD. If you have soldered and cannot remove,
ask google for a picture of backside of HY28B - there are many.

With this mod you loose DAC which was former used for rf attenuator. This signal is
unused now and I supose it never will be used in future. Intermodulation while receiving
very strong signals can be removed by modifying rf preamp for better IP3.

After modifying and applying firmware newer/equal 0.219.26.13 in hardware menu #199
touchscreen is listed. When you enter BUTTON TEST MODE coordinates are shown if
you touch LCD screen. If this test is successful, you can use touchfunctions.

At the moment the following functions are supported:
- tapping right hand waterfall/scope bar: toggling wf/scope
- tapping left hand waterfall/scope bar: toggling wf/scope magnifying x 2
- tapping at a frequency/peak shown in wf/spectrum (lower part of the wf/scope) will tune to the tapped frequency

In future much more touch-functions will be added.

20151206 [DF8OE]
- added adjustment menu item #341 "Reset Ser EEPROM" to clean up misidentified EEPROM

20151206 [DF8OE]
- added menu item #197 "Backup Config to virtual EEPROM"
- added menu item #198 "Restore backup config to serial EEPROM"
Both items are only available i serial EEPROM is fitted. Now you can restore to
"working coniguration" if you have destroyed the acive one insteade of only
loading default values.

20151201 [DF8OE]
- added support for 24LC512 (64kb), 24LC1026 (128kb) and AT24CM02 (256kb). All these
can be be fitted to board without any additional changings (no wire between pin8 and
pin3 needed). Only if 24LC1025 is used this wire must be added.

20151130 [DF8OE]
- added detection of unsopported EEPROMs

20151126 [DF8OE]
- completed serial EEPROM support of 24LC1025
You have to add connection between pin8 and pin3 of 24LC1025
!!! 24LC01/02/04 are too small and config data cannot fit so that they are UNSUPPORTED !!!
At first start with fitted serial EEPROM and this (or newer) firmware serial EEPROM is
autodetected and then (if memory is big enough) virtual EEPROM is copied to serial
EEPROM. From now on all write functions are done with serial EEPROM and no longer
to virtual EEPROM. You can see if at menu item #199 serial EEPROM is written in
green letters. If so, it is in use. If it is in red letters, fitted serial EEPROM do
not have enough memory for storing settings.
It is important that EEPRM is brand-new or if not it is written 0xFF to all
cells before you solder it. Autodetection depends on a completely "empty" device!

20151115 [DF8OE]
- I named this back-rolled version for continuity to 0.219.26.6

20151111 [DF8OE]
- added menu "190" hardware-info
- beginning of EEPROM including (it is detected if present but not used in this version)

##################
20151111 Version 0.219.26.5  [KA7OEI]
- Fixed problem with 2.3k filter adjustment not being possible except in FM.
- Code cleanup to fix some warnings/function definitions.
##################
Comment DF8OE: 
I reverted this because of some heavy problems

20151103 Version 0.219.26.4  [KA7OEI]
- Increased size of 60 meters to accommodate some EU frequency useages
- Added function to reset frequencies/modes to default:  Press-and-hold F2 and F4 during power-up
- Added adjustment menu item "MemFreq Lim Disable".  When "ON", there are no limits imposed on
frequency bands that may be stored in each "band-memory" location.  WARNING:  This can cause bands to be
stored in random order and also make it easier to put different bands in VFO-A versus VFO-B which can
cause relay-switching/timing issues!

20151101 Version 0.219.26.3  [KA7OEI]
- Rewrote "AGC" handler for FM mode to reduce processing overhead when in FM.  The AGC does
not actually function in FM (there is no need for it!) but the value is calculated only to drive
the S-meter.  (In 0.219.26.0-2 the S meter did not work in FM.)

20151030 Version 0.219.26.2  [KA7OEI]
- Fixed problem with change detection of "Minor" version

20151029 Version 0.219.26.1  [KA7OEI]
- Fixed problem with key beep on/off
- Fixed TUNE in CW mode
- Added support for change detection of "Minor" version (e.g. "219", above)

10/28/2015 Version 0.0.219.26  [KA7OEI]
- Added "Load Defaults" obtained by holding F1, F3 AND F5 on power-up.  Once unit has
powered up, the user would DISCONNECT power to preserve the OLD settings or PRESS-AND-HOLD the
POWER button to save the new (default) settings to EEPROM and power down.  The unit halts on this
screen indefinitely.  Some defaults changes to be more useful.
- Added "button test" function where pressing-holding any button (other than power) during power-up will
display the button being being pressed (or the one with highest precedence if multiple) and the number
of buttons being pressed.
- Problem in which "PREV" and "NEXT" buttons on menu could skip last screen of "Configuration"
menu has been fixed.
- Fixed problem in which line under screen that indicates bandwidth/settings did not change under some
conditions (e.g. switching from one band to another where the same filter/settings were used, but
a different sideband was used).  Added "unconditional" update of this line when changing bands.
- Added "INVGray" and "Blue" waterfall palettes.
- Streamlined code related to DSP NR and Notch.
- Added keyboard beep.
- Completely rewrote AM demodulation to reduce CPU loading.
- Fixed problem (from 0.0.219.24) in which there were dead spots in Si570 tuning (incorrect FDCO Min/
max values).
- Added function where pressing-holding G3 will generate sidetone equivalent to CW offset, used for
"Spotting", in CW/LSB/USB modes/
- Added FM modulation/demodulation with squelch, subaudible tone encode/decode and tone burst.

- The following files have been added (I hope that I have them all here!):

  FILTERS:  iir_15k_hpf_fm_squelch.h   - Filter for squelch noise detection
            iir_2k7_tx_bpf_fm.h        - Filter for FM transmit audio

  AUDIO:    fm_dds_table.h             - DDS/NCO lookup table for FM/Subtone/Burst generation
            fm_subaudible_tone_table.h - List of subaudible tones for encode/decode

10/11/2015: Release of Version 219.24

10/10/2015 (KA7OEI)
- added "Load EEPROM default": Press-and-hold F1+F3+F5 on power-up, read and follow in-screen instructions
- bugfix "bandwidth indicator sometimes wrong when band was changed"

10/02/2015 (DF8OE)
- minor bugfixes in bootloader

09/30/2015 (DF8OE)
- creation aof new bootloader which allows firmware updates via USB-key

09/15/2015 (DF8OE)
- added autodetection of HY28A / HY28B in SPI mode (hardware changing needed --> see wiki on github pages

09/07/2015 (DF8OE)
- created makefile (thanks to DL4SAI)
- commented out of some curious lines which prevent building using makefile
- building is now possible with makefile but there is one issue to find:
  firmware binary is 600 bytes shorter than binary generated by eclipse and does only show splashscreen, then ends

08/19/2015 (DF8OE)
- added detection of SI570 hardware address (possible addresses 0x50 / 0x55)
- added workaround for malfunction of startupfrequency detection during unattended boots or bootloops
- merging Eclipse and CooCox configuration to one package so that both IDEs can be used

09/09/2015 (DF8OE)
- I merged Clint KA7OEI new released version 219.22. This new version now is named 219.23 and will be the base
for all future firmware developments - I hope...

09/08/2015 (DF8OE)
- makefile is now working

09/05/2015 (DF8OE)
- start: I used mcHF Firmware Source 219.19 from Clint KA7OEI as base of new mchf-firmware-community working with GITHUB

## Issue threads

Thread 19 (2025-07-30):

schematic v0.8

BOAndy1985, 2025-07-30:
Hello Chris, I have a question: are there any schematic plans for the new version? If so, I would like to have the circuit boards manufactured.

m0nka, 2025-07-30:
Hey! I am still doing some changes, latest i think will be 0.8.6. Right now i have only the mix board updated.

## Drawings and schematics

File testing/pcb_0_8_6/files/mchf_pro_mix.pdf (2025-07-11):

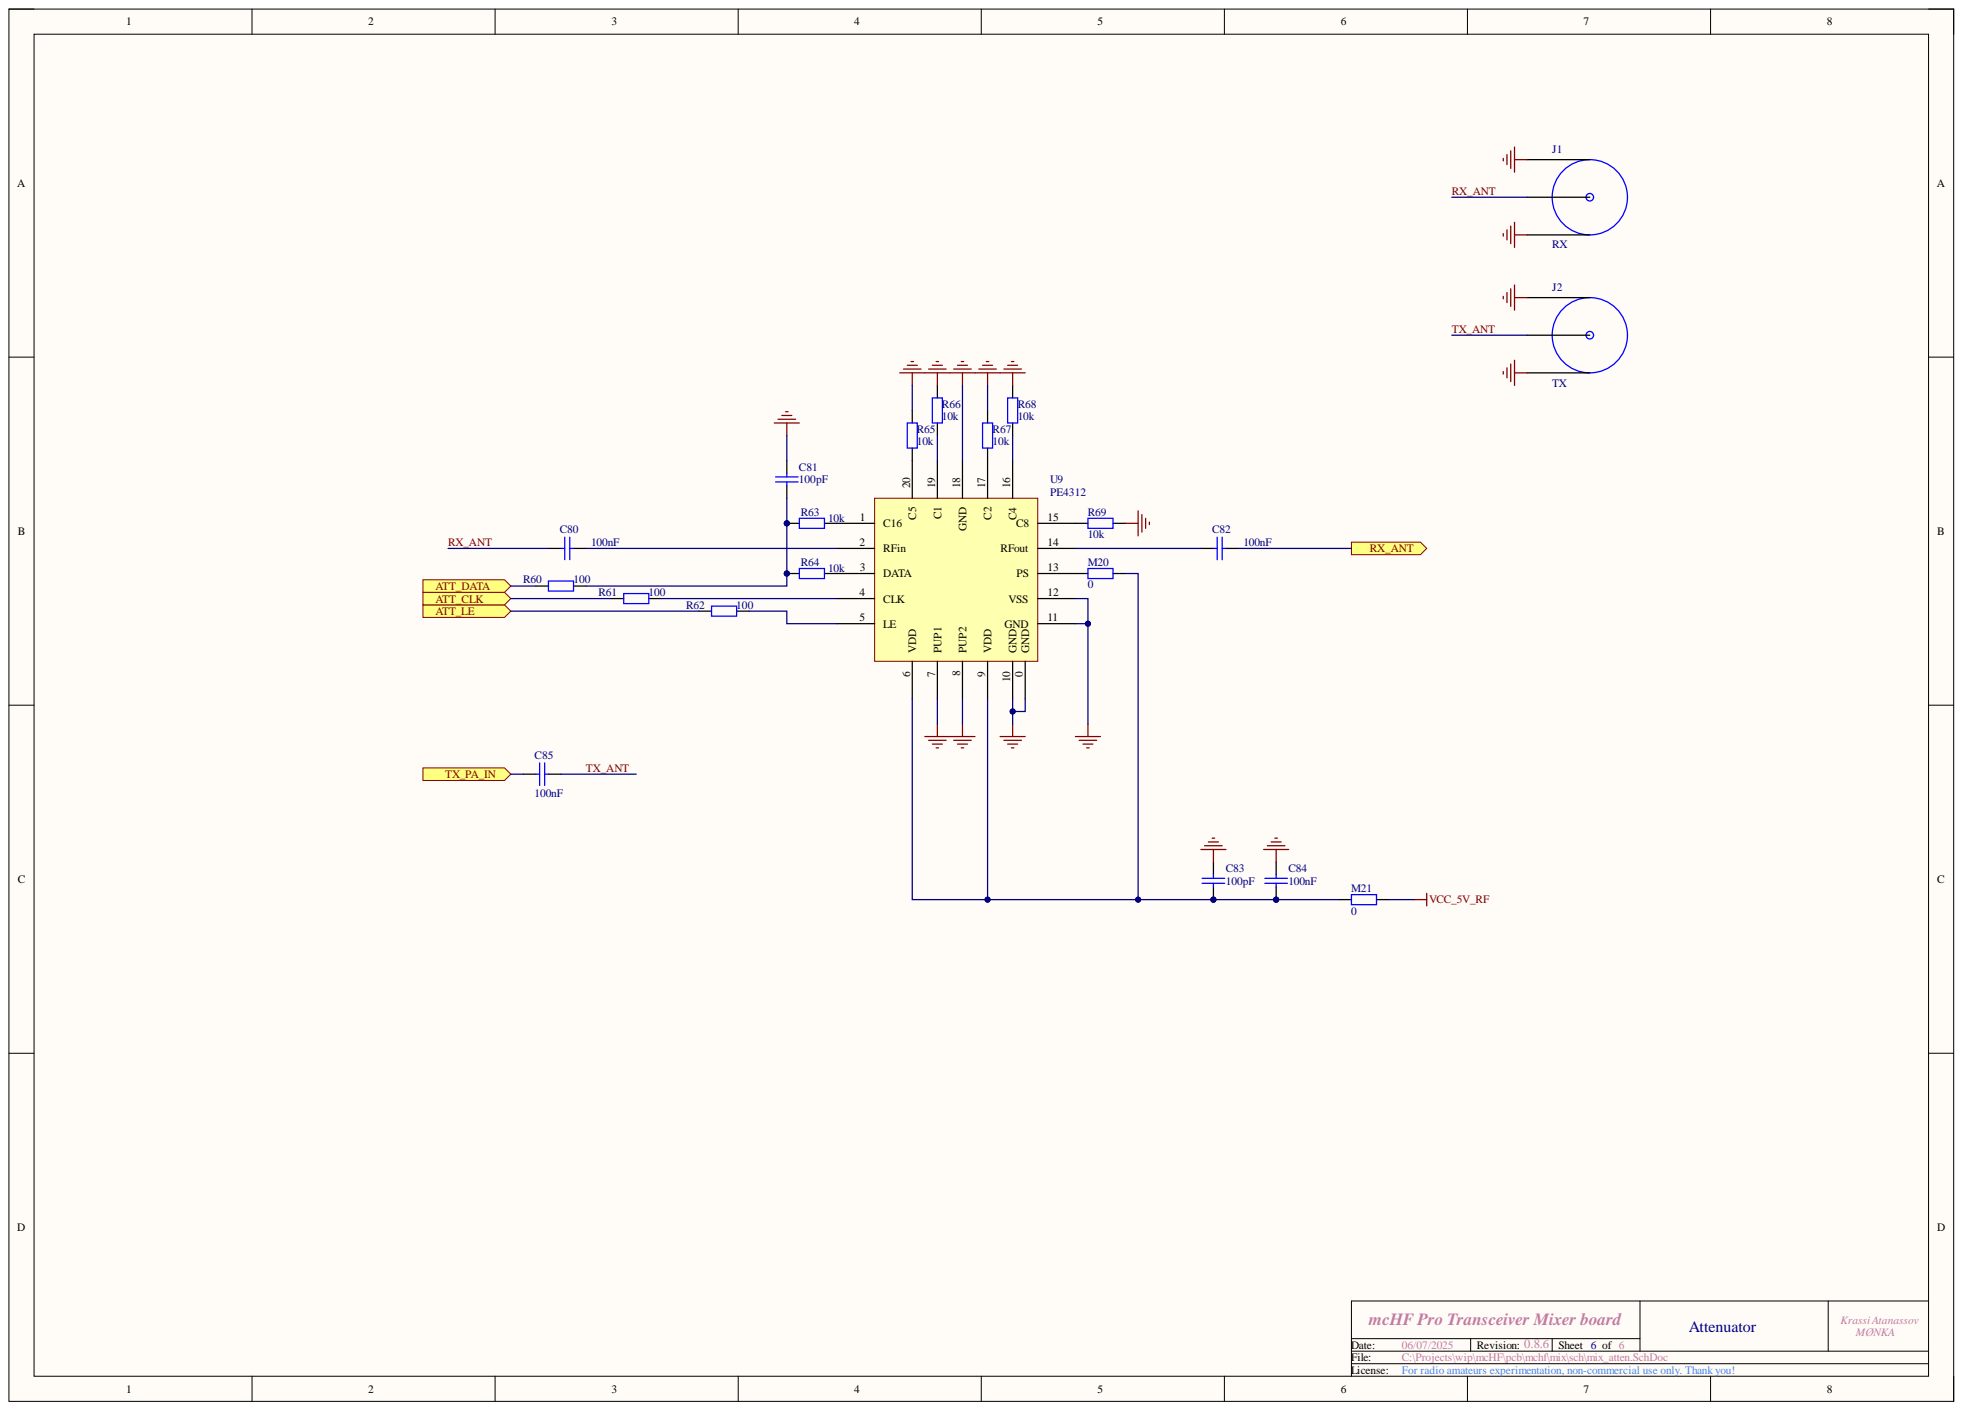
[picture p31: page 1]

mcHF Pro Transceiver Mixer board

C:\Projects\wip\mcHF\pcb\mchf\mix\sch\mix_atten.SchDoc

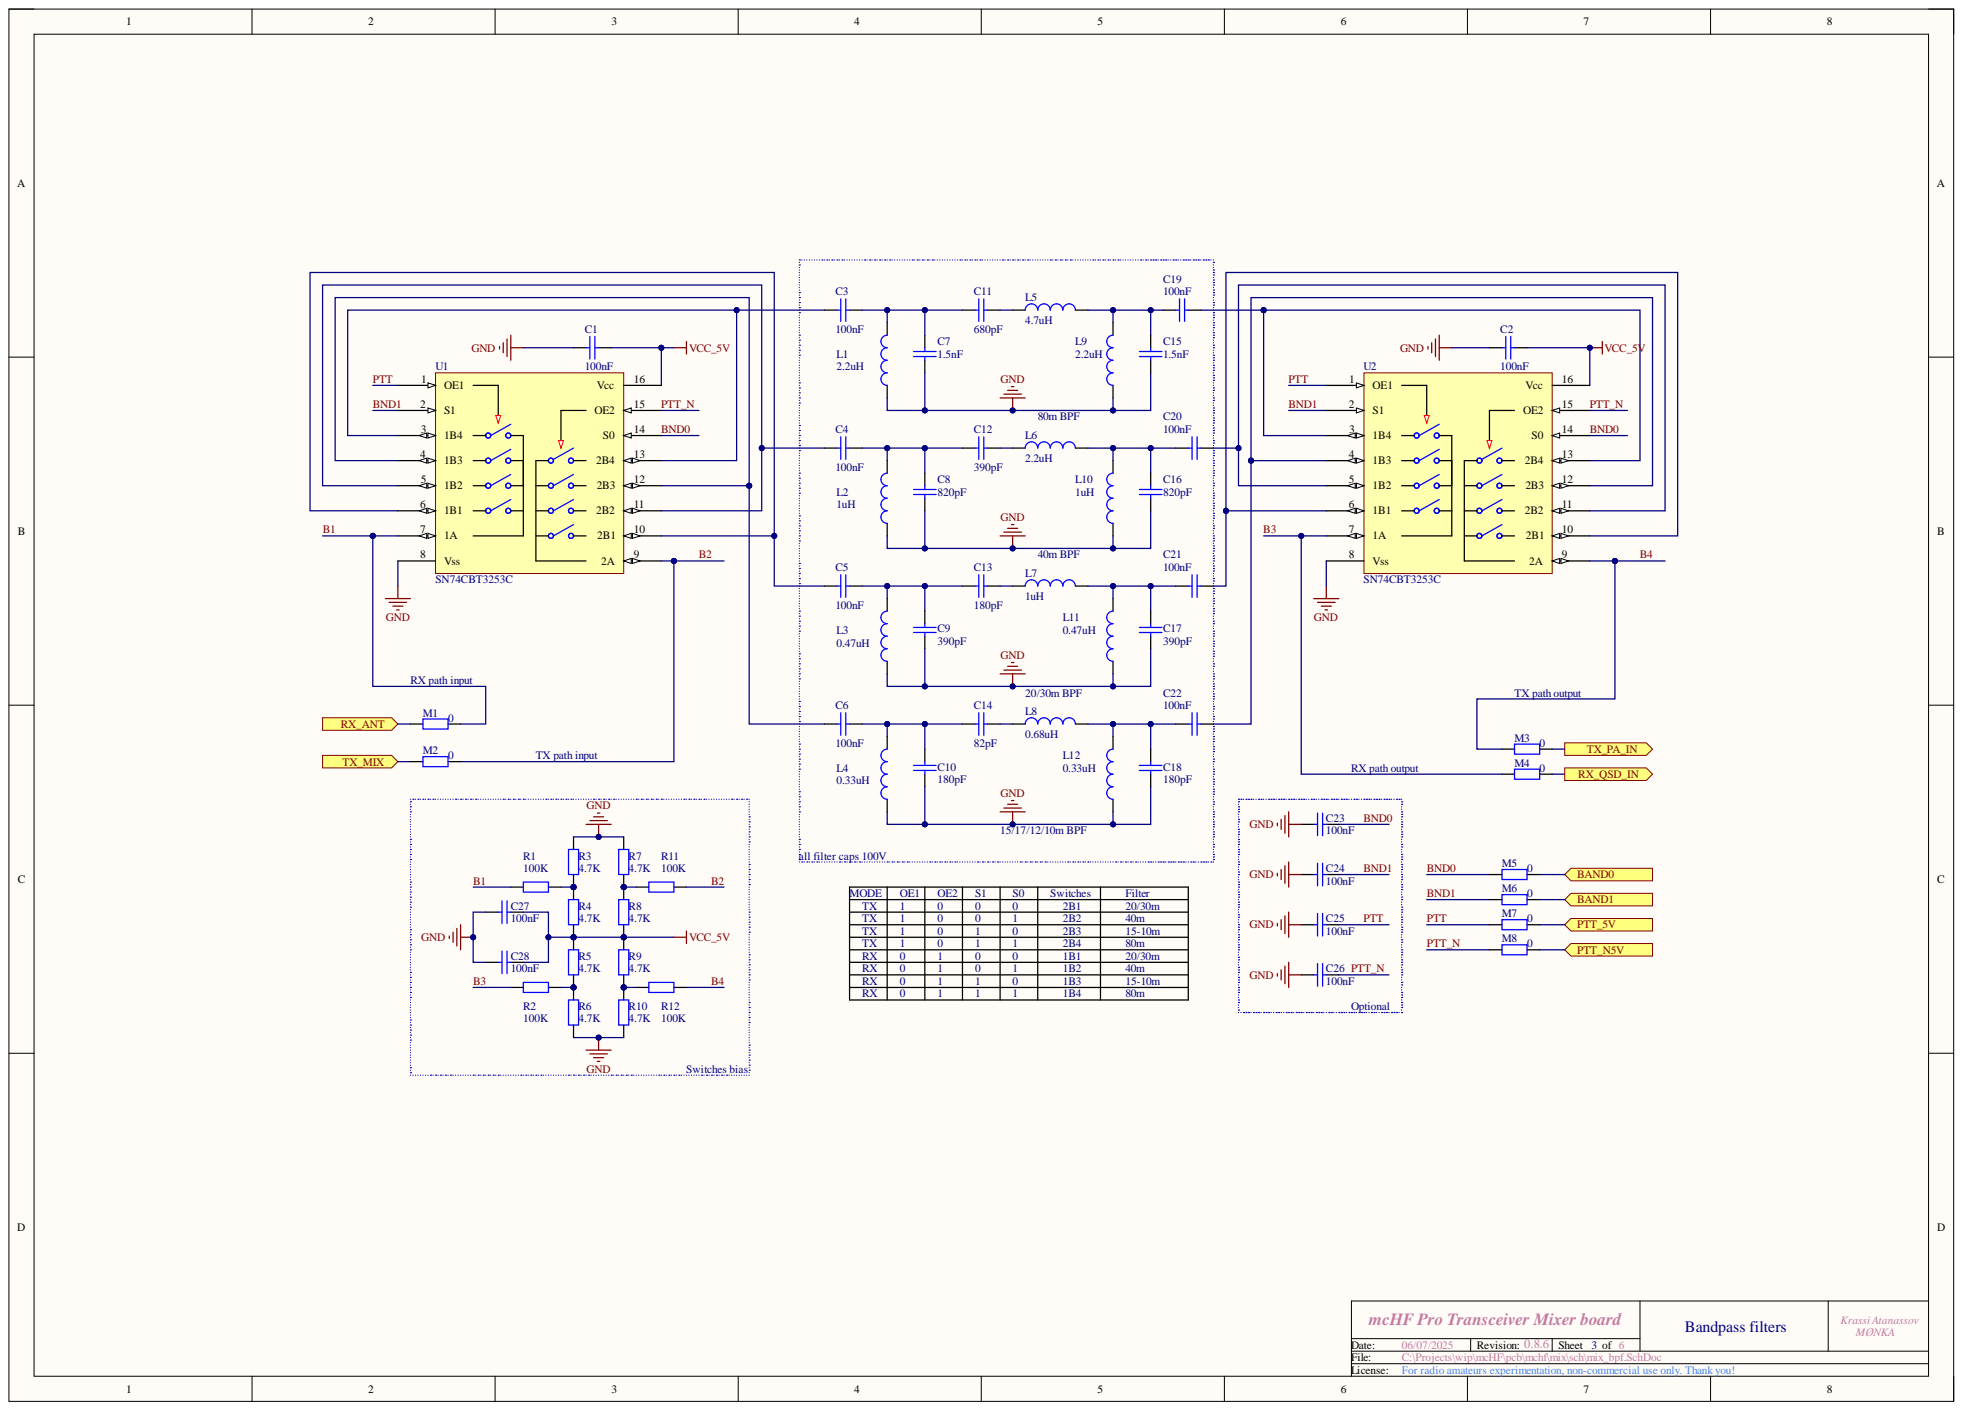
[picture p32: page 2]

M O D E | O E 1 | O E 2 | | | Sw i tches | Fi l ter
T X | 11110000 | 0 | 1 | 0 | 2B 3 | 15-10m

T XRX | | 0 | 1 | 1 | 2B 4 | 80m
R X | | | 0011 | 0101 | 1B 2 | 40m
R X | | 111 | | | 1B 3 | 15-10m

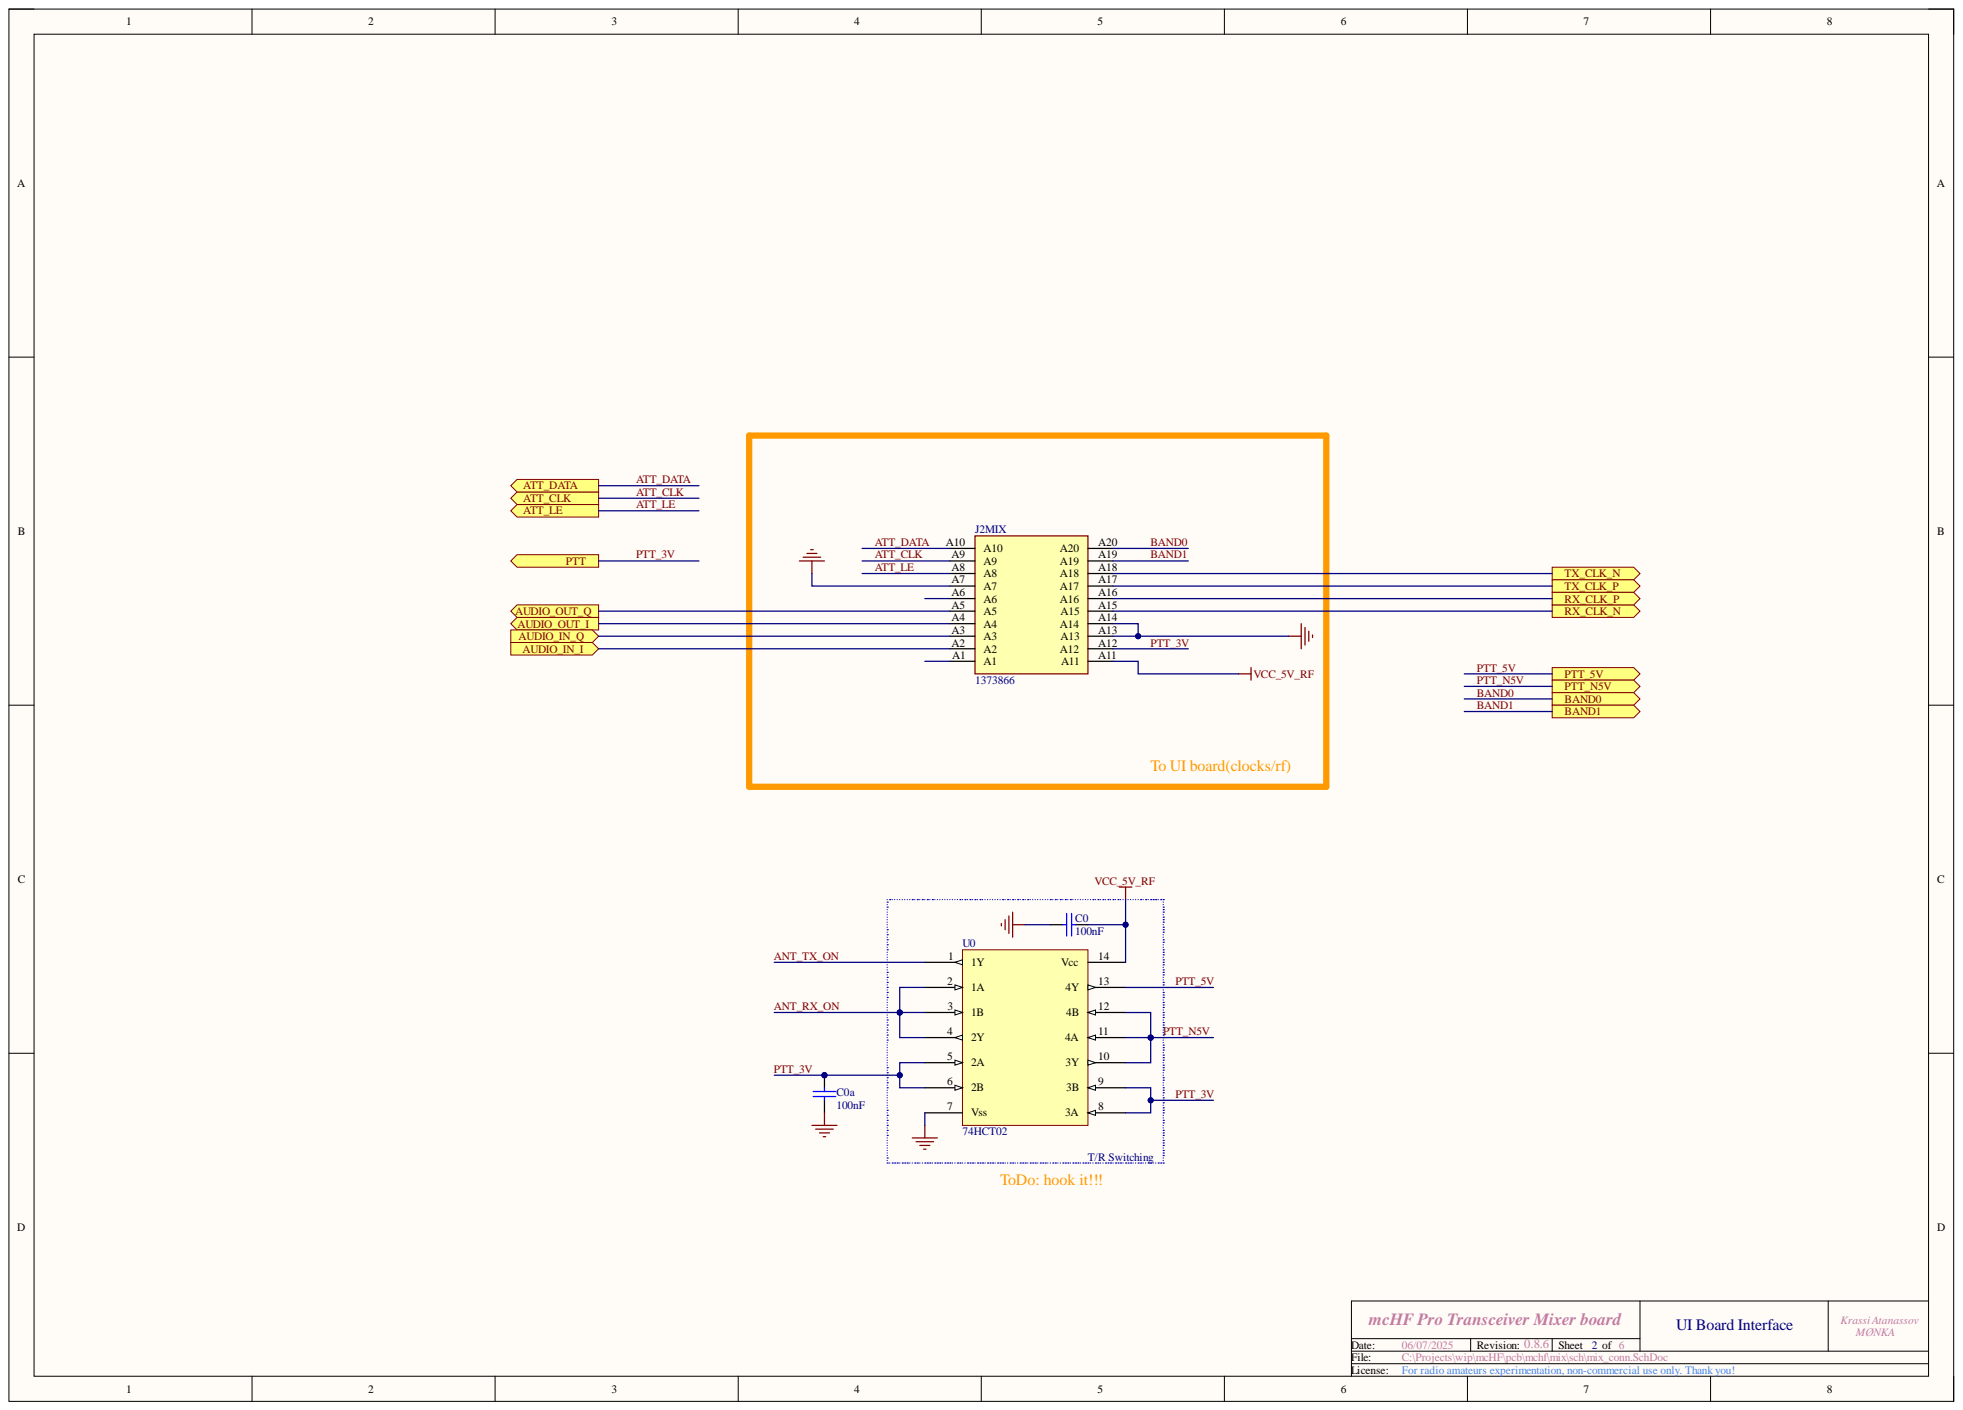
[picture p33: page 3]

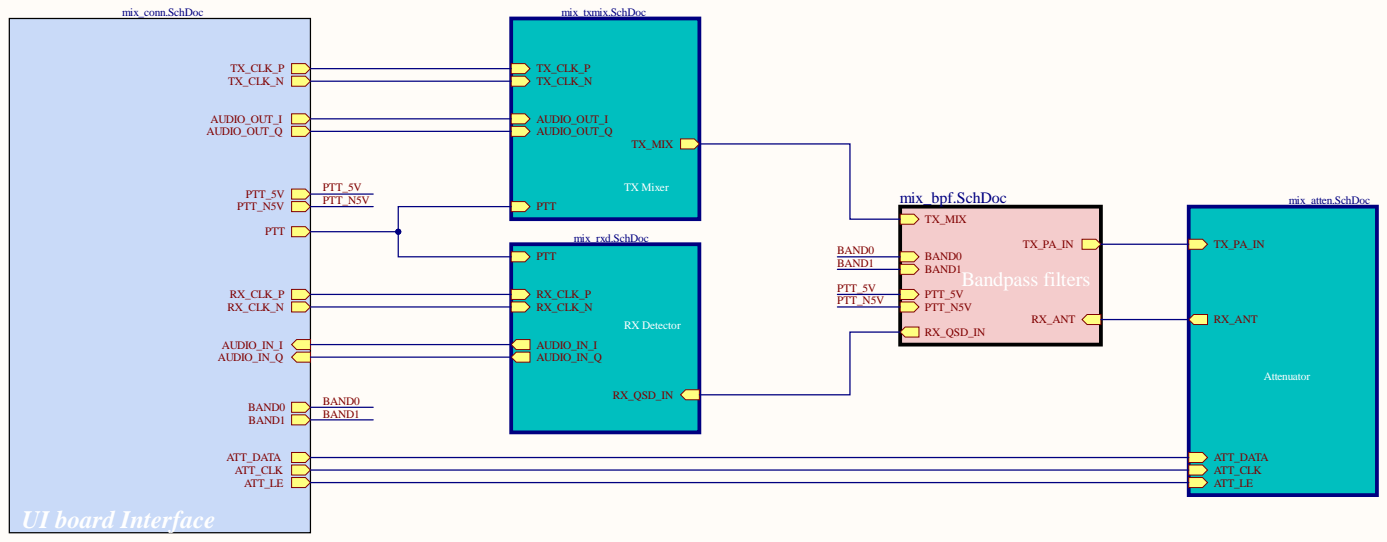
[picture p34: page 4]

C:\Projects\wip\mcHF\pcb\mchf\mix\sch\mix_main.SchDoc

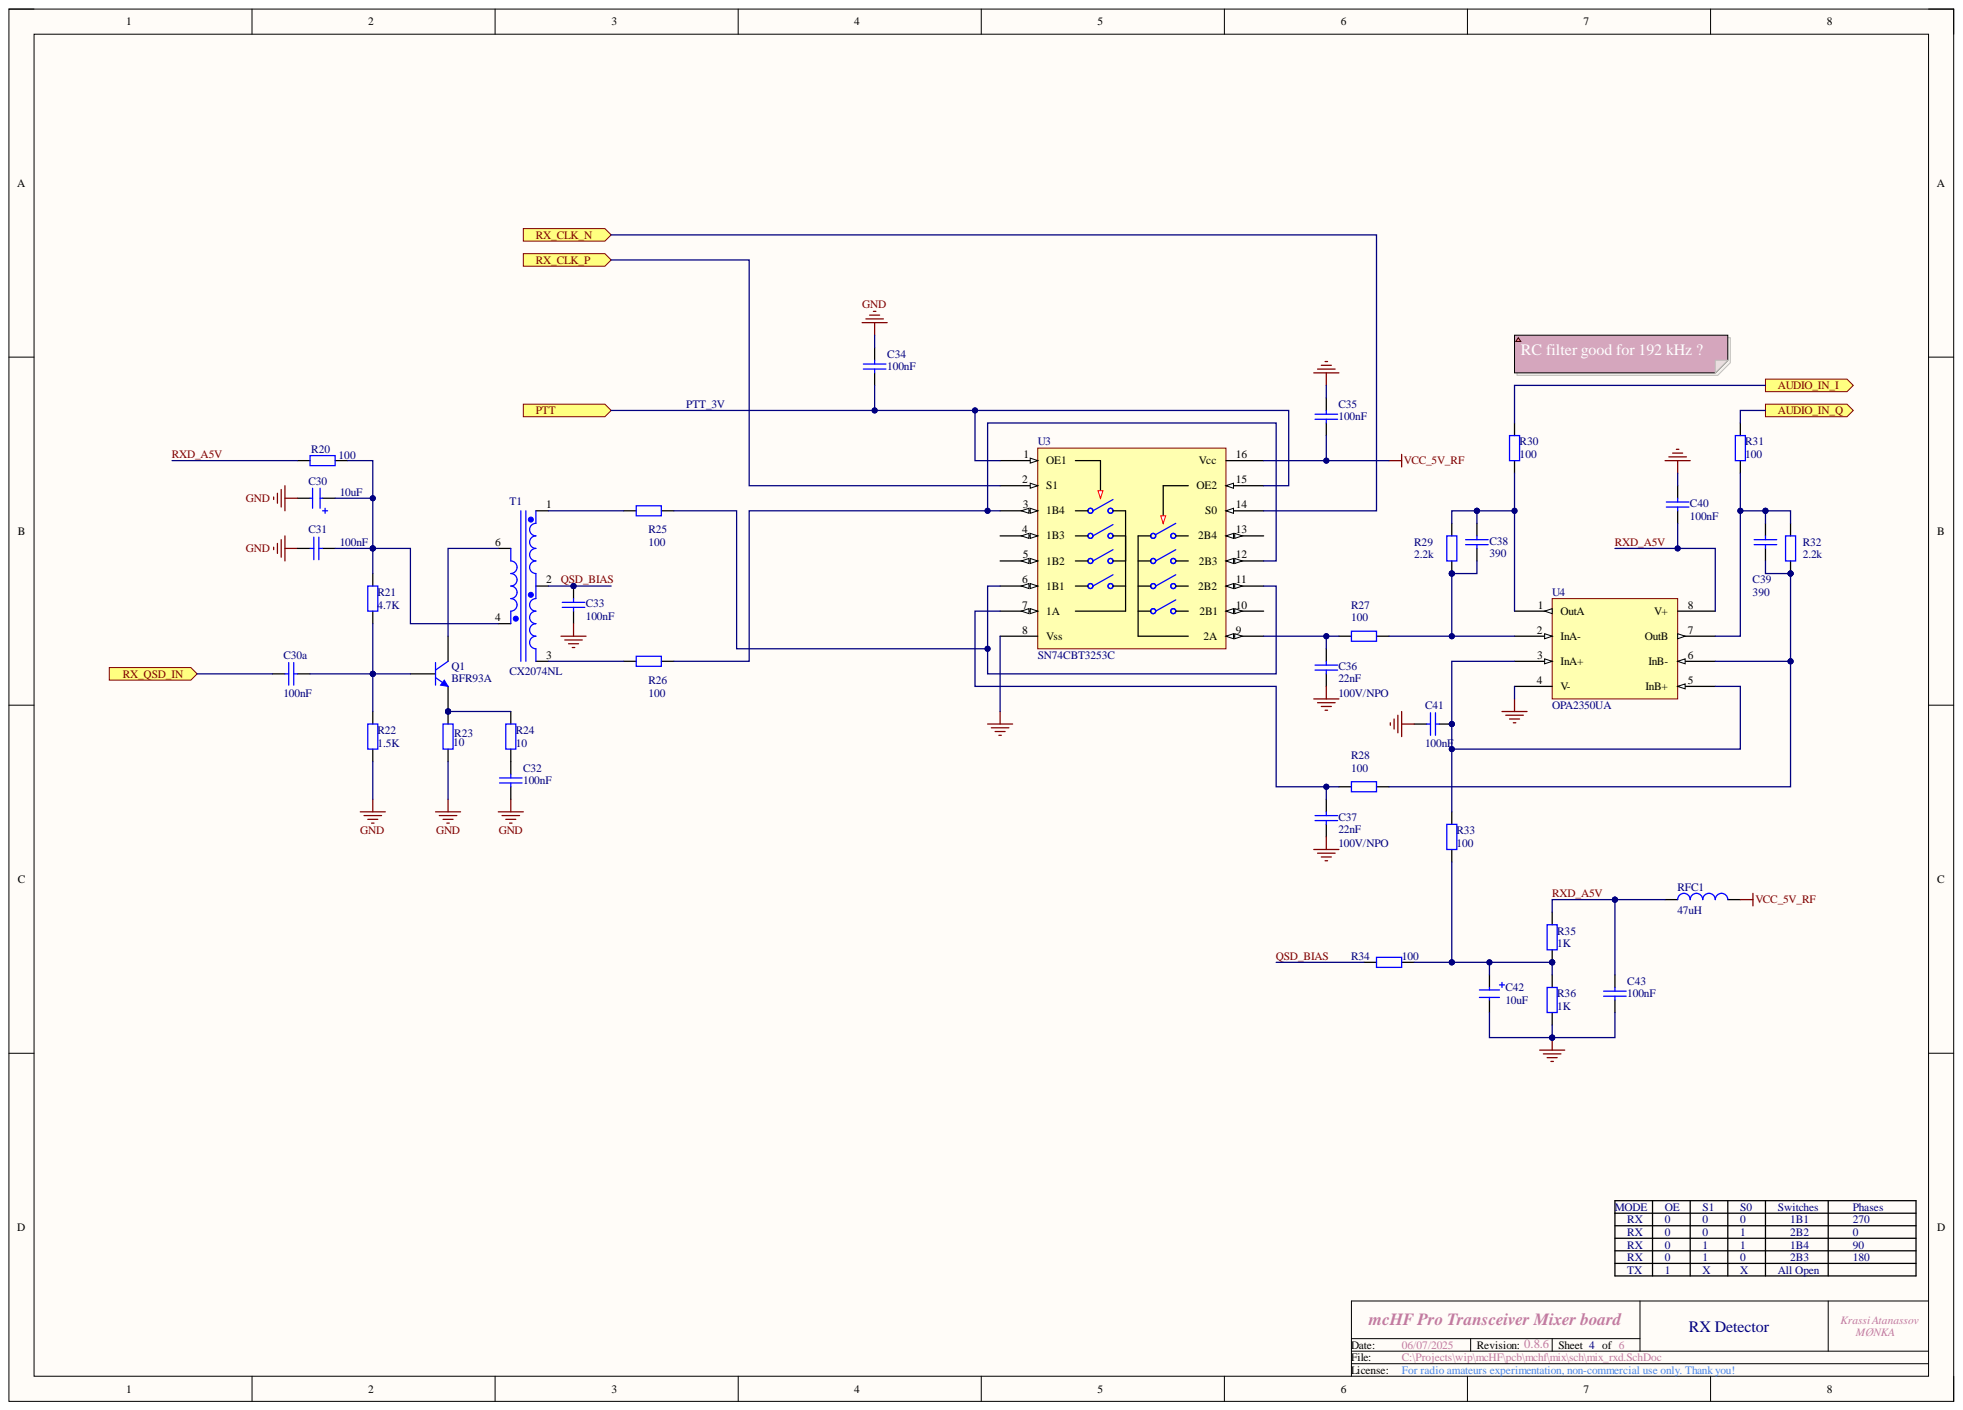
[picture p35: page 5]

M O D E | O E | | | Sw i tches | Phases

R X | | 1 | 0 | 2B 3 | 180
T X | 1 | X | X | A l l Open

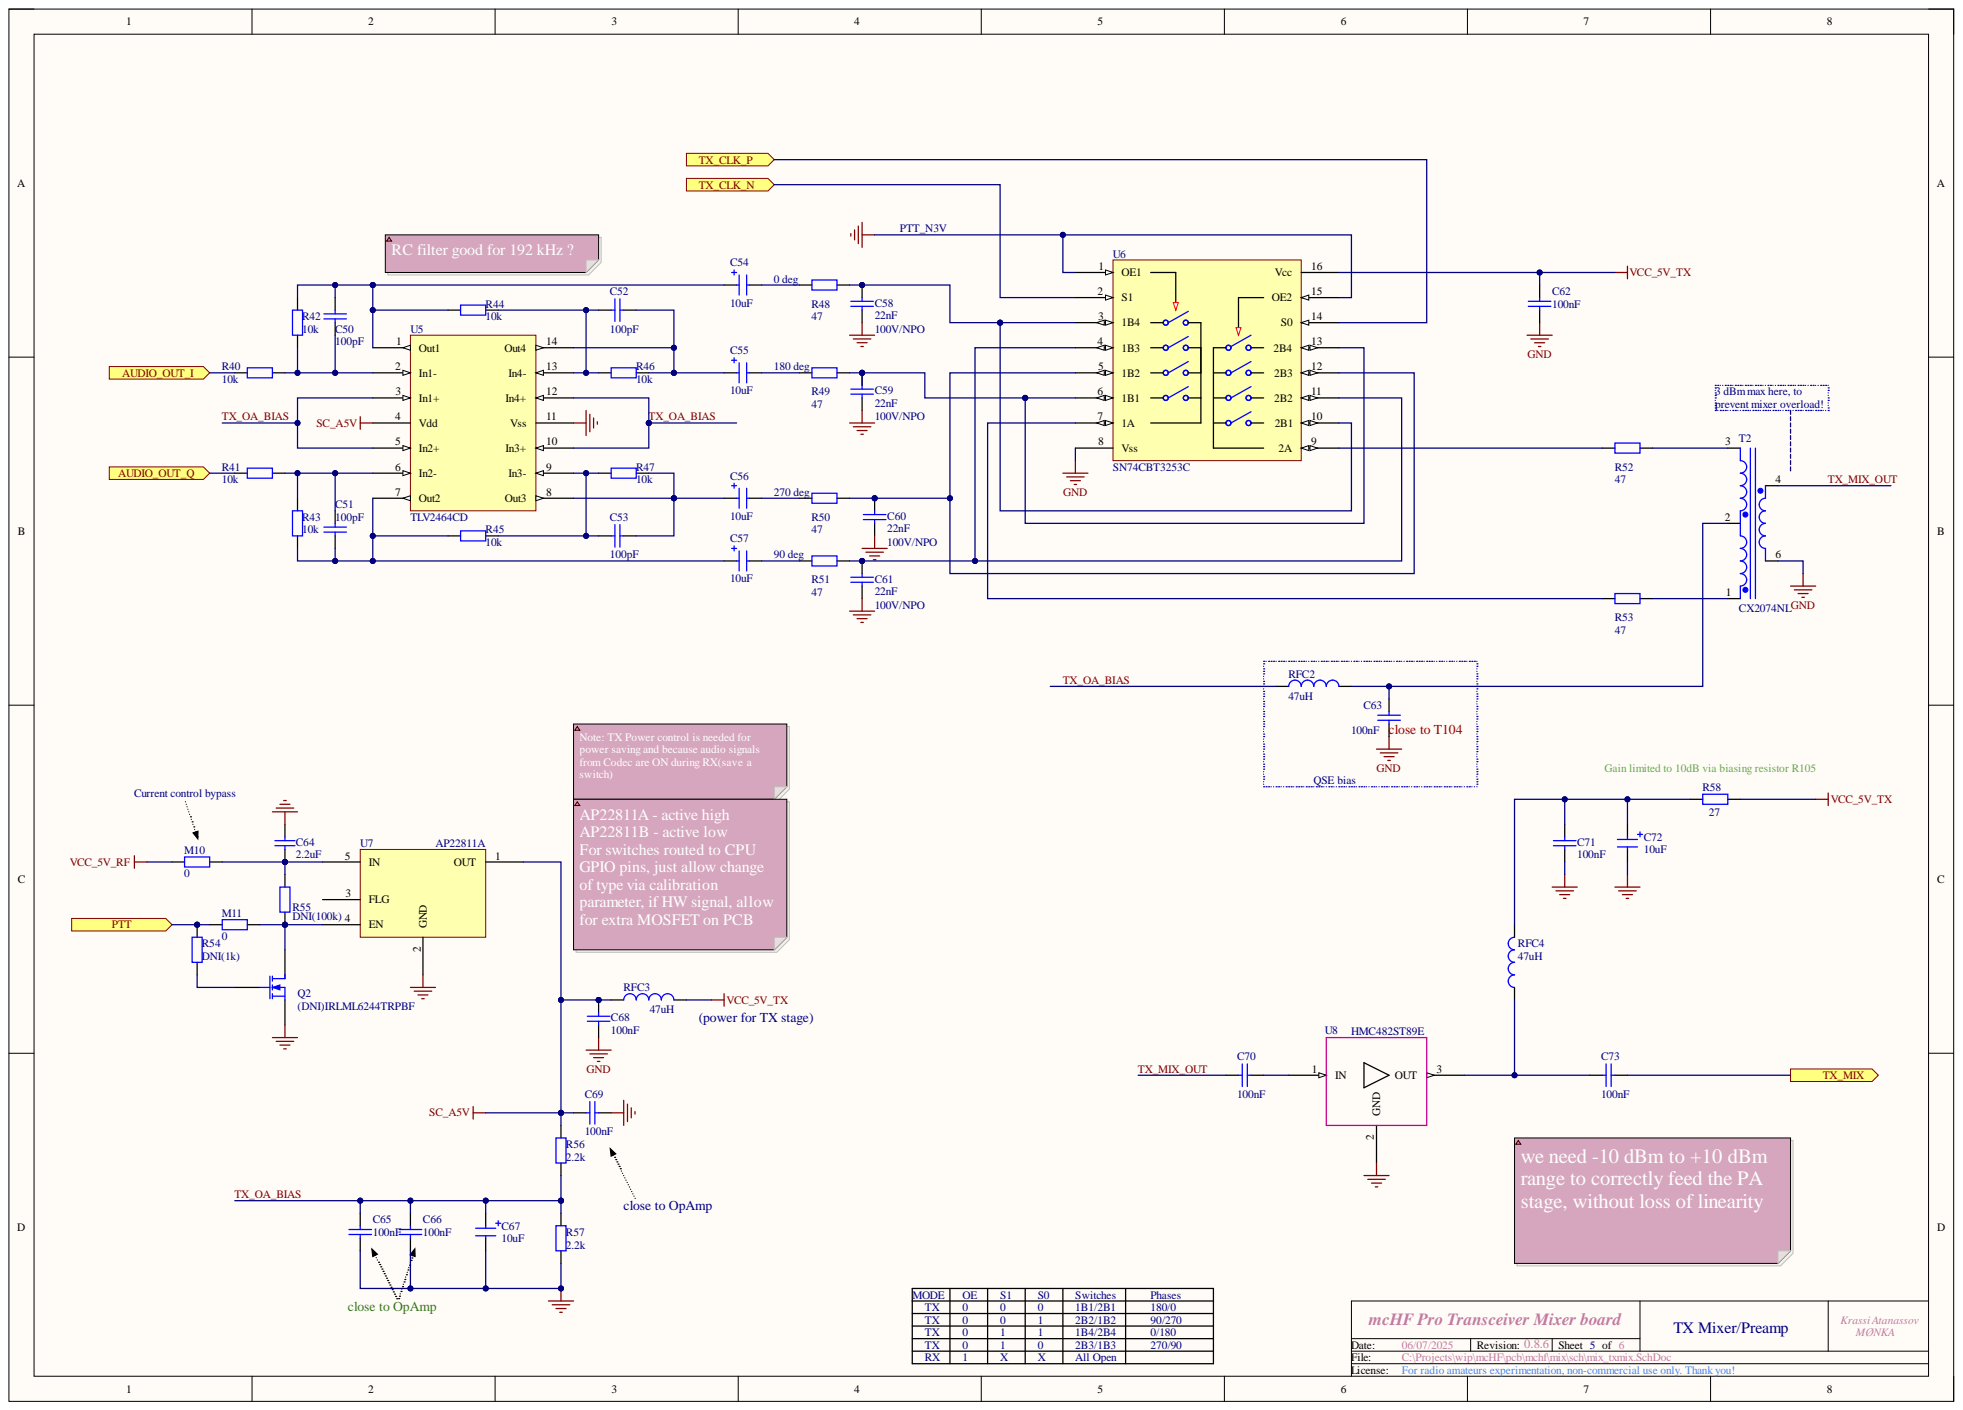
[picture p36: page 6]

RC filter good for 192 kHz ?

U6
OE1 1

3 dBm max here, to
prevent mixer overload!

Note: TX Power control is needed for
power saving and because audio signals
from Codec are ON during RX(save a
switch)

Gain limited to 10dB via biasing resistor R105

AP22811A - active high
AP22811B - active low
For switches routed to CPU
GPIO pins, just allow change
of type via calibration
parameter, if HW signal, allow
for extra MOSFET on PCB

FLG 3 EN 4

VCC_5V_TX
(power for TX stage)

we need -10 dBm to +10 dBm
range to correctly feed the PA
stage, without loss of linearity

MODE | OE | S1 | S0 | Switches | Phases
TX | | | | 1B1/2B1 | 180/0
TX | | | | 2B2/1B2 | 90/270
TX | 0 | 1 | 1 | 1B4/2B4 | 0/180
TX | | 1 | 0 | 2B3/1B3 | 270/90
RX | 1 | X | X | All Open

C:\Projects\wip\mcHF\pcb\mchf\mix\sch\mix_txmix.SchDoc

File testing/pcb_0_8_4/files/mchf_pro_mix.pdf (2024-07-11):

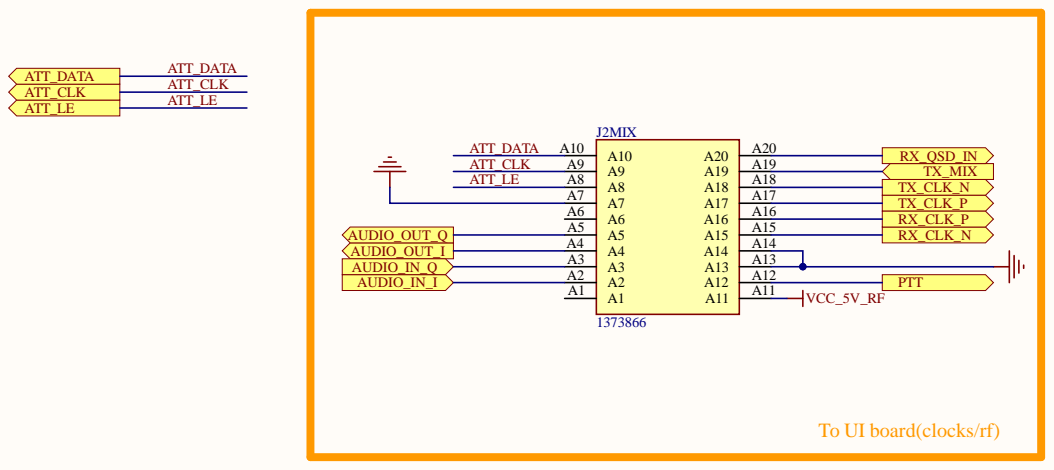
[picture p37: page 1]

To UI board(clocks/rf)

HF\pcb\mchf\mix\s
xperimentation, non-c

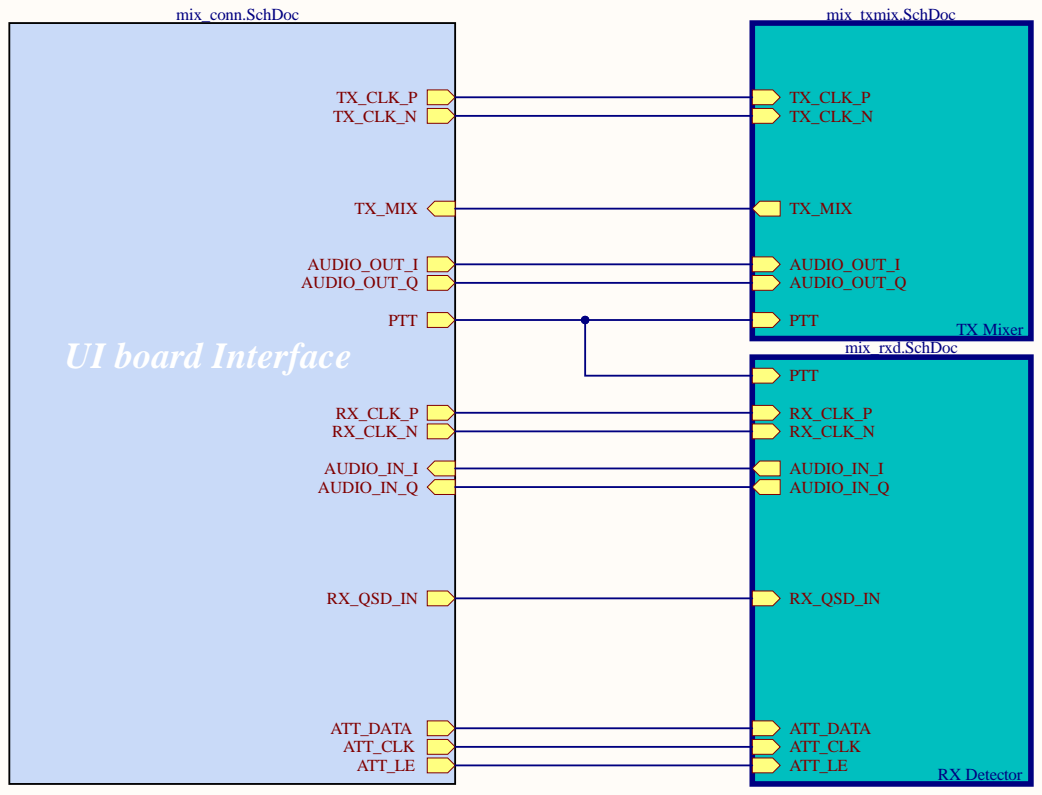
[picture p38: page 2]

mcHF Pro Transceiver UI board

C:\Projects\wip\mcHF\pcb\mchf\mix\sch\mix_main.SchDoc

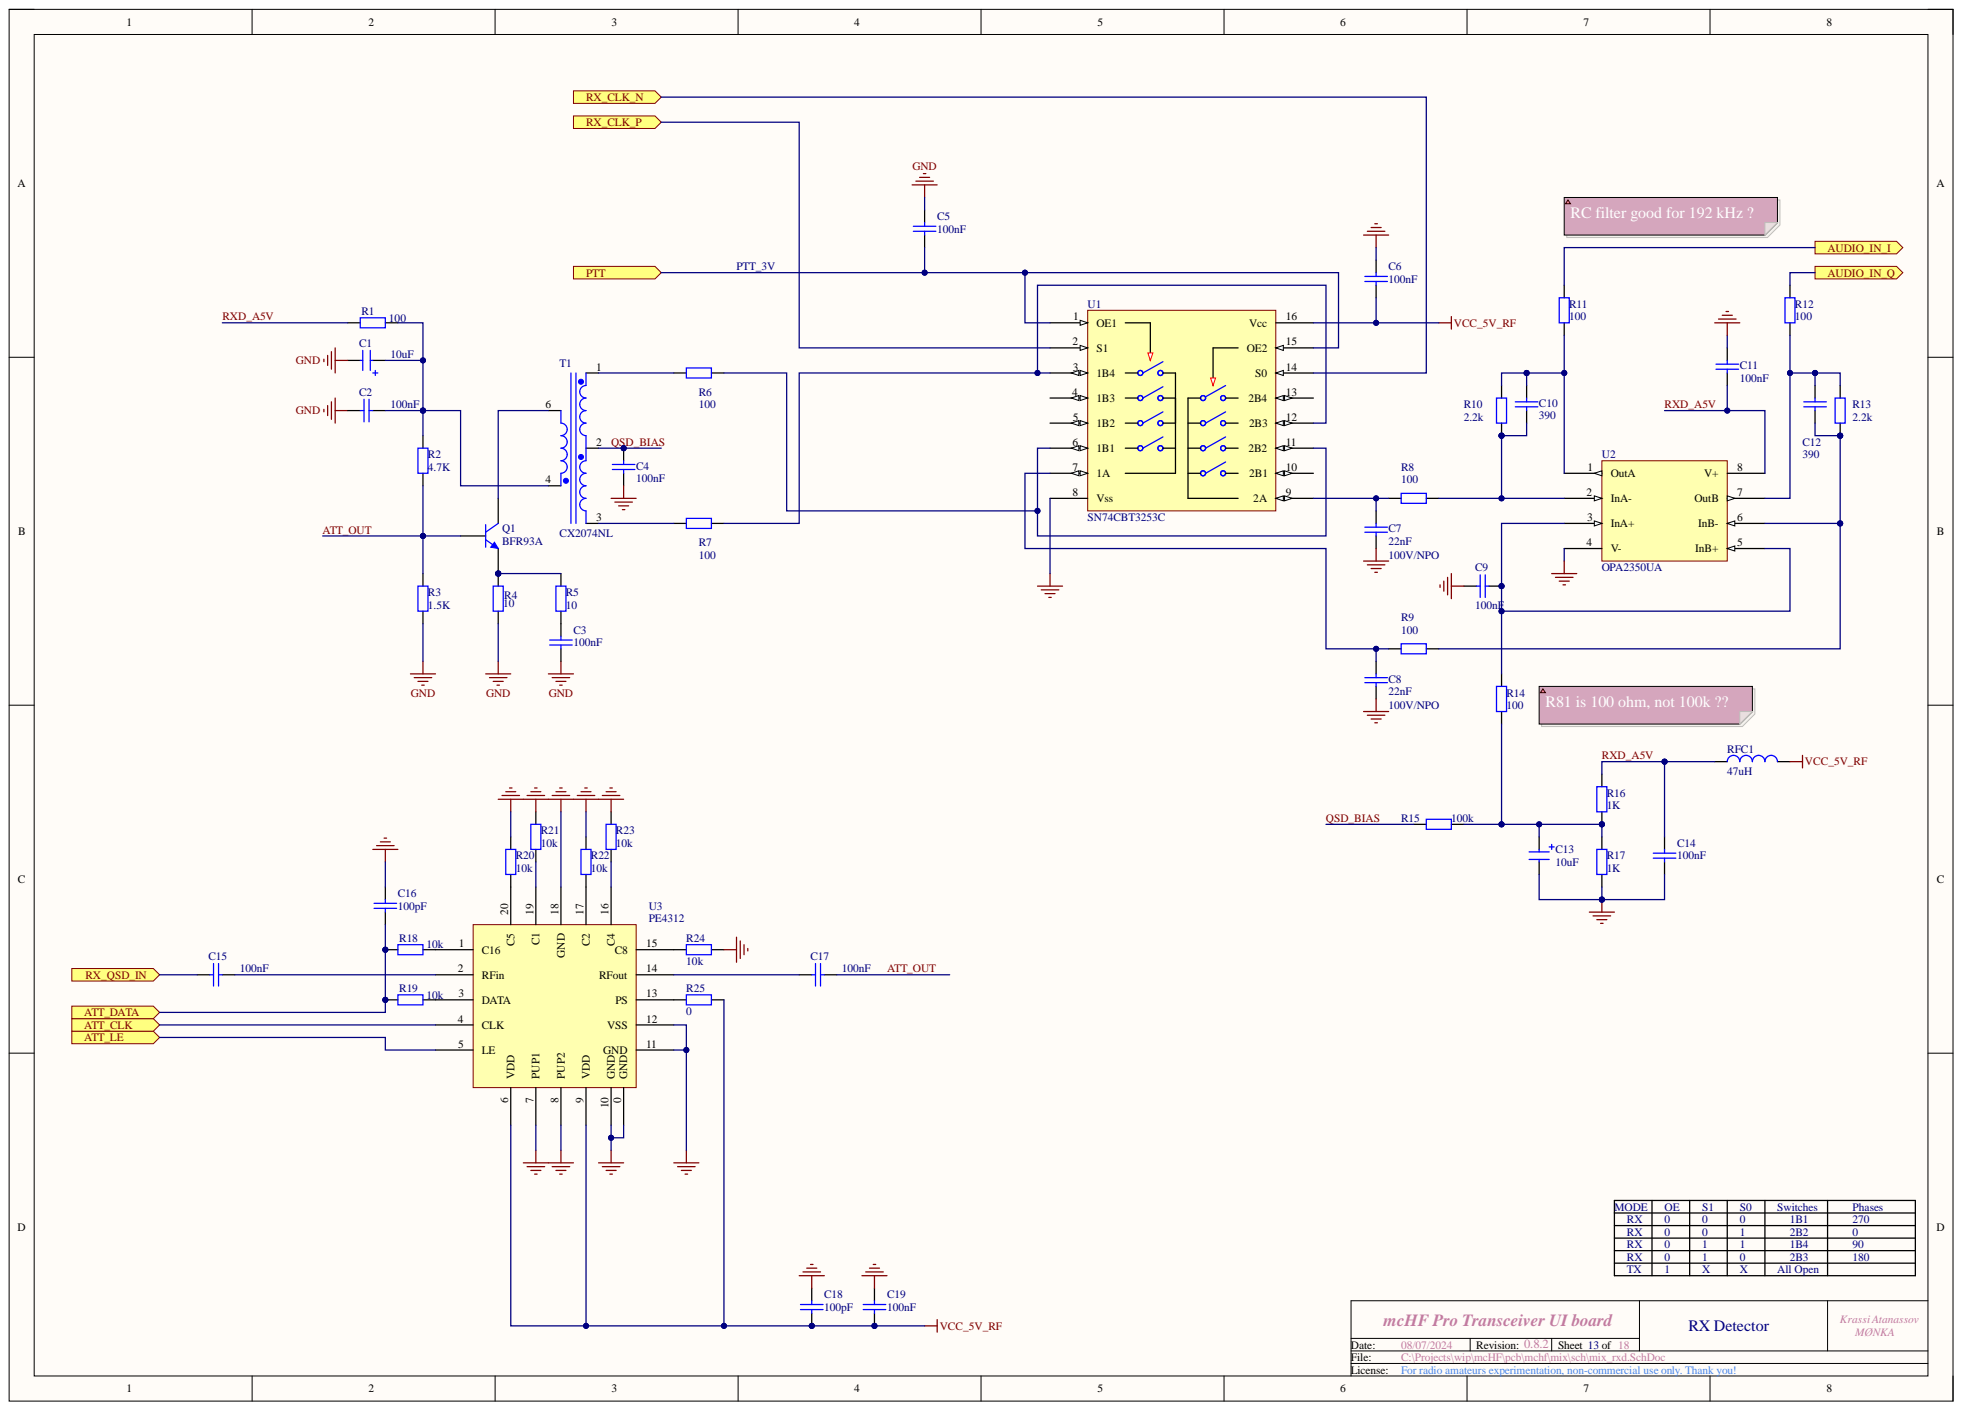
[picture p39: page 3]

RC filter good for 192 kHz ?

U1
OE1 1

OutA 1

MODE | OE | S1 | S0 | Switches | Phases
RX | 0 | 0 | 0 | 1B1 | 270
RX | 0 | 0 | 1 | 2B2 | 0
RX | 0 | 1 | 1 | 1B4 | 90
RX | 0 | 1 | 0 | 2B3 | 180
TX | 1 | X | X | All Open

C:\Projects\wip\mcHF\pcb\mchf\mix\sch\mix_rxd.SchDoc

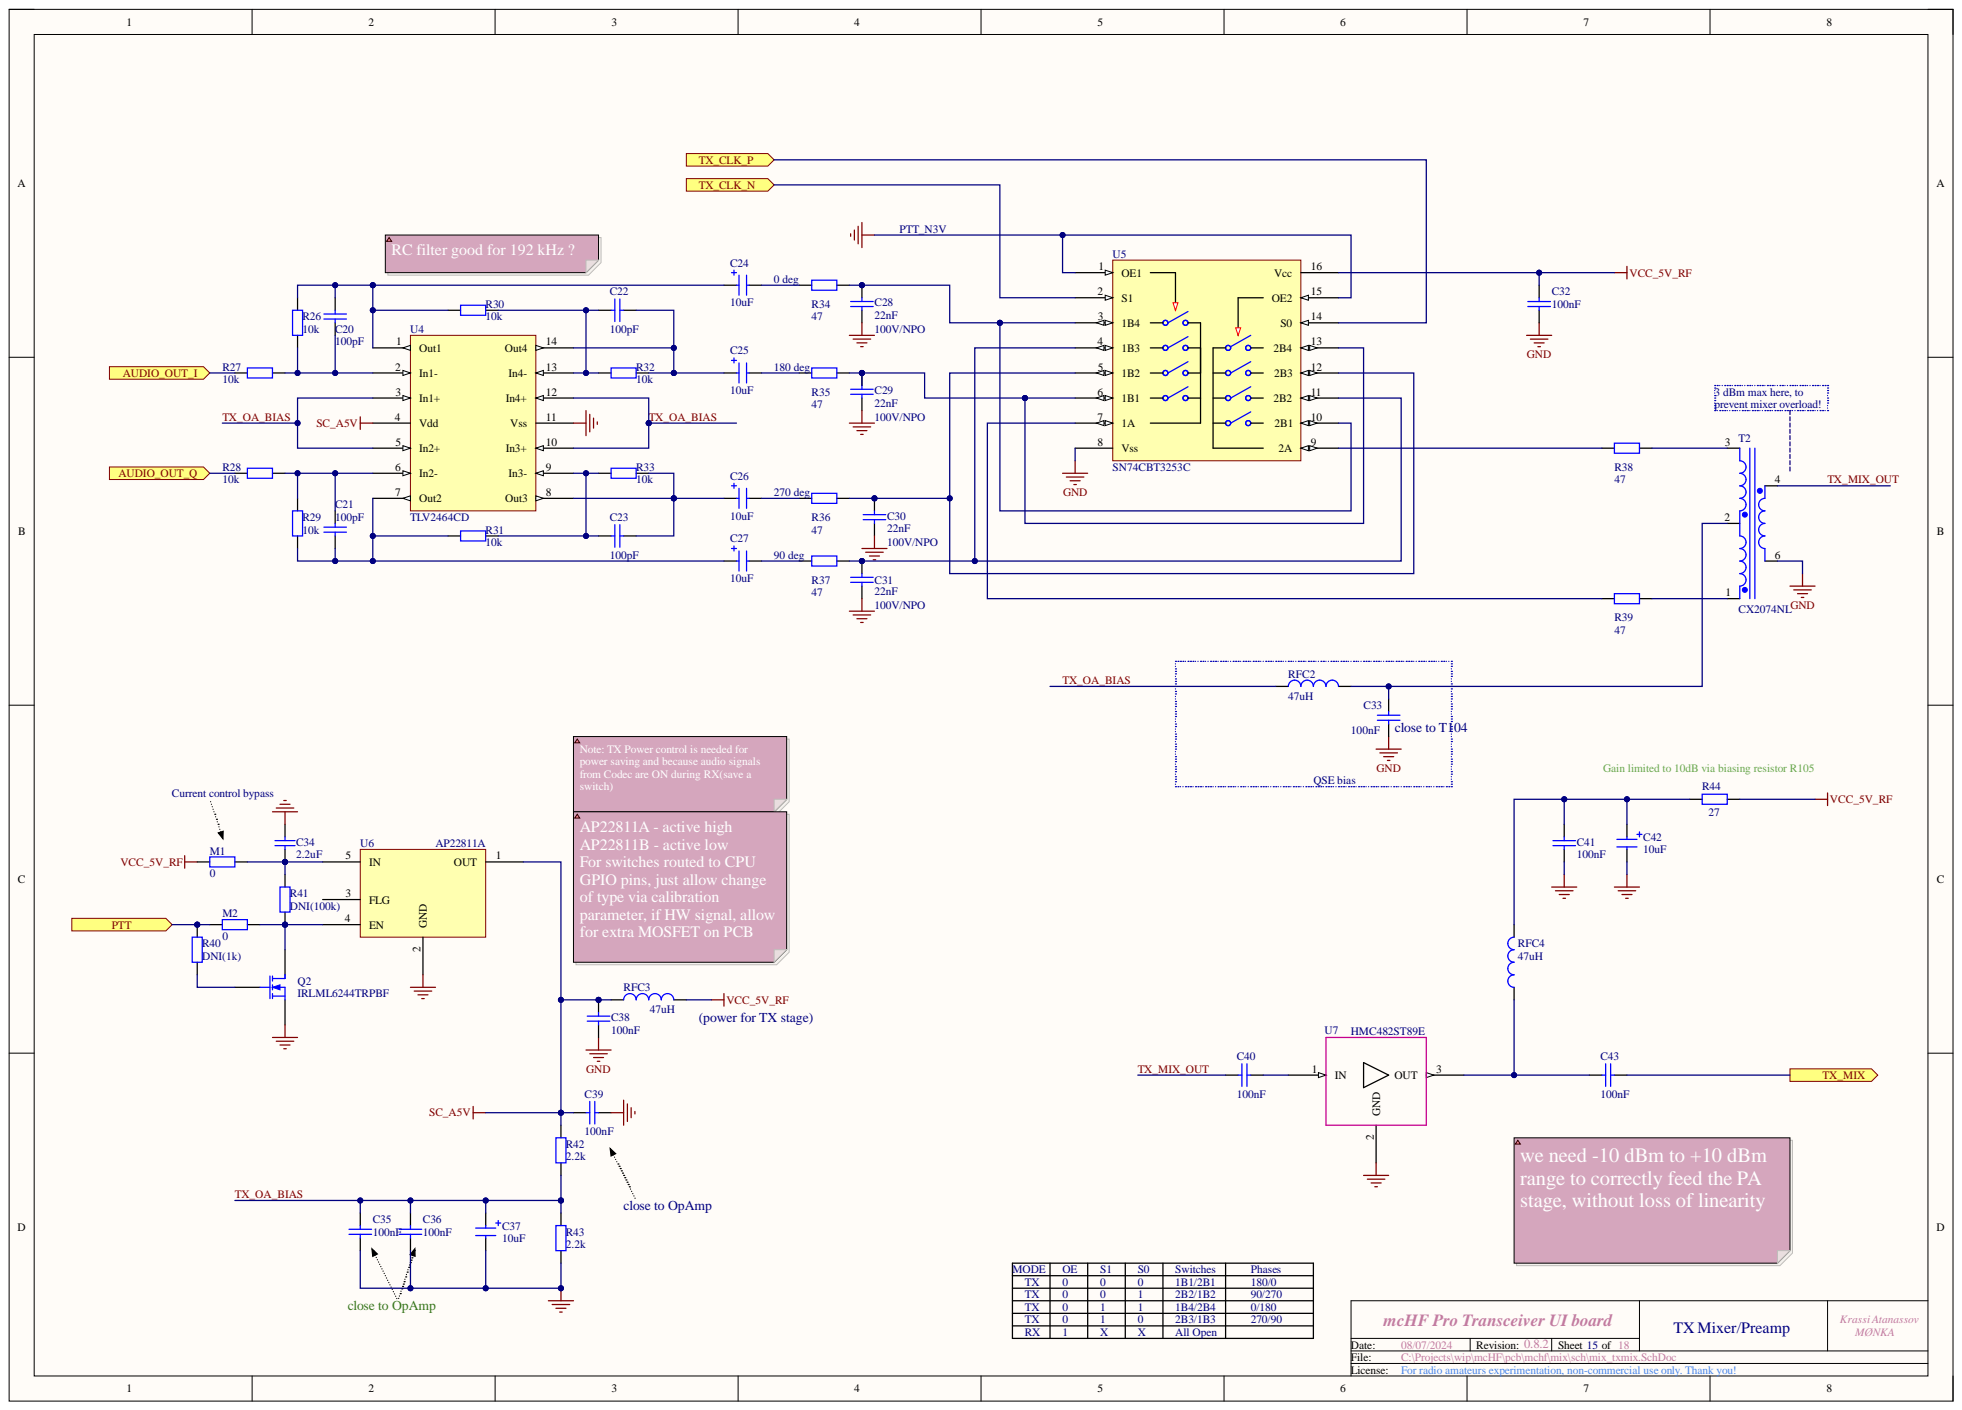
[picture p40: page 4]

RC filter good for 192 kHz ?

U5
OE1 1

3 dBm max here, to
prevent mixer overload!

Note: TX Power control is needed for
power saving and because audio signals
from Codec are ON during RX(save a
switch)

Gain limited to 10dB via biasing resistor R105

AP22811A - active high
AP22811B - active low
For switches routed to CPU
GPIO pins, just allow change
of type via calibration
parameter, if HW signal, allow
for extra MOSFET on PCB

FLG 3 EN 4

VCC_5V_RF
(power for TX stage)

we need -10 dBm to +10 dBm
range to correctly feed the PA
stage, without loss of linearity

MODE | OE | S1 | S0 | Switches | Phases
TX | 0 | 0 | 0 | 1B1/2B1 | 180/0
TX | | | | 2B2/1B2 | 90/270
TX | 0 | 1 | 1 | 1B4/2B4 | 0/180
TX | | 1 | 0 | 2B3/1B3 | 270/90
RX | 1 | X | X | All Open

C:\Projects\wip\mcHF\pcb\mchf\mix\sch\mix_txmix.SchDoc

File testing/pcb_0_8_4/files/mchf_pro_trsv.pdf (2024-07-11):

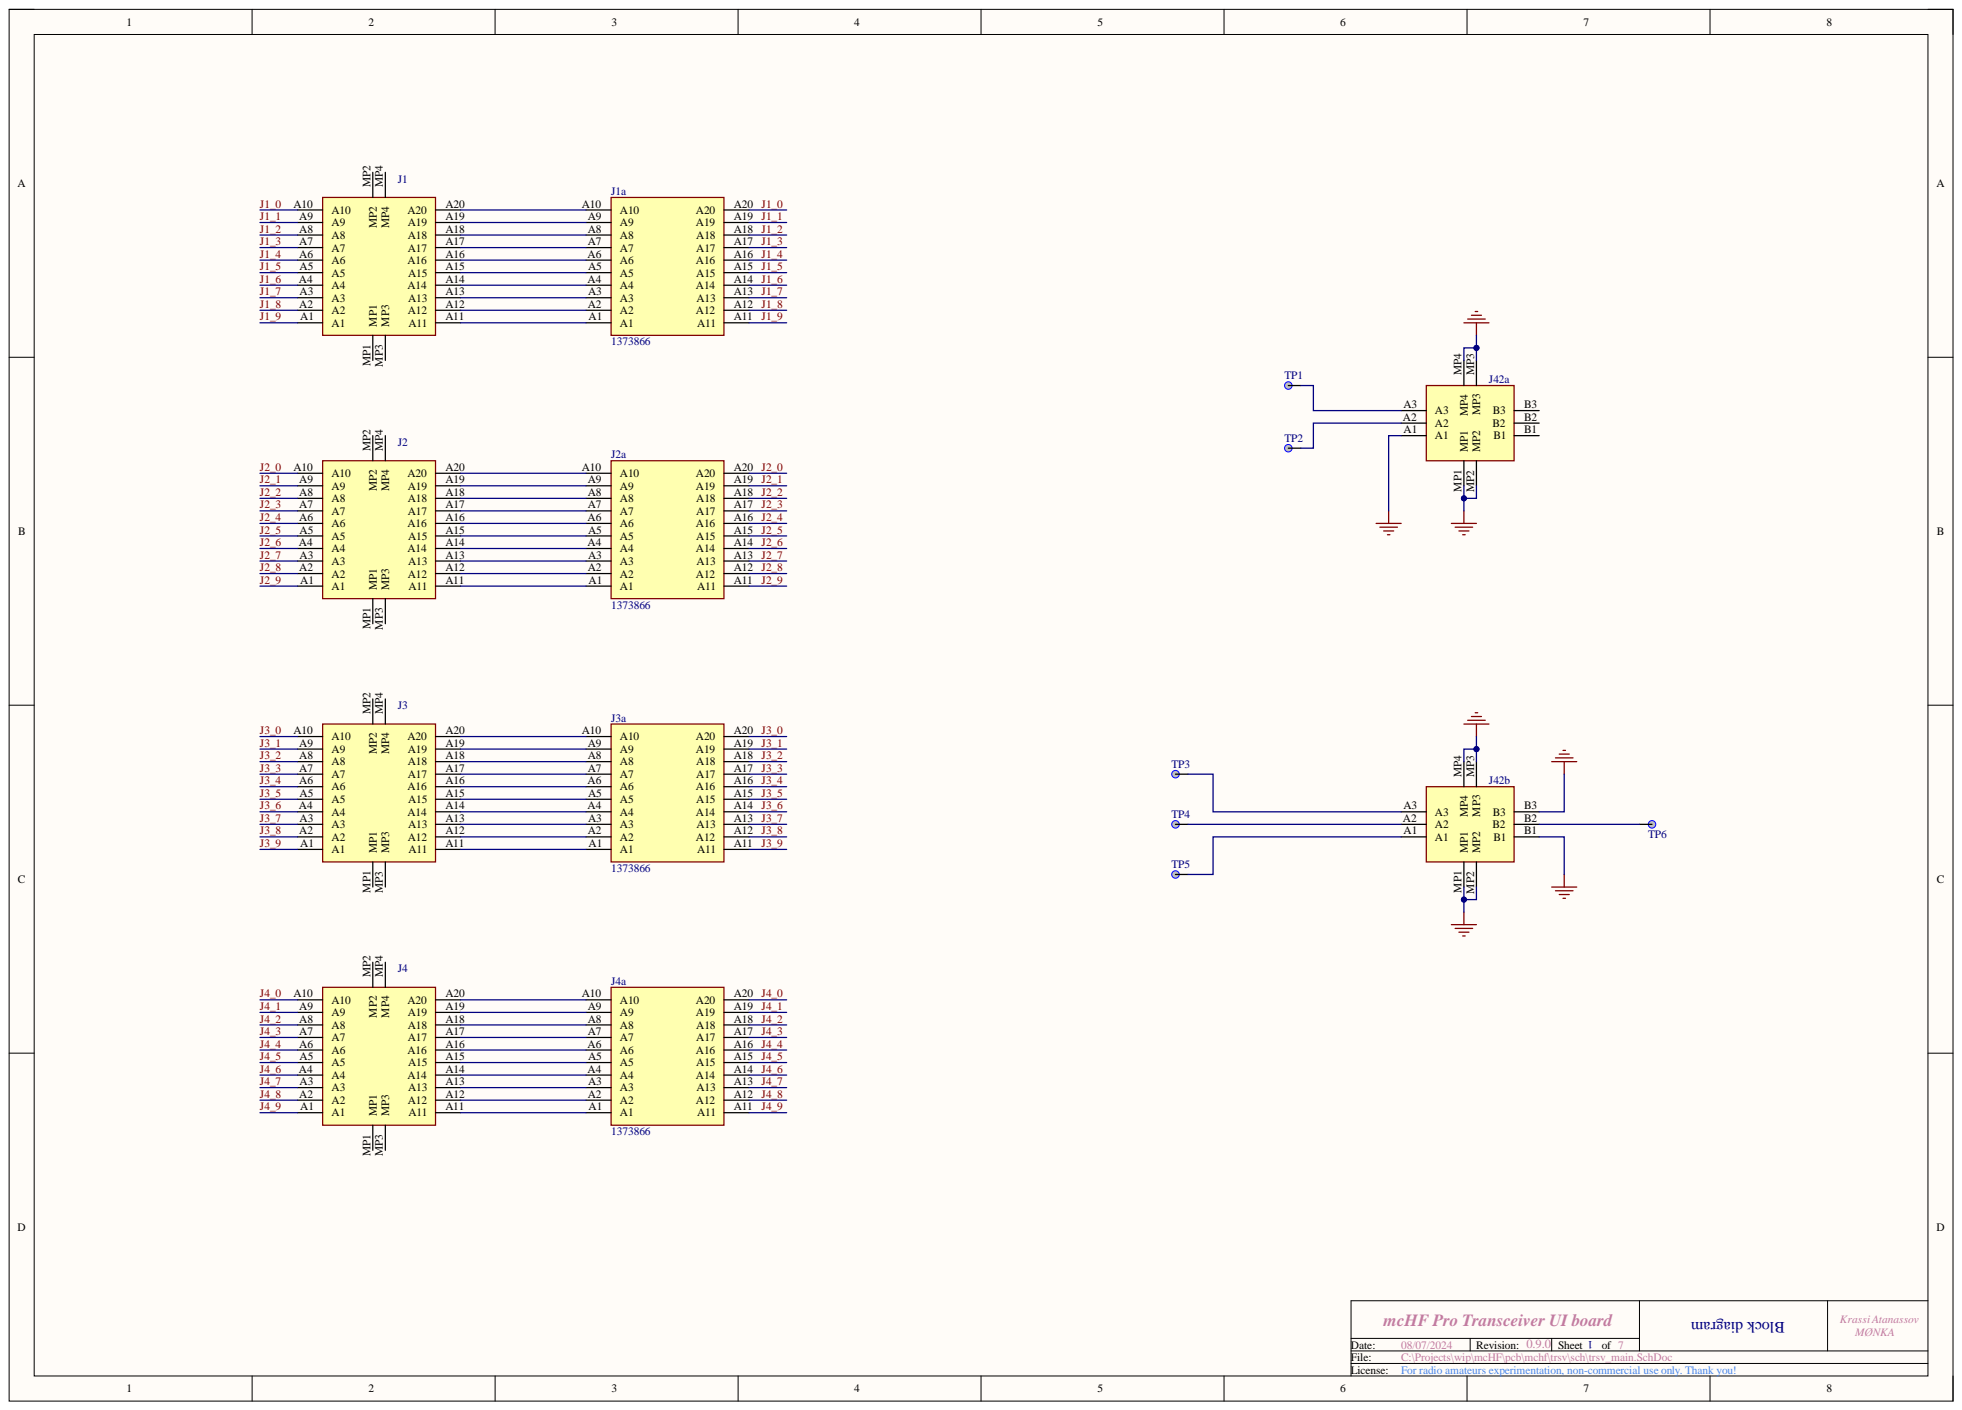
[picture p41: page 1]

HF\pcb\mchf\trs
xperimentation, non-c

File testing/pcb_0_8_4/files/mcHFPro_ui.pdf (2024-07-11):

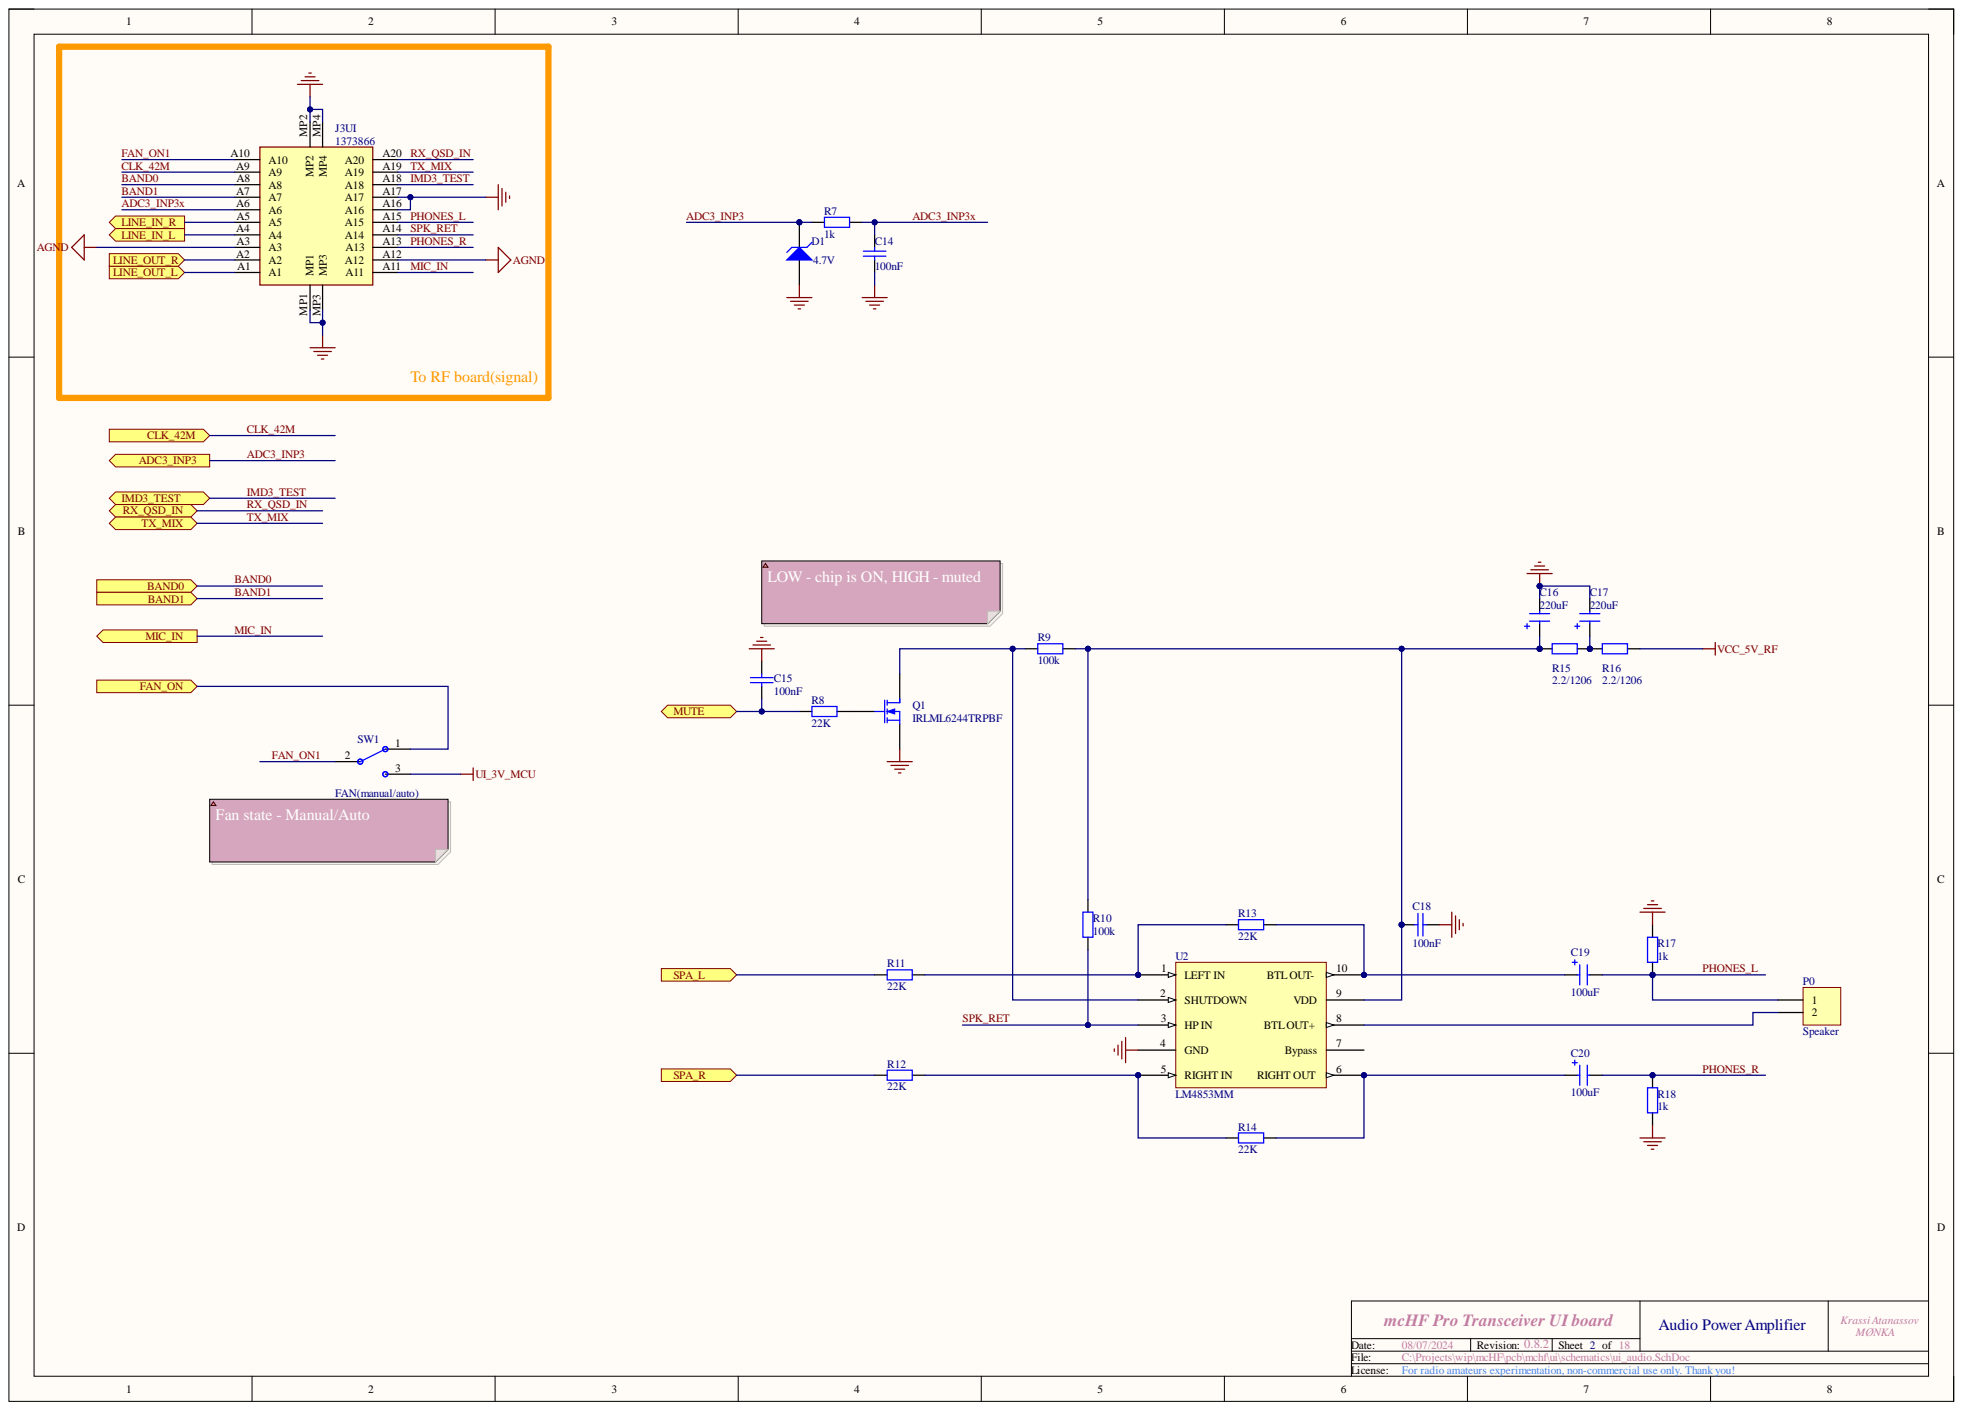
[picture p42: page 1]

To RF board(signal)

LOW - chip is ON, HIGH - muted

Fan state - Manual/Auto

LEFT IN 1

mcHF Pro Transceiver UI board

C:\Projects\wip\mcHF\pcb\mchf\ui\schematics\ui_audio.SchDoc


C:\Projects\wip\mcHF\pcb\mchf\ui\schematics\ui_bt_audio.SchDoc


ess 0x98 with pin 3/4 | | C C29



multiplexer allocated


To enter bootrom , use BOOT0
TP, no BOOT1 on this chip,
only fuses

1.15 to 1.3 V: optional supply voltage

for the DSI PHY (DSI regulator off)

DSI regulator supply output

VDDA 44

D6 | VBAT 8

Ceramic capacitor (Low ESR <600m ohm)

Only one 2.2uF required on board

Use Li battery instead of
constant draw from the pack ?

Decoupling (cap names reflect pins they need to be close to)

ToDo: Use bigger ratio to
reduce current draw

CPU power and clock 6

C:\Projects\wip\mcHF\pcb\mchf\ui\schematics\ui_cpu_power.SchDoc


AP22811A - active high
AP22811B - active low
For switches routed to CPU
GPIO pins, just allow change
of type via calibration
parameter, if HW signal, allow
for extra MOSFET on PCB

USB Host Keyboard Connection

Debug and SD card

C:\Projects\wip\mcHF\pcb\mchf\ui\schematics\ui_ext_conn.SchDoc


Front panel user controls 9

C:\Projects\wip\mcHF\pcb\mchf\ui\schematics\ui_front.SchDoc


GND 1 VDD 3

C51 100nF | NC 2 GND 8

C:\Projects\wip\mcHF\pcb\mchf\ui\schematics\ui_lcd.SchDoc


LO_SDA | | SDA 5

VDD 1

JC_CLK4

Q1 | Q1N | Q2 | Q2N

This part doesn't work
that well, check !!!

1. Do we need proper balanced mixer ?
2. Calculate ratios and caps!

ToDo: Connect to CPU!

To MIX board(clocks/rf)

C:\Projects\wip\mcHF\pcb\mchf\ui\schematics\ui_lo.SchDoc


IO pins, just allow chang


C:\Projects\wip\mcHF\pcb\mchf\ui\schematics\ui_main.SchDoc


Note: SDRAM runs on 100Mhz max clock, limited by FMC controller

Decoupling (cap names reflect pins they need to be close to)

C:\Projects\wip\mcHF\pcb\mchf\ui\schematics\ui_sdram.SchDoc

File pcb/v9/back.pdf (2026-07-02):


skip B
power CPU backup RAM(GPS)

xt to batt ne



Accessory - ext PA PTT control

Date:
File:
Licence: For radio amateurs experimentation, non-commercial use only. Thank you!

C:\Projects\wip\mcHF_v9\pcb\revB\back\schematics\back_conn.SchDoc

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

C:\Projects\wip\mcHF_v9\pcb\revB\back\schematics\back_lora.SchDoc


BACK_SDA

BMS_PRES

C:\Projects\wip\mcHF_v9\pcb\revB\back\schematics\back_main.SchDoc


available only when powered on

C:\Projects\wip\mcHF_v9\pcb\revB\back\schematics\back_preamp.SchDoc


R6 = ((Vout - 0.8)/0.8) * R7, where R7
is bottom divider resistor

Active Low for System Present

Switch Mode Power Supply

C:\Projects\wip\mcHF_v9\pcb\revB\back\schematics\back_smps.SchDoc


FT50-43 10:1 ratio
0.45mm wire
1T with coax, check mod docs

C:\Projects\wip\mcHF_v9\pcb\revB\back\schematics\back_swrmet.SchDoc


CFG1 9

GND_2 A12 MH4 MH5 MH6 | MH4
GND_3 B1 | MH5
VBUS_3 B4 | MH6

C:\Projects\wip\mcHF_v9\pcb\revB\back\schematics\back_usbc.SchDoc

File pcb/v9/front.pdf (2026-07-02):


Date:
File:
Licence: For radio amateurs experimentation, non-commercial use only. Thank you!

C:\Projects\wip\mcHF_v9\pcb\revB\front\schematics\front_audio.SchDoc



Speakers
Line In Line Out

RX Audio In TX Audio Out


PA BIAS Control(DACs

To RF board(control/power)

To RF board(si


multiplexer allocated


VDD33USB 141

1.15 to 1.3 V: optional supply voltage

for the DSI PHY (DSI regulator off)

DSI regulator supply output

VDDA 44

Ceramic capacitor (Low ESR <600m ohm)
Only one 2.2uF required on board

Decoupling (cap names reflect pins they need to be close to)

CPU power and clock 8

C:\Projects\wip\mcHF_v9\pcb\revB\front\schematics\front_cpu_power.SchDoc


Programmer Hold Power Line

USB Host Keyboard Connection

Debug and SD card

C:\Projects\wip\mcHF_v9\pcb\revB\front\schematics\front_ext_conn.SchDoc


GND 1 VDD 3

C51 100nF | NC 2 GND 8

C:\Projects\wip\mcHF_v9\pcb\revB\front\schematics\front_lcd.SchDoc


SDA 5

LO_SDA | VDD 1

JC_CLK4

Q1 | Q1N | Q2 | Q2N

To MIX board(clocks/rf)

C:\Projects\wip\mcHF_v9\pcb\revB\front\schematics\front_lo.SchDoc


front_cpu_power.SchDoc
CPU power and clocks

CLK_25Mhz BAND0 BAND1 Local Oscillator AUDIO_OUT_Q PTT AUDIO_OUT_I ATT_CLK ATT_LE

ATT_DATA | DIT_IRQ | DIT_IRQ DAH_IRQ Speaker Amp MUTE MIC_IN SPA_L SPA_R LINE_IN_L LINE_IN_R LINE_OUT_L LINE_OUT_R

C:\Projects\wip\mcHF_v9\pcb\revB\front\schematics\front_main.SchDoc


Note: SDRAM runs on 100Mhz max clock, limited by FMC controller

Decoupling (cap names reflect pins they need to be close to)

C:\Projects\wip\mcHF_v9\pcb\revB\front\schematics\front_sdram.SchDoc


Front panel user controls

C:\Projects\wip\mcHF_v9\pcb\revB\front\schematics\front_ui.SchDoc

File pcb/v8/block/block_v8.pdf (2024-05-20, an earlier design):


ESP32 Co-processor(WiFi/BT, Cloud FW update, storage)
ESP32

5" IPS LCD(MIPI DUAL LANE, Capacitive Multi Touch)
DISPLAY

mcHF QRP Transceiver | Block Diagram | Krassi A M0NKA

Date: 18/02/2024 Revision: 0.6.4 | Sheet 1 of 1

C:\Projects\wip\mcHF\sch\block\block_v8.SchDoc

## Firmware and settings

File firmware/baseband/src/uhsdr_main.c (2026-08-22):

/*  -*-  mode: c; tab-width: 4; indent-tabs-mode: t; c-basic-offset: 4; coding: utf-8  -*-  */
/************************************************************************************
 **                                                                                 **
 **                                        UHSDR                                    **
 **               a powerful firmware for STM32 based SDR transceivers              **
 **                                                                                 **
 **---------------------------------------------------------------------------------**
 **                                                                                 **
 **  File name:                                                                     **
 **  Description:                                                                   **
 **  Last Modified:                                                                 **
 **  Licence:		GNU GPLv3                                                      **
 ************************************************************************************/

#ifndef H7_M4_CORE

// Common
#include "uhsdr_board.h"
#include <stdio.h>
#include "uhsdr_rtc.h"
#include "ui_spectrum.h"

#include "ui_configuration.h"
#include "config_storage.h"

// serial EEPROM driver
#include "uhsdr_hw_i2c.h"
#include "uhsdr_hw_i2s.h"
#include "uhsdr_hmc1023.h"

// Audio Driver
#include "drivers/audio/audio_driver.h"
#include "drivers/audio/audio_management.h"
#include "drivers/audio/cw/cw_gen.h"
#include "drivers/audio/freedv_uhsdr.h"
#include "drivers/audio/audio_nr.h"

//cat
#include "drivers/cat/cat_driver.h"

// UI Driver
#include "drivers/ui/ui_driver.h"
#include "drivers/ui/lcd/ui_lcd_hy28.h"
#include "drivers/ui/menu/ui_menu.h"
#include "drivers/ui/oscillator/osc_interface.h"
#include "drivers/ui/oscillator/osc_si5351a.h"
#include "drivers/ui/oscillator/osc_si570.h"
#include "drivers/audio/codec/codec.h"
#include "misc/profiling.h"
#include "uhsdr_canary.h"
#include "audio_agc.h"
// Keyboard Driver
// #include "keyb_driver.h"

// Misc
#include "drivers/audio/softdds/softdds.h"

#include "uhsdr_flash.h" // only for EEPROM_START_ADDRESS
#include "drivers/ui/radio_management.h"
//

#include "misc/TestCPlusPlusInterface.h"

void HAL_GPIO_EXTI_Callback (uint16_t GPIO_Pin)
{
    if (ts.paddles_active != false)
    {
        switch(GPIO_Pin)
        {
        case BUTTON_PWR:
            break;
        case PADDLE_DAH:
            // Call handler
            if (Board_PttDahLinePressed() && RadioManagement_IsTxDisabledBy(TX_DISABLE_RXMODE) == false)
            {  // was PTT line low? Is it not a RX only mode
                RadioManagement_Request_TxOn();     // yes - ONLY then do we activate PTT!  (e.g. prevent hardware bug from keying PTT!)
                if(ts.dmod_mode == DEMOD_CW || is_demod_rtty() || is_demod_psk() || ts.cw_text_entry)
                {
                    CwGen_DahIRQ();     // Yes - go to CW state machine
                }
            }
            break;
        case PADDLE_DIT:
            if((ts.dmod_mode == DEMOD_CW || is_demod_rtty() || is_demod_psk() || ts.cw_text_entry) && Board_DitLinePressed())
            {
                if (ts.cw_keyer_mode != CW_KEYER_MODE_STRAIGHT)
                {
                    RadioManagement_Request_TxOn();
                }
                CwGen_DitIRQ();
            }
            break;
        }
    }
}

/**
 * Detects if a special bootloader is used and configures some settings
 * Used for debugging and testing purposes only
 */
void Main_DetectSpecialBootloader()
{
    // detection routine for special bootloader version strings which do enable debug or development functions
    char out[14];
    for(uint8_t* begin = (uint8_t*)0x8000000; begin < (uint8_t*)EEPROM_START_ADDRESS-8; begin++)
    {
        if (memcmp("Version: ",begin,9) == 0)
        {
            snprintf(out,13, "%s", &begin[9]);
            for (uint8_t i=1; i<13; i++)
            {
                if (out[i] == '\0')
                {
                    if (out[i-1] == 'a')
                    {
                        ts.special_functions_enabled = 1;
                    }
                    if (out[i-1] == 's')
                    {
                        ts.special_functions_enabled = 2;
                    }
                    break;
                }
            }
            break;
        }
    }
}

/**
 * All data inside the ts data structure which needs a non-zero value set at startup AND
 * is either used before the configuration has been loaded OR which is not loaded from the persistent configuration
 * should be initialized here.
 * Values which are initialized by other init functions before use should not be initialized here.
 * We try to initialize a single variable only once, to avoid confusion.
 *
 */
void TransceiverStateInit(void)
{
    // Defaults always
    ts.txrx_mode 		= TRX_MODE_RX;				// start in RX
    ts.samp_rate		= IQ_SAMPLE_RATE;			// set sampling rate

    //CONFIG LOADED: ts.band		  		= BAND_MODE_20;			// band from eeprom
    ts.rx_temp_mute		= false;					// used in muting audio during band change
    ts.filter_band		= FILTER_BAND_UNKNOWN;	// used to indicate the bpf filter selection for power detector coefficient selection
    ts.dmod_mode 		= DEMOD_USB;				// demodulator mode
    //CONFIG LOADED: ts.rx_gain[RX_AUDIO_SPKR].value = AUDIO_GAIN_DEFAULT;
    ts.rx_gain[RX_AUDIO_DIG].value		= DIG_GAIN_DEFAULT;

    //CONFIG LOADED:ts.rx_gain[RX_AUDIO_SPKR].max	= MAX_VOLUME_DEFAULT;		// Set max volume default
    ts.rx_gain[RX_AUDIO_DIG].max   =  DIG_GAIN_MAX;			// Set max volume default

    ts.rx_gain[RX_AUDIO_SPKR].active_value = 1;			// this variable is used in the active RX audio processing function
    ts.rx_gain[RX_AUDIO_DIG].active_value = 1;			// this variable is used in the active RX audio processing function
    //CONFIG LOADED:ts.lineout_gain     = LINEOUT_GAIN_DEFAULT;
    //CONFIG LOADED:ts.rf_codec_gain	= DEFAULT_RF_CODEC_GAIN_VAL;		// Set default RF gain (0 = lowest, 8 = highest, 9 = "Auto")
    ts.rit_value		= 0;					// RIT value

    //CONFIG LOADED:ts.cw_sidetone_gain			= DEFAULT_SIDETONE_GAIN;	// Sidetone gain

    //CONFIG LOADED:ts.cw_keyer_mode		= CW_KEYER_MODE_IAM_B;			// CW keyer mode
    //CONFIG LOADED:ts.cw_keyer_speed		= CW_KEYER_SPEED_DEFAULT;			// CW keyer speed
    //CONFIG LOADED:ts.cw_sidetone_freq	= CW_SIDETONE_FREQ_DEFAULT;		// CW sidetone and TX offset frequency
    //CONFIG LOADED:ts.cw_paddle_reverse	= 0;					// Paddle defaults to NOT reversed
    //CONFIG LOADED:ts.cw_rx_delay		= CW_TX2RX_DELAY_DEFAULT;			// Delay of TX->RX turnaround
    //CONFIG LOADED:ts.cw_keyer_weight        = CW_KEYER_WEIGHT_DEFAULT;

    ts.audio_spkr_unmute_delay_count		= VOICE_TX2RX_DELAY_DEFAULT;			// TX->RX delay turnaround

    ts.tune_freq		= 0;

    ts.menu_mode		= 0;					// menu mode
    ts.menu_item		= 0;					// menu item selection
    ts.menu_var			= 0;					// menu item change variable
    ts.menu_var_changed	        = 0;				// TRUE if a menu variable was changed and that an EEPROM save should be done

    //NO INIT NEEDED? SET BEFORE USE? ts.tx_mic_boost             = MIC_BOOST_DEFAULT;		// no extra gain. electret element assumed

    //CONFIG LOADED:ts.tx_audio_source	= TX_AUDIO_MIC;				// default source is microphone
    //NO INIT NEEDED, SET BEFORE USE: ts.tx_mic_gain_mult	= MIC_GAIN_DEFAULT;			// actual operating value for microphone gain

    //CONFIG LOADED:ts.tx_gain[TX_AUDIO_MIC]		= MIC_GAIN_DEFAULT;	// default line gain
    //CONFIG LOADED:ts.tx_gain[TX_AUDIO_LINEIN_L]	= LINE_GAIN_DEFAULT;	// default line gain
    ts.tx_gain[TX_AUDIO_LINEIN_R]	= LINE_GAIN_DEFAULT;	// default line gain
    ts.tx_gain[TX_AUDIO_DIG]		= LINE_GAIN_DEFAULT;	// default line gain
    ts.tx_gain[TX_AUDIO_DIGIQ]		= LINE_GAIN_DEFAULT;	// default line gain

    ts.tune				= false;				// reset tuning flag

    //NO INIT NEEDED, SET BEFORE USE:ts.tx_power_factor	= 0.50;					// TX power factor

    //CONFIG LOADED:ts.pa_bias			= PA_BIAS_DEFAULT;		// Use lowest possible voltage as default
    //CONFIG LOADED:ts.pa_cw_bias		= PA_BIAS_DEFAULT;			// Use lowest possible voltage as default (nonzero sets separate bias for CW mode)
    //CONFIG LOADED:ts.freq_cal			= 0;				// Initial setting for frequency calibration
    //CONFIG LOADED:ts.power_level		= PA_LEVEL_DEFAULT;			// See uhsdr_board.h for setting

    ts.powering_down	= 0;						// TRUE if powering down

    //CONFIG LOADED:ts.xverter_mode		= 0;					// TRUE if transverter mode is active (e.g. offset of display)
    //CONFIG LOADED:ts.xverter_offset	= 0;					// Frequency offset in transverter mode (added to frequency display)

    // This is NOT reset by the LCD function, but must be enabled/disabled externally

    //CONFIG LOADED:ts.demod_mode_disable			= 0;		// TRUE if a specific mode is to be disabled

    //CONFIG LOADED:ts.tx_meter_mode	= METER_SWR;

    //CONFIG LOADED:ts.alc_decay		= ALC_DECAY_DEFAULT;			// ALC Decay (release) default value
    //NO INIT NEEDED, SET BEFORE USE:ts.alc_decay_var	= ALC_DECAY_DEFAULT;			// ALC Decay (release) default value
    //CONFIG LOADED:ts.alc_tx_postfilt_gain		= ALC_POSTFILT_GAIN_DEFAULT;	// Post-filter added gain default (used for speech processor/ALC)
    //NO INIT NEEDED, SET BEFORE USEts.alc_tx_postfilt_gain_var	= ALC_POSTFILT_GAIN_DEFAULT;	// Post-filter added gain default (used for speech processor/ALC)
    //CONFIG LOADED:ts.tx_comp_level	= 0;					// 0=Release Time/Pre-ALC gain manually adjusted, >=1:  Value calculated by this parameter

    ts.freq_step_config		= 0;				// disabled both marker line under frequency and swapping of STEP buttons

    ts.lcd_backlight_brightness = 0;			// = 0 full brightness
    ts.lcd_backlight_blanking = 0;				// MSB = 1 for auto-off of backlight, lower nybble holds time for auto-off in seconds
    //CONFIG LOADED:ts.low_power_config = LOW_POWER_THRESHOLD_DEFAULT; // add LOW_POWER_THRESHOLD_OFFSET for voltage value

    ts.tune_step		= 0;					// Used for press-and-hold step size changing mode
    ts.frequency_lock	= 0;					// TRUE if frequency knob is locked

    //CONFIG LOADED:ts.tx_disable		= TX_DISABLE_OFF;	    // > 0 if transmitter is to be disabled
    //CONFIG LOADED:ts.flags1			= 0;					// Used to hold individual status flags, stored in EEPROM location "EEPROM_FLAGS1"
    //CONFIG LOADED:ts.flags2			= 0;					// Used to hold individual status flags, stored in EEPROM location "EEPROM_FLAGS2"
    ts.sysclock			= 0;					// This counts up from zero when the unit is powered up at precisely 100 Hz over the long term.  This

    // is NEVER reset and is used for timing certain events.
    ts.version_number_release	= 0;			// version release - used to detect firmware change
    ts.version_number_major = 0;				// version build - used to detect firmware change
    //CONFIG LOADED:ts.cw_offset_mode	= CW_OFFSET_USB_RX;		// CW offset mode (USB, LSB, etc.)
    ts.cw_lsb			= false;				// Flag that indicates CW operates in LSB mode when TRUE
    //CONFIG LOADED:ts.iq_freq_mode		= FREQ_IQ_CONV_MODE_DEFAULT;					// used to set/configure the I/Q frequency/conversion mode
    //CONFIG LOADED:ts.lsb_usb_auto_select	= 0;				// holds setting of LSB/USB auto-select above/below 10 MHz
    ts.last_tuning		= 0;					// this is a timer used to hold off updates of the spectrum scope when an SPI LCD display interface is used
    ts.lcd_blanking_time = 0;					// this holds the system time after which the LCD is blanked - if blanking is enabled
    ts.lcd_blanking_flag = 0;					// if TRUE, the LCD is blanked completely (e.g. backlight is off)
    ts.xvtr_adjust_flag = 0;					// set TRUE if transverter offset adjustment is in process
    //CONFIG LOADED:ts.vfo_mem_mode = 0;						// this is used to record the VFO/memory mode (0 = VFO "A" = backwards compatibility)
    //CONFIG LOADED:ts.voltmeter_calibrate	= POWER_VOLTMETER_CALIBRATE_DEFAULT;	// Voltmeter calibration constant

    // spectrum general settings
    //CONFIG LOADED:ts.spectrum_filter      = SPECTRUM_FILTER_DEFAULT;  // default filter strength for spectrum scope
    //CONFIG LOADED:ts.spectrum_centre_line_colour = SPEC_COLOUR_GRID_DEFAULT;      // color of center line of scope grid
    //CONFIG LOADED:ts.spectrum_freqscale_colour    = SPEC_COLOUR_SCALE_DEFAULT;        // default colour for the spectrum scope frequency scale at the bottom
    //CONFIG LOADED:ts.spectrum_db_scale = DB_DIV_10;               // default to 10dB/division
    //CONFIG LOADED:ts.spectrum_size    = SPECTRUM_SIZE_DEFAULT;        // adjustment for waterfall size
    //CONFIG LOADED:ts.spectrum_agc_rate   = SPECTRUM_SCOPE_AGC_DEFAULT;       // load default spectrum scope AGC rate

    // scope ui settings
    //CONFIG LOADED:ts.scope_trace_colour   = SPEC_COLOUR_TRACE_DEFAULT;        // default colour for the spectrum scope trace
    //CONFIG LOADED:ts.scope_grid_colour    = SPEC_COLOUR_GRID_DEFAULT;     // default colour for the spectrum scope grid
    //CONFIG LOADED:ts.scope_speed      = SPECTRUM_SCOPE_SPEED_DEFAULT;     // default rate of spectrum scope update
    ts.scope_scheduler = 0;             // timer for scheduling the next update of the spectrum update

    //CONFIG LOADED:ts.waterfall.speed  = WATERFALL_SPEED_DEFAULT;      // default speed of update of the waterfall
    //CONFIG LOADED:ts.waterfall.color_scheme = WATERFALL_COLOR_DEFAULT;		// color scheme for waterfall display
    //CONFIG LOADED:ts.waterfall.vert_step_size = WATERFALL_STEP_SIZE_DEFAULT;	// step size in waterfall display
    //CONFIG LOADED:ts.waterfall.contrast = WATERFALL_CONTRAST_DEFAULT;		// contrast setting for waterfall display
    ts.waterfall.scheduler=0;

//    ts.fft_window_type = FFT_WINDOW_DEFAULT;			// FFT Windowing type
    ts.dvmode = false;							        // disable "DV" mode RX/TX functions by default

    ts.txrx_switch_audio_muting_timing = 0;					// timing value used for muting TX audio when keying PTT to suppress "click" or "thump"
    ts.audio_dac_muting_timer = 0;					// timer used for muting TX audio when keying PTT to suppress "click" or "thump"
    ts.audio_dac_muting_flag = 0;					// when TRUE, audio is to be muted after PTT/keyup

    //CONFIG LOADED:ts.filter_disp_colour = FILTER_DISP_COLOUR_DEFAULT;
    ts.vfo_mem_flag = 0;						// when TRUE, memory mode is enabled
    ts.mem_disp = 0;						// when TRUE, memory display is enabled
    //CONFIG LOADED:ts.fm_subaudible_tone_gen_select = 0;				// lookup ("tone number") used to index the table generation (0 corresponds to "tone disabled")
    //CONFIG LOADED:ts.fm_tone_burst_mode = 0;					// this is the setting for the tone burst generator
    ts.fm_tone_burst_timing = 0;					// used to time the duration of the tone burst
    //CONFIG LOADED:ts.fm_sql_threshold = FM_SQUELCH_DEFAULT;			// squelch threshold
    //CONFIG LOADED:ts.fm_subaudible_tone_det_select = 0;				// lookup ("tone number") used to index the table for tone detection (0 corresponds to "tone disabled")

    ts.ser_eeprom_type = 0;						// serial eeprom not present
    ts.configstore_in_use = CONFIGSTORE_IN_USE_FLASH;					// serial eeprom not in use

    ts.tp = &mchf_touchscreen;
    ts.display = &mchf_display;

    ts.show_debug_info = false;					// dont show coordinates on LCD
    //CONFIG LOADED:ts.tune_power_level = 0;					// Tune with FULL POWER
    //CONFIG LOADED:ts.xlat = 0;							// 0 = report base frequency, 1 = report xlat-frequency;
    ts.audio_int_counter = 0;					// test DL2FW
    ts.cat_band_index =255;						// no CAT command arrived


    ts.s_meter = 1;                         // S-Meter configuration, 0 = old school, 1 = dBm-based, 2=dBm/Hz-based
    //CONFIG LOADED:ts.display_dbm = 0;                     // style of dBm display, 0=OFF, 1= dbm, 2= dbm/Hz
    //    ts.dBm_count = 0;                     // timer start
    //CONFIG LOADED:ts.tx_filter = 0;                       // which TX filter has been chosen by the user
    //CONFIG LOADED: ts.iq_auto_correction = 1;              // disable/enable automatic IQ correction

    ts.twinpeaks_tested = TWINPEAKS_WAIT;

    //CONFIG LOADED:ts.dbm_constant = 0;

    ts.i2c_speed[I2C_BUS_1] = I2C1_SPEED_DEFAULT; // Si570, MCP9801
    ts.i2c_speed[I2C_BUS_2] = I2C2_SPEED_DEFAULT; // Codec, EEPROM

    ts.keyer_mode.active = false;
    ts.keyer_mode.button_recording = KEYER_BUTTON_NONE;
    for (int idx = 0; idx<KEYER_BUTTONS; idx++)
    {

    	ts.keyer_mode.macro[idx][0] = '\0';
    	strcpy((char *) ts.keyer_mode.cap[idx], "BTN");

    }
    ts.buffered_tx = false;
    ts.cw_text_entry = false;

    ts.debug_si5351a_pllreset = 2;		//start with "reset on IQ Divider"

    ts.vswr_protection_threshold = 1; // OFF

    //CONFIG LOADED:ts.expflags1 = 0; // Used to hold flags for options in Debug/Expert menu, stored in EEPROM location "EEPROM_EXPFLAGS1"

    ts.band_effective = NULL; // this is an invalid band number, which will trigger a redisplay of the band name and the effective power
}

// #include "Trace.h"
#if 0
void timeTest1()
{
    static uint32_t time = 0;
    if (time != RTC->TR)
    {
        Board_RedLed(LED_STATE_TOGGLE);
        time = RTC->TR;
    }
}
void timeTest()
{
    MchfRtc_Start();
    while (1)
    {
        timeTest1();
    }
}
#endif
// Power on
int mchfMain(void)
{

    ///trace_puts("Hello mcHF World!");
    // trace_printf(" %u\n", 1u);

    // Set default transceiver state
    TransceiverStateInit();

     Board_RamSizeDetection();

#ifdef TESTCPLUSPLUS
    test_call_cpp();
#endif

    // HW init
    Board_InitMinimal();
    // Show logo & HW Info
    UiDriver_StartUpScreenInit();

    if (ts.display != DISPLAY_NONE)
    {
        // TODO: Better indication of non-detected display
        Board_GreenLed(LED_STATE_ON);
    }

    Board_InitFull();

    ConfigStorage_Init();

    // init mchf_touchscreen to see if it is present
    // we don't care about the screen being reverse or not
    // here, so we simply set reverse to false
    UiLcdHy28_TouchscreenInit(0);


    Main_DetectSpecialBootloader();

    UiDriver_Init();


#ifdef STM32F4
    // we now re-init the I2C buses with the configured speed settings. Loading the EEPROM always uses the default speed!
    // we can do this only on the STM32F4 as we are not able to change
    // the speed on the STM32F7/H7 easily via HAL in a portable way
    UhsdrHw_I2C_ChangeSpeed(&hi2c1);
    UhsdrHw_I2C_ChangeSpeed(&hi2c2);
#endif

	profileTimedEventInit();

#ifdef USE_HMC1023
    hmc1023_init();
#endif

    // Audio Software Init
    AudioDriver_Init();

    // Audio Driver Hardware Init
    ts.codec_present = Codec_Reset(ts.samp_rate) == HAL_OK;

    UiDriver_StartupScreen_LogIfProblem(ts.codec_present == false,
            "Audiocodec WM8731 NOT detected!");

    const char* bl_version = Board_BootloaderVersion();

    UiDriver_StartupScreen_LogIfProblem(
            (bl_version[0] == '1' || bl_version[0] == '2' || bl_version[0] == '3' || bl_version[0] == '4')  && bl_version[1] == '.',

                "Upgrade bootloader to 5.0.1 or newer");

    AudioFilter_SetDefaultMemories();


    ts.rx_gain[RX_AUDIO_SPKR].value_old = 0;		// Force update of volume control

#ifdef USE_FREEDV
    FreeDV_Init();
    // we now try to place a marker after last dynamically
    // allocated memory
    Canary_Create();
#endif

    UiDriver_StartUpScreenFinish();

    // We initialize the requested demodulation mode
    // and update the screen accordingly
    UiDriver_SetDemodMode(ts.dmod_mode);

    // Finally, start DMA transfers to get everything going
    UhsdrHwI2s_Codec_StartDMA();


    // now enable paddles/ptt, i.e. external input
    ts.paddles_active = true;

    Board_RedLed(LED_STATE_OFF);

    // Transceiver main loop
    for(;;)
    {
        // UI events processing
        UiDriver_TaskHandler_MainTasks();
    }
    return 0;
}

#else	// H7_M4_CORE

// ------------------------------------------------------------------
// STM32H747 CM4 core baseband main - no UI, no config storage. The
// radio state is uploaded by the M7 core over the ICC link, control
// flow is a CLINT project style superloop
// ------------------------------------------------------------------

#include "main.h"
#include <stdio.h>

#include "uhsdr_board.h"
#include "audio_driver.h"
#include "audio_filter.h"
#include "audio_agc.h"

#include "drivers/audio/audio_management.h"

#include "drivers/icc/icc_proc.h"
#include "drivers/icc/icc_radio_if.h"
#include "drivers/icc/icc_spectrum.h"

// Transceiver state public structure
__IO TransceiverState ts;
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

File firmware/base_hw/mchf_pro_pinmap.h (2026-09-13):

/************************************************************************************
**                                                                                 **
**                                 mcHF QRP Transceiver                            **
**                         Krassi Atanassov - M0NKA, 2013-2026                     **
**                                                                                 **
**---------------------------------------------------------------------------------**
**                                                                                 **
**  File name:                                                                     **
**  Description:                                                                   **
**  Last Modified:                                                                 **
**  Licence:			https://github.com/m0nka/mcHF/blob/main/LICENSE            **
************************************************************************************/
#ifndef __MCHF_PRO_PINMAP_H
#define __MCHF_PRO_PINMAP_H

#ifdef PCB_V9_REV_A
// Changes:	CODEC_RESET 	= PD4
//			SD_DET 			= PB0
//			GPS_EN 			= PB1
//			BT_EN 			= PB5
//			ON_LED			= PB11
//			KEYPAD_Y1		= PD6
//			BT_COMM_STAT	= PG13
//			PADDLE_DIT		= PE2
//			SDRAM_A12		= PG2
//			GPS_RX			= PG9
//			GPS_TX			= PG14
//			KEYPAD_Y2		= PI8
//			KEYPAD_Y3		= PI11
//
//
// ----------------------------------------------------
// ----------------------------------------------------
// PortA

// PA0			not in use
//...

// PA1			ENC1_I
#define ENC1_I							GPIO_PIN_1
#define ENC1_I_PORT						GPIOA

// PA2			LORA_POWER, Lora driver
#define LORA_POWER						LL_GPIO_PIN_2
#define LORA_POWER_PORT					GPIOA
//#define LORA_POWER_INV

// PA3			(ex RFM_DIO2), Lora driver
#define LORA_NRST						GPIO_PIN_3
#define LORA_NRST_PORT					GPIOA

// PA4			DAC1_OUT1
#define DAC1_OUT1						GPIO_PIN_4
#define DAC1_OUTX_PORT					GPIOA

// PA5			DAC1_OUT2
#define DAC1_OUT2						GPIO_PIN_5

// PA6			LORA_MISO_SPI1, Lora driver
#define LORA_MISO_SPI1					LL_GPIO_PIN_6
#define LORA_MISO_SPI1_PORT				GPIOA

// PA7			LORA_MOSI_SPI1, Lora driver
#define LORA_MOSI_SPI1					LL_GPIO_PIN_7
#define LORA_MOSI_SPI1_PORT				GPIOA

// PA8			GPS_PPS input, exti
#define GPS_PPS_PIN               		GPIO_PIN_8
#define GPS_PPS_PORT         			GPIOA
#define GPS_PPS_AF         				LL_GPIO_AF_1

// PA9			LCD_BL_CTRL (TIM1_CH2)
#define LCD_BL_CTRL_PIN               	GPIO_PIN_9
#define LCD_BL_CTRL_GPIO_PORT         	GPIOA
#define LCD_BL_CTRL_AF         			LL_GPIO_AF_1
#define LCD_BL_CTRL_TIM_CH				LL_TIM_CHANNEL_CH2

// PA10			FAN_ON
#define FAN_CNTR						LL_GPIO_PIN_10
#define FAN_CNTR_PORT					GPIOA

// ToDo: Allocate to DSP core for rig control and real time audio streaming
// PA11			USB_DFU_N
// PA12			USB_DFU_P

// Programming port only
// PA13			SWDIO
// PA14			SWCLK

// PA15			ENC1_Q
#define ENC1_Q							GPIO_PIN_15
#define ENC1_Q_PORT						GPIOA

// ----------------------------------------------------
// ----------------------------------------------------
// PortB

// PB0			SD_DET
#define SD_DET                   		GPIO_PIN_0
#define SD_DET_PORT              		GPIOB

// PB1			BST_EN -> ToDo: BMS step-up converter enable
#define GPS_EN_PIN	               		GPIO_PIN_1
#define GPS_EN_PORT         			GPIOB

// PB2			ATT_CLK, Attenuator
#define ATT_CLK               			LL_GPIO_PIN_2
#define ATT_CLK_PORT         			GPIOB

// PB3			LORA_SCK_SPI1, Lora driver
#define LORA_SCK_SPI1               	LL_GPIO_PIN_3
#define LORA_SCK_SPI1_PORT         		GPIOB

// PB4			ENC2_I
#define ENC2_I_PIN               		GPIO_PIN_4
#define ENC2_I_PORT               		GPIOB

// PB5
#define BT_EN_PIN                   	LL_GPIO_PIN_5
#define BT_EN_PORT               		GPIOB
#define BT_EN_INV

// PB6			TOUCH_SCK_I2C1
#define TOUCH_SCK_SCL_PIN              	GPIO_PIN_6
#define TOUCH_SCK_SCL_GPIO_PORT      	GPIOB
#define TOUCH_SCK_SCL_AF             	GPIO_AF4_I2C4

// PB7			TOUCH_SDA_I2C1
#define TOUCH_SDA_SDA_PIN             	GPIO_PIN_7
#define TOUCH_SDA_SDA_AF                GPIO_AF4_I2C4
#define TOUCH_SDA_SDA_GPIO_PORT         GPIOB

// PB8			CODEC_SCL_I2C4
#define CODEC_SCL_I2C4_PIN             	GPIO_PIN_8
#define CODEC_SCL_I2C4_PORT           	GPIOB
#define CODEC_SCL_I2C4_AF            	GPIO_AF6_I2C4

// PB9			CODEC_SDA_I2C4
#define CODEC_SDA_I2C4_PIN           	GPIO_PIN_9
#define CODEC_SDA_I2C4_PORT          	GPIOB
#define CODEC_SDA_I2C4_AF            	GPIO_AF6_I2C4

// PB10			ATT_LE, latch enable, Attenuator
#define ATT_LE							LL_GPIO_PIN_10
#define ATT_LE_PORT            			GPIOB

// PB11			DSI_TE - reserved, future use
#define ON_LED							LL_GPIO_PIN_11
#define ON_LED_PORT            			GPIOB

// PB12			PTT
#define PTT_PIN							GPIO_PIN_12
#define PTT_PIN_PORT            		GPIOB

// PB13			VCC_5V_ON
#define VCC_5V_ON						GPIO_PIN_13
#define VCC_5V_ON_PORT            		GPIOB
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

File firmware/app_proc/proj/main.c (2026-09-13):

/************************************************************************************
**                                                                                 **
**                                 mcHF QRP Transceiver                            **
**                         Krassi Atanassov - M0NKA, 2013-2026                     **
**                                                                                 **
**---------------------------------------------------------------------------------**
**                                                                                 **
**  File name:                                                                     **
**  Description:                                                                   **
**  Last Modified:                                                                 **
**  Licence:			https://github.com/m0nka/mcHF/blob/main/LICENSE            **
************************************************************************************/
#include "mchf_pro_board.h"
#include "main.h"

#ifdef CONTEXT_MESHCHAT
// Not pulled in by main.h - the meshcore headers carry <stdbool.h>,
// which would collide with the project's own bool typedef everywhere
#include "meshchat_proc.h"
#endif

// Reserved FreeRTOS heap memory
#if configAPPLICATION_ALLOCATED_HEAP == 1
__attribute__((section(".axi_mem"))) uint8_t ucHeap[configTOTAL_HEAP_SIZE];
#endif

// UI process
extern struct	UI_DRIVER_STATE			ui_s;

// DSP core state
struct TransceiverState 				ts;

// FreeRTOS process state
struct PROC_STATE 						ps;

// App Loader messaging(inherited from Genie code)
APPLOADER_QUEUE_PARAMETERS 				pxAppLoaderParameters;

//*----------------------------------------------------------------------------
//* Function Name       : NMI_Handler
//* Object              :
//* Notes    			:
//* Notes   			:
//* Notes    			:
//* Context    			: CONTEXT_RESET
//*----------------------------------------------------------------------------
void NMI_Handler(void)
{
	Error_Handler(11);
}

//*----------------------------------------------------------------------------
//* Function Name       : HardFault_Handler
//* Object              :
//* Notes    			:
//* Notes   			:
//* Notes    			:
//* Context    			: CONTEXT_RESET
//*----------------------------------------------------------------------------
void HardFault_Handler(void)
{
	// Exception frame of the faulting context. Tasks run on the process
	// stack, so for anything faulting inside a task this is the frame
	// the core pushed on entry - sp[6] is the instruction that faulted,
	// which is what to feed to arm-none-eabi-addr2line
	uint32_t	*sp = (uint32_t *)__get_PSP();

	printf( "====================\r\n");
	printf( "=    HARD FAULT    =\r\n");
	printf( "=       [%s]      =\r\n", pcTaskGetName(NULL));
	printf( "====================\r\n");

	printf( "hfsr %08x cfsr %08x \r\n", (unsigned int)SCB->HFSR, (unsigned int)SCB->CFSR);
	printf( "bfar %08x mmfar %08x \r\n", (unsigned int)SCB->BFAR, (unsigned int)SCB->MMFAR);
	printf( "pc   %08x lr    %08x \r\n", (unsigned int)sp[6], (unsigned int)sp[5]);
	printf( "r0   %08x r1    %08x \r\n", (unsigned int)sp[0], (unsigned int)sp[1]);
	printf( "r2   %08x r3    %08x r12 %08x \r\n",
			(unsigned int)sp[2], (unsigned int)sp[3], (unsigned int)sp[4]);
	printf( "psr  %08x \r\n", (unsigned int)sp[7]);

	// The faulting function's own frame sits directly above the
	// exception frame the core just pushed. Dumping it recovers the
	// arguments and locals the fault took with it - for the emWin
	// WM__Paint fault that is the window handle it was given, stored at
	// its sp+12, which names the window that no longer exists
	{
		int	i;

		printf( "frame ");

		for(i = 8; i < 24; i++)
			printf("%08x ", (unsigned int)sp[i]);

		printf(" \r\n");
	}

	// Give the UART time to drain before the reset cuts it off
	for(volatile int i = 0; i < 4000000; i++)
		__asm("nop");

	#if 1
	NVIC_SystemReset();
	#else
	//HAL_GPIO_WritePin(LCD_BL_CTRL_GPIO_PORT, LCD_BL_CTRL_PIN, GPIO_PIN_RESET);
	LL_GPIO_ResetOutputPin(POWER_HOLD_PORT, POWER_HOLD);
	#endif

	while(1)
	{
		__asm("nop");
	}
}

//*----------------------------------------------------------------------------
//* Function Name       : MemManage_Handler
//* Object              :
//* Notes    			:
//* Notes   			:
//* Notes    			:
//* Context    			: CONTEXT_RESET
//*----------------------------------------------------------------------------
void MemManage_Handler(void)
{
	Error_Handler(13);
}

//*----------------------------------------------------------------------------
//* Function Name       : BusFault_Handler
//* Object              :
//* Notes    			:
//* Notes   			:
//* Notes    			:
//* Context    			: CONTEXT_RESET
//*----------------------------------------------------------------------------
void BusFault_Handler(void)
{
	Error_Handler(14);
}

//*----------------------------------------------------------------------------
//* Function Name       : UsageFault_Handler
//* Object              :
//* Notes    			:
//* Notes   			:
//* Notes    			:
//* Context    			: CONTEXT_RESET
//*----------------------------------------------------------------------------
void UsageFault_Handler(void)
{
	Error_Handler(15);
}

//*----------------------------------------------------------------------------
//* Function Name       : DebugMon_Handler
//* Object              :
//* Notes    			:
//* Notes   			:
//* Notes    			:
//* Context    			: CONTEXT_RESET
//*----------------------------------------------------------------------------
void DebugMon_Handler(void)
{
}

//*----------------------------------------------------------------------------
//* Function Name       : SysTick_Handler
//* Object              :
//* Notes    			:
//* Notes   			:
//* Notes    			:
//* Context    			: CONTEXT_RESET
//*----------------------------------------------------------------------------
void SysTick_Handler(void)
{
	// Local timers
	(ps.epoch)++;

	// Os Tick
	osSystickHandler();

	// Hal tick
	#ifndef USE_SEPARATE_TIMER_FOR_HAL
	HAL_IncTick();
	#endif
}
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

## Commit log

2024-02-18 add block diagrams
    [block_v6.SchDoc, block_v8.SchDoc, block_v9.SchDoc]
2024-02-18 add boards schematics
    [AdcDacBoard.PrjPcb, AtuBoard.PrjPcb, AudioBoard.PrjPcb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]
2024-02-22 add sub versions
    [AdcDacBoard6.PrjPcb, AudioBoard6.PrjPcb, LogicBoard6.PrjPcb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]
2024-02-22 last few projects added
    [BpfBoard6.PrjPcb, LpfBoard6.PrjPcb, PaBoard6.PrjPcb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]
2024-02-22 fix v6 UI
    [PowerBoard6.PrjPcb, logic6_front.SchDoc, power6.SchDoc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]
2024-02-22 ui routing
    [adc_dac_main6.SchDoc, logic6_front.SchDoc, logic6_main.SchDoc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]
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2024-02-23 copy mcHFPro boards
    [AdcDacBoard.PrjPcb, AdcDacBoard6.PrjPcb, AtuBoard.PrjPcb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]
2024-02-24 ui pcb updates
    [mcHFPro_ui.PrjPcb, ui_audio.SchDoc, ui_conn.SchDoc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]
2024-02-24 pcb upd
    [mchf_pro_ui.PcbDoc]
2024-02-25 fix CPU wiring
    [mcHFPro_ui.PrjPcb, mchf_pro_ui.PcbDoc, ui_audio.SchDoc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]
2024-02-25 re-arrange modules
    [mchf_pro_ui.PcbDoc, ui_debug.SchDoc, ui_lcd.SchDoc]
2024-02-27 add connectors
    [mchf_pro_ui.PcbDoc, ui_conn.SchDoc, ui_main.SchDoc]
2024-02-28 wire LO and audio connector
    [mchf_pro_ui.PcbDoc, ui_conn.SchDoc]
2024-02-29 rf board
    [mcHFPro_rf.PrjPcb, mchf_pro_rf.PcbDoc, mchf_pro_ui.PcbDoc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]
2024-03-01 friday wrapup
    [mchf_pro_rf.PcbDoc, mchf_pro_ui.PcbDoc, rf_conn.SchDoc]
2024-03-07 logic board layout
    [mcHFPro_ui.PrjPcb, mchf_pro_rf.PcbDoc, mchf_pro_ui.PcbDoc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]
2024-03-08 fix rf board size
    [AdcDacBoard.PrjPcb, AdcDacBoard6.PrjPcb, AtuBoard.PrjPcb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]
2024-03-09 battery and fan footprints
    [mcHFPro_rf.PrjPcb, mcHFPro_ui.PrjPcb, mchf_pro_rf.PcbDoc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]
2024-03-10 rf pcb routing
    [mchf_pro_rf.PcbDoc, mchf_pro_ui.PcbDoc, rf_bms.SchDoc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]
2024-03-11 cpu free pins
    [mcHFPro_ui.PrjPcb, mchf_pro_ui.PcbDoc, ui_conn.SchDoc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]
2024-03-12 mix board
    [mchf_pro_mix.PcbDoc, mchf_pro_mix.PrjPCB, mchf_pro_rf.PcbDoc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]
2024-03-13 power supply, ui
    [mchf_pro_rf.PcbDoc, mchf_pro_ui.PcbDoc]
2024-03-14 add bms chip
    [mcHFPro_rf.PrjPcb, mchf_pro_rf.PcbDoc, rf_bms.SchDoc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]
2024-03-15 bms wiring
    [mchf_pro_rf.PcbDoc, rf_bms.SchDoc, rf_conn.SchDoc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]
2024-03-16 usb-pd trig chip
    [mchf_pro_rf.PcbDoc, rf_bms.SchDoc, rf_main.SchDoc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]
2024-03-21 heatsink footprint
    [mchf_pro_rf.PcbDoc, rf_conn.SchDoc, rf_tx_pa.SchDoc]
2024-03-22 connections board to board
    [mchf_pro_mix.PcbDoc, mchf_pro_rf.PcbDoc, mchf_pro_ui.PcbDoc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]
2024-03-23 mix board shape/ui links
    [mchf_pro_mix.PcbDoc, mchf_pro_rf.PcbDoc, mchf_pro_ui.PcbDoc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]
2024-03-28 daily update
    [mchf_pro_rf.PcbDoc, mchf_pro_ui.PcbDoc]
2024-03-30 bt audio add
    [mcHFPro_ui.PrjPcb, mchf_pro_ui.PcbDoc, ui_bt_audio.SchDoc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]
2024-03-30 some wiring
    [mchf_pro_ui.PcbDoc, ui_bt_audio.SchDoc, ui_cpu.SchDoc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]
2024-03-31 ui wiring 2
    [mcHFPro_ui.PrjPcb, mchf_pro_ui.PcbDoc, ui_audio.SchDoc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]
2024-04-04 fan switch footprint
    [mcHFPro_ui.PrjPcb, mchf_pro_mix.PcbDoc, mchf_pro_rf.PcbDoc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]
2024-04-05 3v regulator
    [mcHFPro_ui.PrjPcb, ui_cpu_power.SchDoc, ui_ext_conn.SchDoc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]
2024-04-06 audio pa wiring
    [mcHFPro_ui.PrjPcb, ui_audio.SchDoc]
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2024-04-10 wire rf conn
    [mchf_pro_rf.PcbDoc, ui_conn.SchDoc, ui_lo.SchDoc]
2024-04-11 ui wired
    [mcHFPro_ui.PrjPcb, mchf_pro_rf.PcbDoc, ui_cpu.SchDoc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]
2024-04-12 ui fixes
    [mchf_pro_rf.PcbDoc, rf_lpf.SchDoc, ui_bt_audio.SchDoc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]
2024-04-13 wire lpf
    [mcHFPro_rf.PrjPcb, mchf_pro_rf.PcbDoc, rf_tx_pa.SchDoc]
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2024-04-21 usb pd connector footprint
    [mcHFPro_rf.PrjPcb, mchf_pro_rf.PcbDoc, rf_bms.SchDoc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]
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2024-04-24 new mix board connector
    [mchf_pro_mix.PcbDoc, mchf_pro_rf.PcbDoc, mchf_pro_ui.PcbDoc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]
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2024-05-06 ui solved DRC
    [ui_lo.SchDoc]
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2024-05-20 solidworks panels/extra design files
    [side_left.SLDPRT, side_left.STL, side_right.SLDPRT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]
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2024-07-08 back up 0.8.4 files
    [mcHFPro_rf.PrjPcb, mcHFPro_ui.PrjPcb, mchf_pro_mix.PcbDoc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]
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2024-07-11 fix pin map
    [mcHFPro_rf.PrjPcb]
2024-07-12 add clint dsp core
    [mcHFPro_rf.PrjPcb]
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2024-07-19 fix gui hard fault
    [mchf_pro_board.c, mchf_pro_board.h, proc_conf.h]
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2024-08-13 fix touch i2c
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2024-08-25 fix mechanical
    [side_left.STL, side_right.STL]
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2024-09-08 pcb v6 Altium project
    [mcHF_rf.PrjPCB, mcHF_ui.PrjPCB, rf_bpf.SchDoc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]
2024-09-08 back up for somewhat working config
    [7.gg.csv]
2024-09-10 extra bms fixes
    [10.gg.csv]
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2024-10-02 add front panel dir
    [front_panel_0.1.SLDPRT, front_panel_0.2.SLDPRT, front_panel_0.3.SLDPRT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]
2024-10-05 reached status 0x05 with lychen cells
    [1.gg.csv, 10.gg.csv, 3.gg.csv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]
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2024-10-07 panel fixes
    [side_left.SLDPRT, side_right.SLDPRT]
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2024-10-17 status 06 file and back panel
    [back.SLDPRT, lychen_L06.gg.csv, side_left.SLDPRT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]
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2024-10-29 add bambu proj files
    [back.3mf, both.3mf, front_panel_0.8.3mf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]
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2024-10-31 usb conn fix
    [mchf_pro_rf.PcbDoc]
2024-11-01 battery footprint fixes
    [mchf_pro_rf.PcbDoc, rf_bms.SchDoc]
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2024-11-02 pa fixes
    [mchf_pro_rf.PcbDoc, rf_conn.SchDoc, rf_tx_pa.SchDoc]
2024-11-03 small fixes
    [mchf_pro_rf.PcbDoc, rf_conn.SchDoc, rf_smps.SchDoc]
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2024-11-16 wire codec new position
    [ui_bt_audio.SchDoc]
2024-11-17 replace LORA module
    [mchf_pro_rf.PcbDoc, ui_bt_audio.SchDoc, ui_lora.SchDoc]
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2024-11-17 rewire bms i2c and usb-c programming changes
    [ui_bt_audio.SchDoc, ui_codec.SchDoc, ui_conn.SchDoc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]
2024-11-18 fix side buttons
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2024-11-20 fix ui gerber
    [mcHFPro_rf.PrjPcb]
2024-12-19 first errors
    [mcHFPro_ui.PrjPcb]
2024-12-23 new front panel with supports
    [front_panel_0.8.3mf, front_panel_0.8.SLDPRT]
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2024-12-26 add connector ids to sch
    [front_panel_0.8.3mf, front_panel_0.8.SLDPRT, rf_conn.SchDoc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]
2025-01-02 changes and errors
    [rf_conn.SchDoc]
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2025-01-20 fix back plate
    [back.3mf, back.SLDPRT]
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2025-01-27 bt connect event to mute audio PA
    [ui_audio.SchDoc]
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2025-02-09 prototype extra pa controls
    [back.3mf, back.SLDPRT, back.STL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]
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2025-02-13 adc3 int channels add
    [cap.3mf, cap.SLDPRT, cap.STL]
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2025-02-15 adc dma option and stand
    [back.3mf, back.SLDPRT, back.STL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]
2025-02-16 add adc polling option
    [stand.SLDPRT, stand.STL]
2025-02-16 stand support on the back cover
    [back.3mf, back.SLDPRT, back.STL]
2025-02-17 add stand to back body
    [back.SLDPRT, stand.SLDPRT]
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2025-02-21 adc3 works in polling mode(somewhat) and portF multiplexer routing fix
    [adc.c, adc.h, main.c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]
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2025-04-13 skip LCD print
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2025-05-03 fix lcd issue caused by STM32Cube_FW_H7_V1.12.0 release
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2025-05-04 note on rf board error
    [main.c]
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2025-05-16 fix RTC year tracking and setup
    [main.c, rtc.c]
2025-05-17 fix onscreen battery control
2025-05-24 rework load/save of system state
    [main.c, mchf_pro_board.c, mchf_pro_board.h]
2025-05-26 vfo switching fixed/batt control aware of usb voltage
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2025-06-30 shielding cans mechanical layout
    [mchf_pro_mix.PcbDoc]
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2025-07-13 stall application core firmware
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2025-08-09 add fixed
    [mchf_pro_mix.PrjPCB, mix_rxd.SchDoc]
2025-08-22 fix 3.5inch lcd rotation
    [hw_lcd.c]
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2025-10-17 fix bms menu
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2025-11-23 various fixes on sd drivers
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2025-12-16 fix SD read in DMA mode
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2026-01-03 fix HAL timer option
    [board.c, proc_conf.h, sdram.c]
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2026-01-03 fix badly defined pins
    [mchf_pro_board.c, mchf_pro_pinmap.h]
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2026-01-24 fix fan during charging
    [main.c]
2026-01-24 fix fan off in CV mode
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2026-02-28 fix charge current write
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2026-04-03 fix rogue keyboard irq
    [board.c, main.c, mchf_pro_board.h]
2026-04-03 swap keyboard lines to allow proper exti scan
    [main.c, mchf_pro_board.c, mchf_pro_pinmap.h]
2026-04-03 fix CPU status control
    [mchf_pro_board.h]
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2026-05-09 GPS low noise test mode
    [proc_conf.h]
2026-05-09 set clock on unstable lock
    [main.c, proc_conf.h]
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2026-05-25 v9 rev B sch
    [block_v6.SchDoc, block_v8.SchDoc, block_v9.SchDoc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]
2026-06-13 fix up wip baseband for gcc14
    [main.h]
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2026-07-02 fix up work parameters
    [uhsdr_main.c]
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2026-07-04 fix locking/cpu max usage issue
    [adc.c]
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2026-07-14 fix SD card driver: DMA-unreachable buffers, broken slow path, out of spec clock
    - SD_write fast path now requires an AXI ram buffer like SD_read does;
    FatFS internal sector buffers live in DTCM (.bss), which the SDMMC
    IDMA cannot read - every wspr capture f_close died with a TX FIFO
    underrun and truncated the file at the last f_sync boundary
    - SD_write slow path rewritten: old code DMA'd the stale scratch buffer
    to the card and memcpy'd backwards over the caller's data
    - cache invalidate before DMA write replaced with a clean (invalidate
    discarded dirty lines)
    - SDMMC clock 30 MHz -> 20 MHz: card runs in default speed mode (no
    CMD6 switch), spec max is 25 MHz; the overclock caus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
2026-07-14 debug.bat: fix Realterm capture switch crash
    capture=<file> starts capturing without a valid file handle and dies
    with an access violation on the first received byte - the file name
    belongs in capfile=, capture is a bare start switch.
2026-07-14 wspr: live decoder feed + slot deadline, no more skipped rx cycles
    Feed the decoder front end (mix + decimate to 375 Hz) incrementally as
    capture chunks drain from the staging ring, so the heavy decode starts
    right at capture end - reading the 2.7 MB capture back from SD first
    cost ~3.5 s. The SD copy is archival only now, a write failure no
    longer kills the cycle.
    Bound the decode pass with a caller-owned deadline hook, polled between
    candidates (sorted strongest first): a noise candidate can burn the
    whole Fano cycle budget and push the pass from 4.4 to 7.5 s, past the
    ~5.8 s gap to the next even-minute arm point. Only the weakest
    candidates are dropped on a tight cycle.
    Verified on hard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
2026-07-18 rework project structure
    [MCHF.cfg, front.dxf, ovi40.cfg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]
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2026-07-31 TX LED off fix
    [main.h]
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2026-07-31 adjust for gps pin swap in driver
    [mchf_pro_pinmap.h, proc_conf.h]
2026-08-05 fix missing defines for rev B port
    [mchf_pro_board.c]
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2026-08-05 bug fix on bms power off
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2026-08-18 partial fix for backlight timer de-init
    [mchf_pro_pinmap.h]
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2026-08-23 fix keyboard hw support
    [main.c]
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2026-09-12 direct messages support and various bugfixes/bringup
    [main.c]
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

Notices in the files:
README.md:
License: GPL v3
